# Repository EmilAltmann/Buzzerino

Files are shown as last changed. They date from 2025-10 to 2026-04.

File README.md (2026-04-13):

# Buzzerino

This is the repository of the soldering kit by the Digital Technology Group at the University of Kassel.



The contents of this document:
* [Soldering Instructions](#soldering-instructions)
* [Flashing](#flashing)
* [Example Programs](#example-programs)
* [How to Code / Work with AI](#how-to-code-and-work-with-ai)
* [Parts and Wiki](#parts-and-wiki)

## Soldering Instructions

We created a short video about the assembly process:

<a href="http://www.youtube.com/watch?feature=player_embedded&v=cFA2UIF0SY8?si=ucTLQL97WAnX6xTo
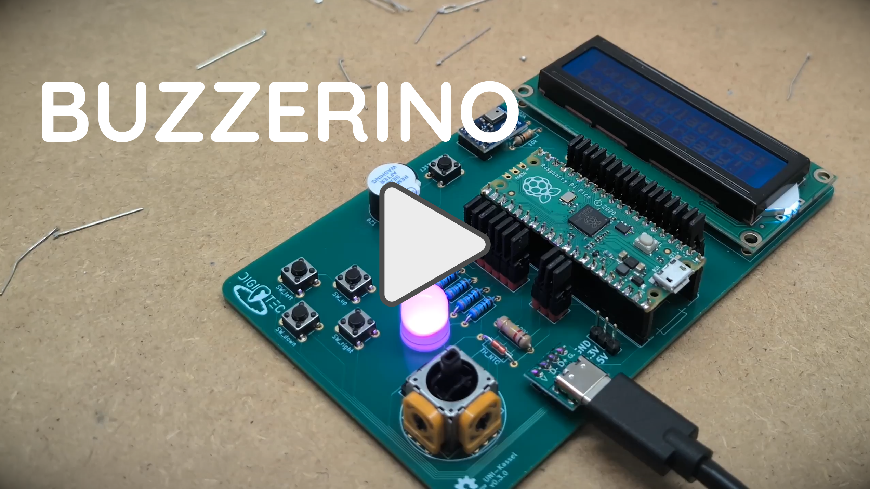
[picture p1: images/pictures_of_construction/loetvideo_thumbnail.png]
Assembly Video
" target="_blank"></a>

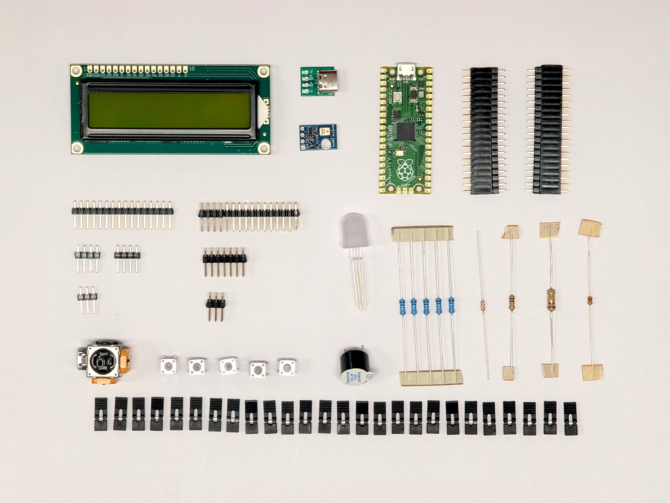
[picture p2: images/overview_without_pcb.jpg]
Parts of the Buzzerino.


### Bill of Materials
Please check if you have all the necessary components listed below:
* 1x Buzzerino circuit board (Buzzerino PCB)
* 1x Raspberry Pi Pico
* 1x 1602A LCD display
* 1x AHT10 digital temperature and humidity sensor
* 1x USB-C breakout board
* 1x 10 mm RGB LED
* 1x buzzer
* 1x analogue joystick
* 5x 6 mm push buttons
* 1x 100 kΩ NTC temperature-dependent resistor
* 5x 330 Ω resistors
* 1x 1 kΩ resistor
* 1x 10 kΩ resistor
* 1x 120 kΩ resistor
* 2x 1x20 pin headers and sockets (keep them plugged together)
* 1x 1x16 pin header
* 2x 1x4 pin headers
* 1x 1x3 pin header
* 1x 2x16 pin header
* 1x 2x7 pin header
* 1x 2x3 pin header
* 26x jumper

### Assembly of the Raspberry Pi Pico

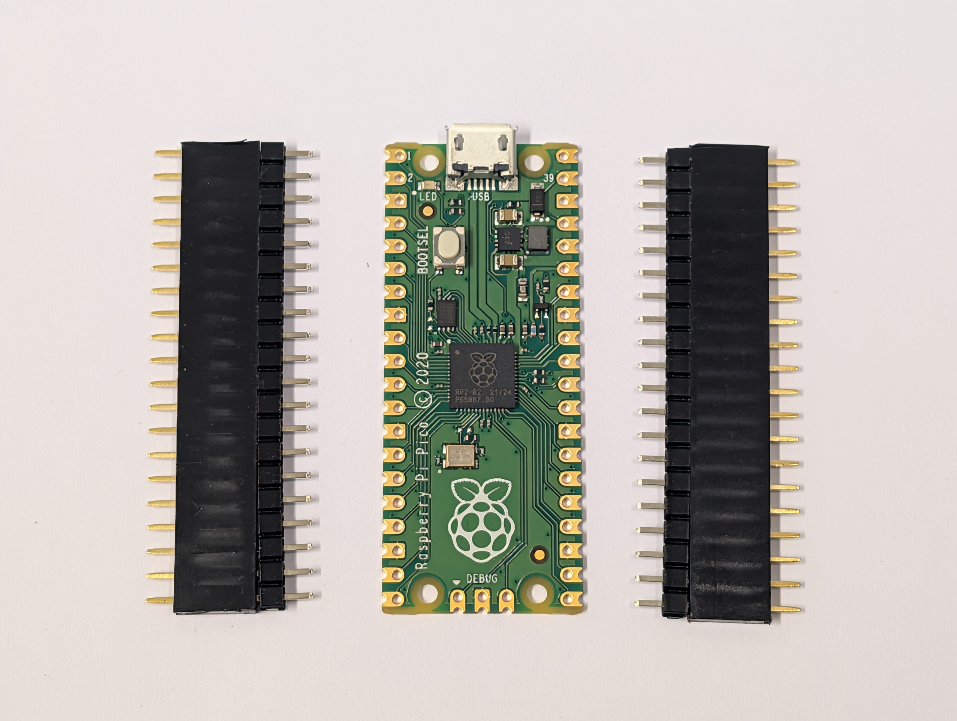
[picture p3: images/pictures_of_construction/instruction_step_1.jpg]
Raspberry Pi Pico and pin strips.


We will start by soldering the two 1x20 pin headers and sockets to the Raspberry Pi Pico board. The pin strips are each two parts plugged together; keep them together, as this will keep the contacts aligned! The side with the slimmer plastic piece will be soldered to the Raspberry Pi Pico (in the picture above, the inner one).

Start by putting the pin headers into the Raspberry Pi Pico and the Buzzerino PCB. The Raspberry Pi Pico should sit flat and parallel on both pin strips.

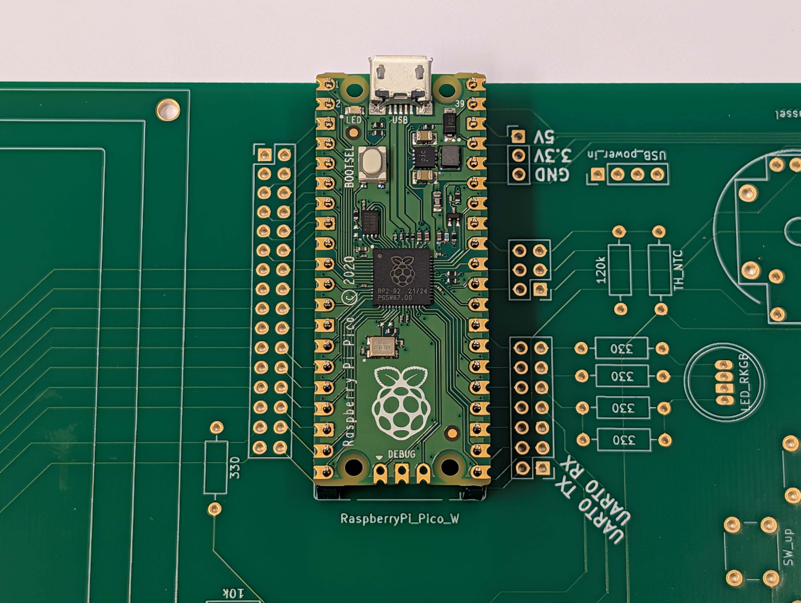
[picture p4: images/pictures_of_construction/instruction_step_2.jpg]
Raspberry Pi Pico sitting loosely on pin strips.


Now we can solder our first connections. Heat one of the corner pins with your soldering iron. Check with solder whether the joint is up to temperature by gently feeding it into the heated pin. If the solder melts, you can remove the soldering iron and let the connection cool down.

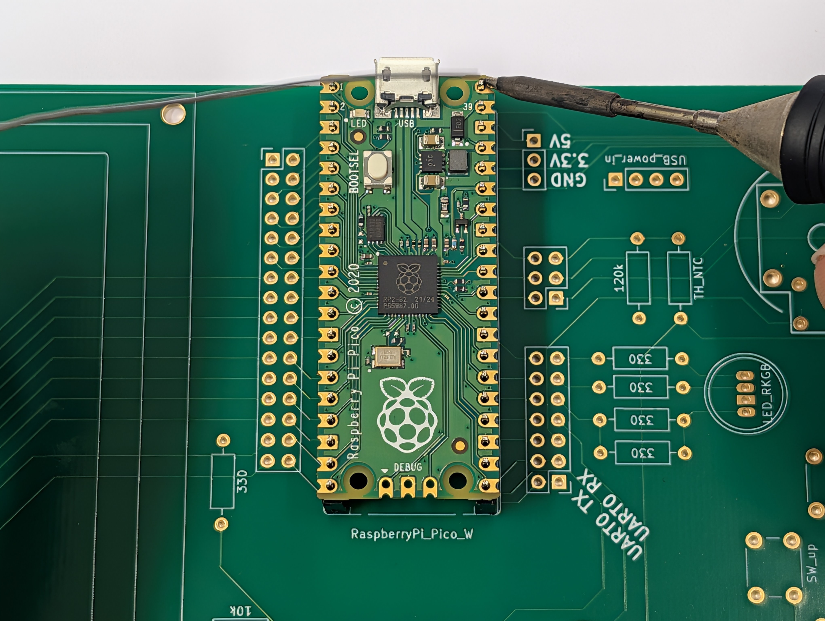
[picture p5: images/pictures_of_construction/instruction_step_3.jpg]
Example of soldering a pin from the Raspberry Pi Pico.


Continue by soldering the three other corners.

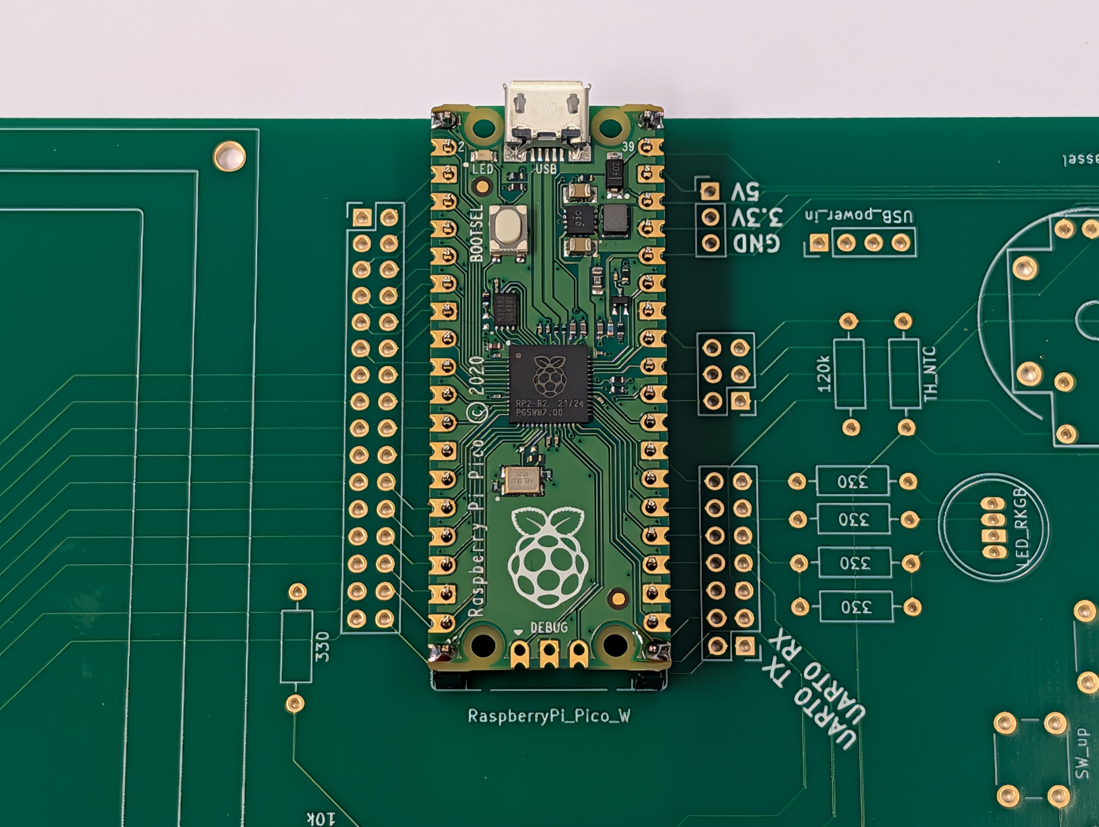
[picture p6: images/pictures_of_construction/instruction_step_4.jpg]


Now you can remove the Raspberry Pi Pico from the Buzzerino PCB (with the pin headers still together).

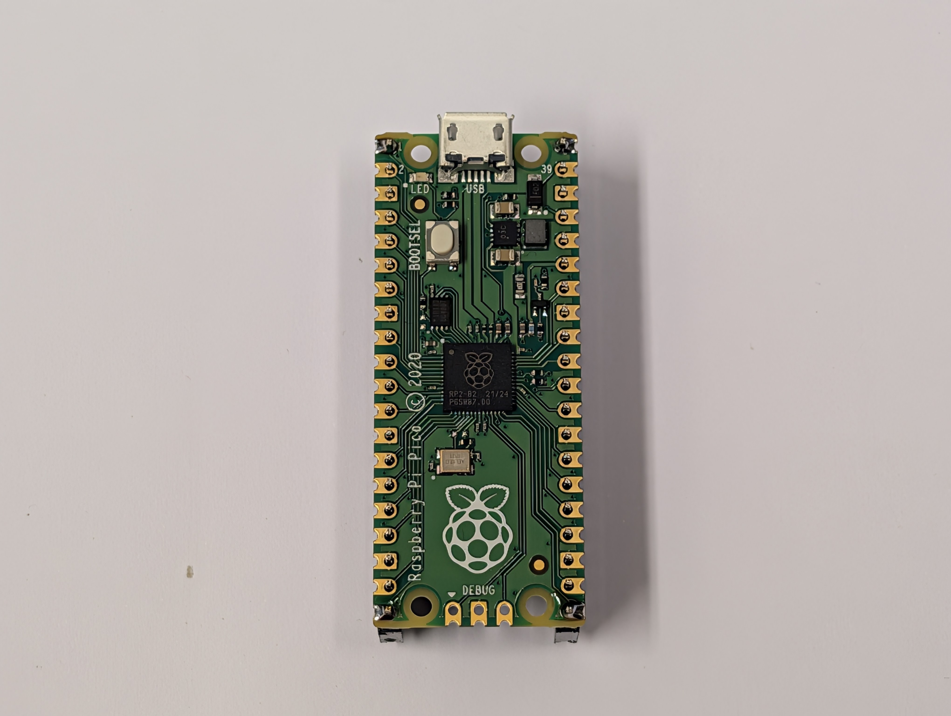
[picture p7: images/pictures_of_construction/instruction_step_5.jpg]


With the Raspberry Pi Pico now free, but the pin strips still attached to it, you can fully solder both sides.

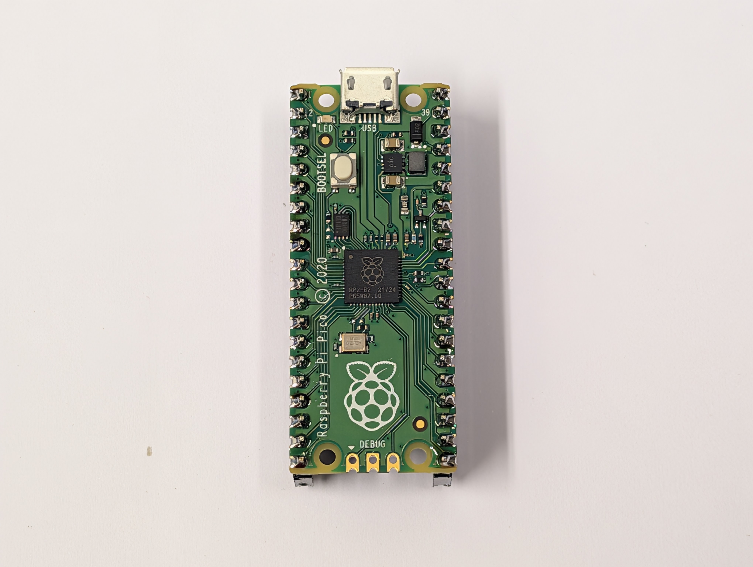
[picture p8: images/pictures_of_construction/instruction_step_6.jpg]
Fully soldered Raspberry Pi Pico.


### Assembly of the USB-C breakout board

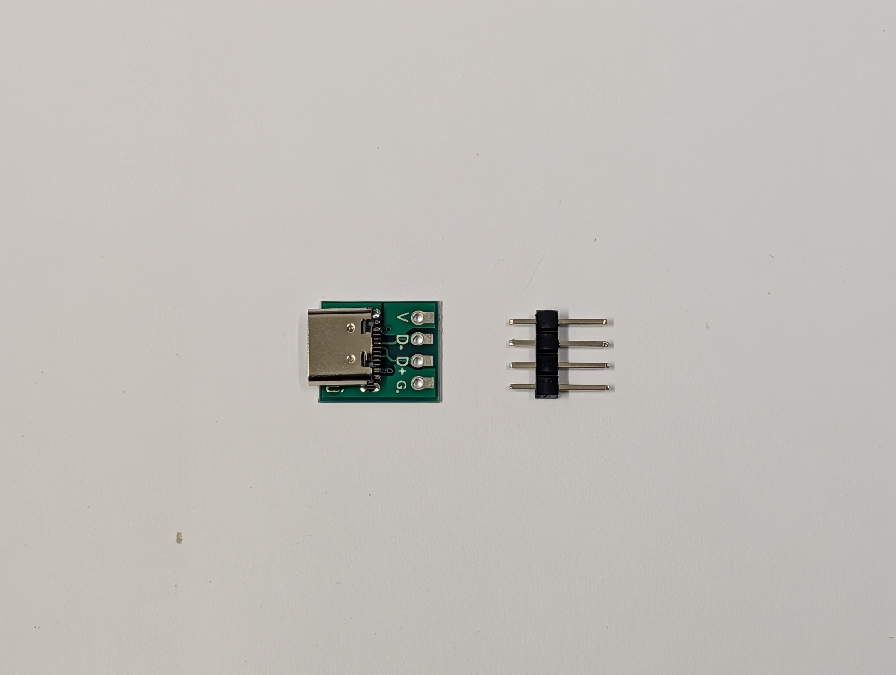
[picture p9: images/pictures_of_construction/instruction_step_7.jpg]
USB-C breakout board and 1x4 pin header.


Now we will solder the 1x4 pin header to the USB-C breakout board. Because both pieces are very small, it's a good tactic to plug them together and place them on your table.

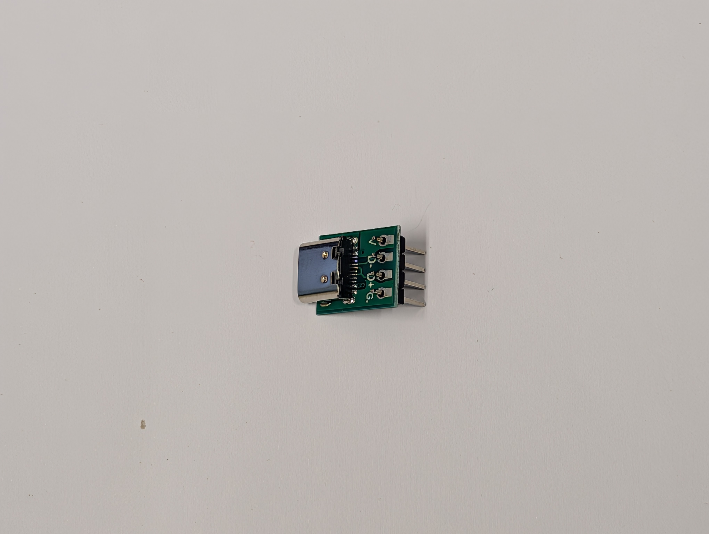
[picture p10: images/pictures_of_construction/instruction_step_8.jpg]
USB-C breakout board and 1x4 pin header loosely plugged together.


Start by soldering only one pin, as the angle between the board and the pin header will likely be slightly crooked.

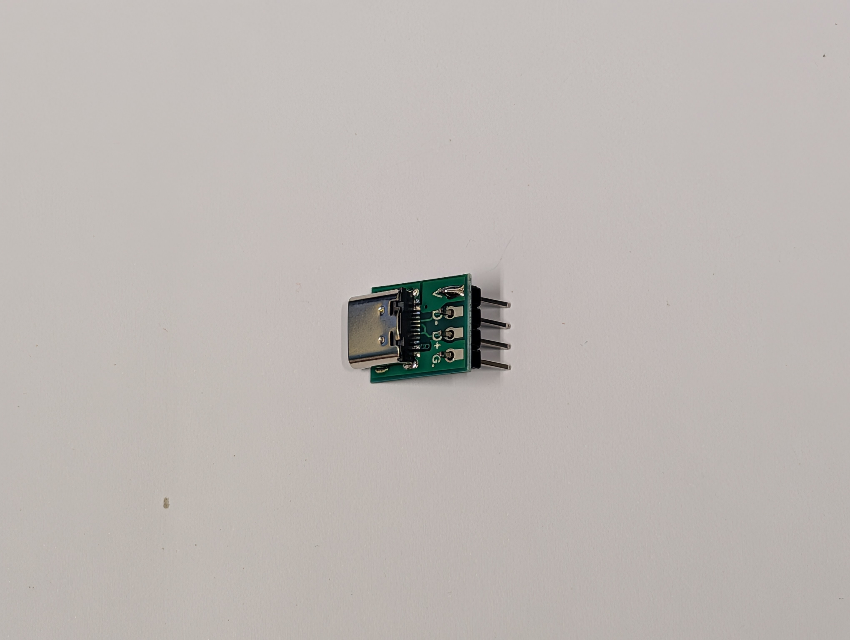
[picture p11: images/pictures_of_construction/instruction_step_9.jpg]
One pin of the USB-C breakout board soldered.


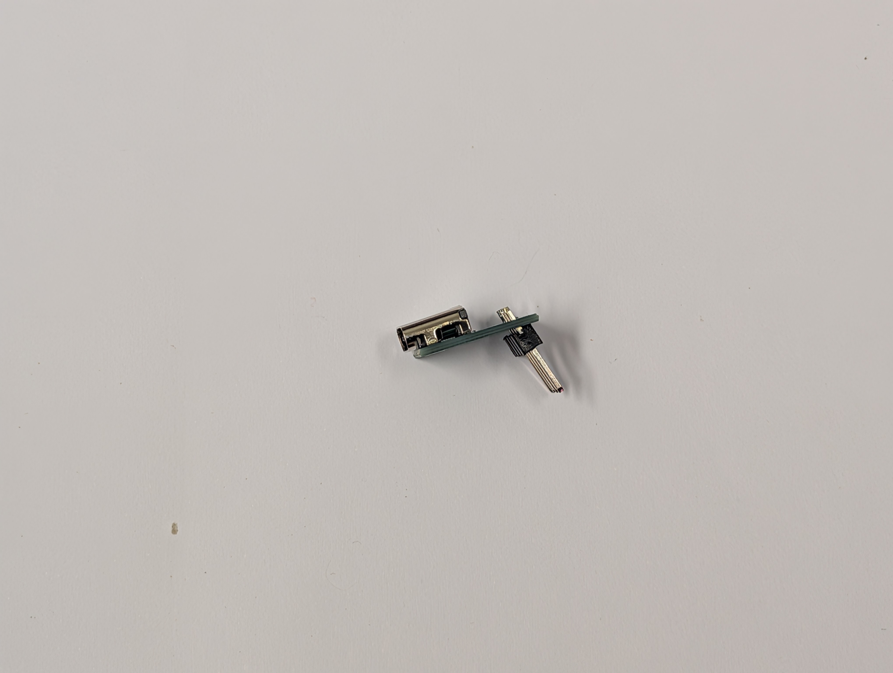
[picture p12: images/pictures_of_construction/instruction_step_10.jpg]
The pin header on the USB-C breakout board will be crooked.


To correct the angle of the pin header, hold both pieces together and carefully reheat the solder joint. Now you can correct any misalignment. Once the pins are perpendicular to the board, solder all four pins.

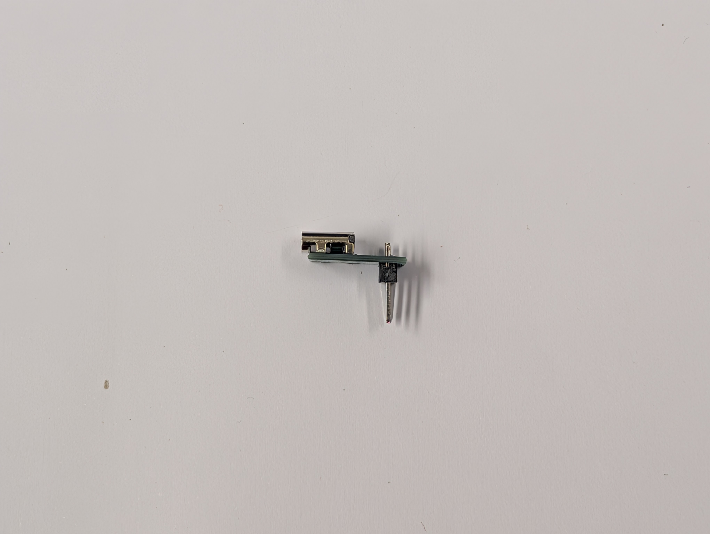
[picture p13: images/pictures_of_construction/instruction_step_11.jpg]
The pin header on the USB-C breakout board fully soldered.


### Assembly of the AHT10 digital temperature sensor

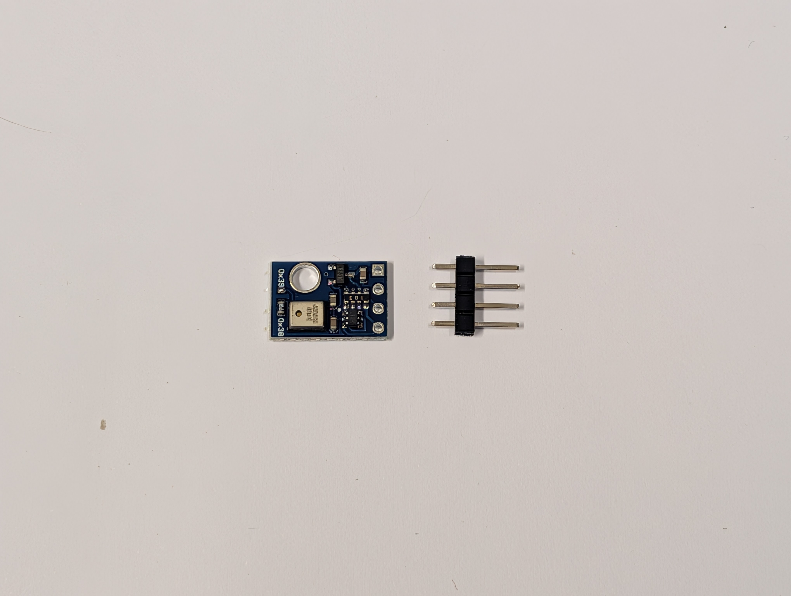
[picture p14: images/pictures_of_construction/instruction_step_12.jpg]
AHT10 and pin header side by side.


The assembly of the AHT10 digital temperature sensor is identical to that of the USB-C breakout board. Start by soldering only one pin and correct the alignment so it is nice and perpendicular.

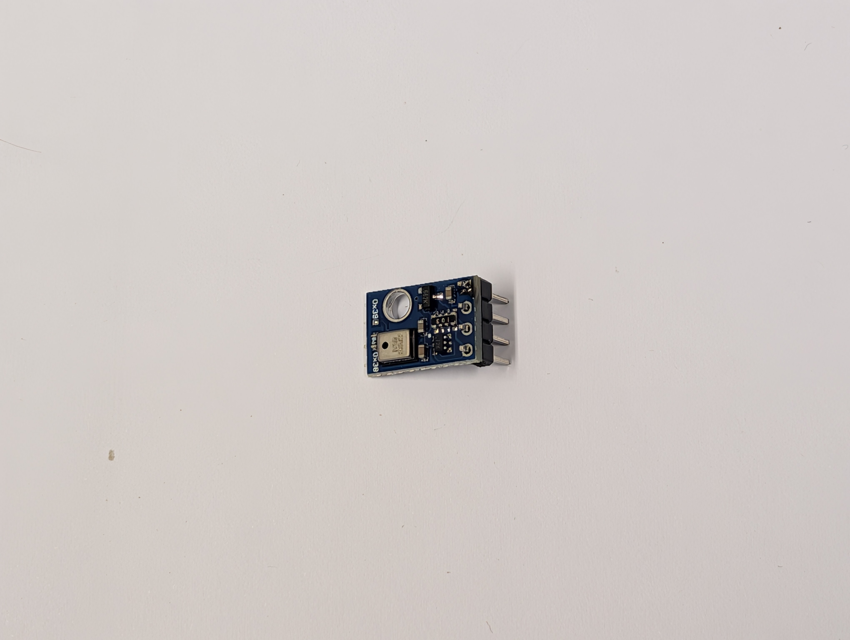
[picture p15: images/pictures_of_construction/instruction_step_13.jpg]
AHT10 fully soldered.


### Assembly of the 1602A LCD display

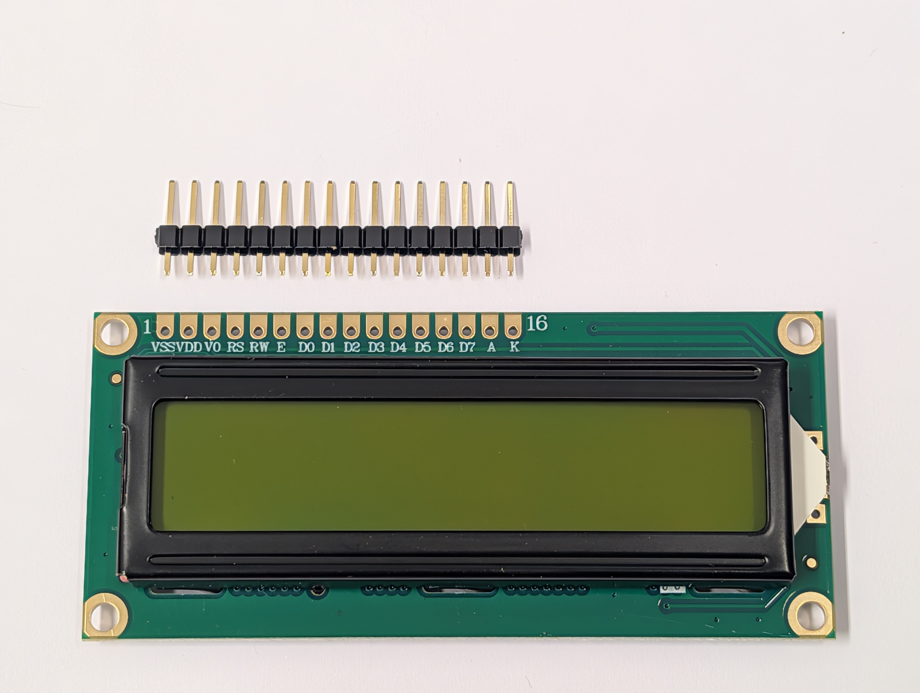
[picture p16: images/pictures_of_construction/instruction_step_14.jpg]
1602A LCD and pin header side by side.


The assembly of the 1602A LCD display is very similar to the previous two steps. First solder one pin, check for squareness and correct, then solder all pins.

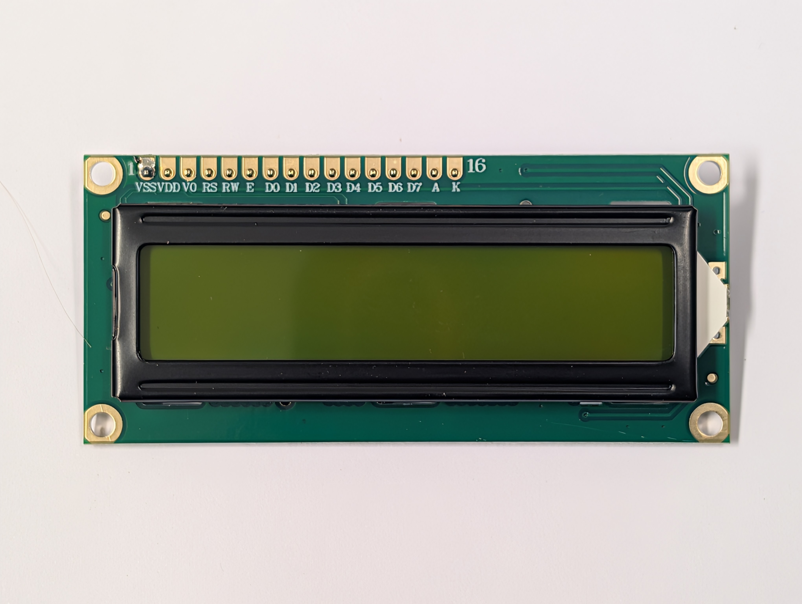
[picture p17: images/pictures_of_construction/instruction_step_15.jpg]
1602A LCD and pin header soldered by one pin.


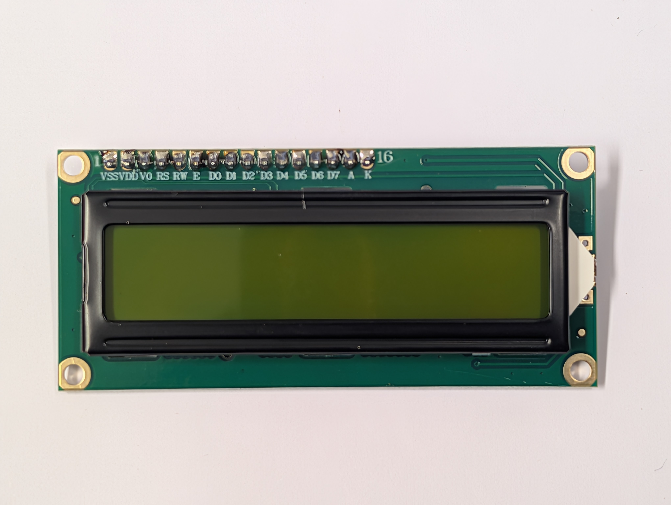
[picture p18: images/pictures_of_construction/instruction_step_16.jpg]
1602A LCD and pin header fully soldered.


### Installation of resistors
#### 100 kΩ NTC temperature-dependent resistor

The 100 kΩ NTC temperature-dependent resistor has a glass body with no markings.

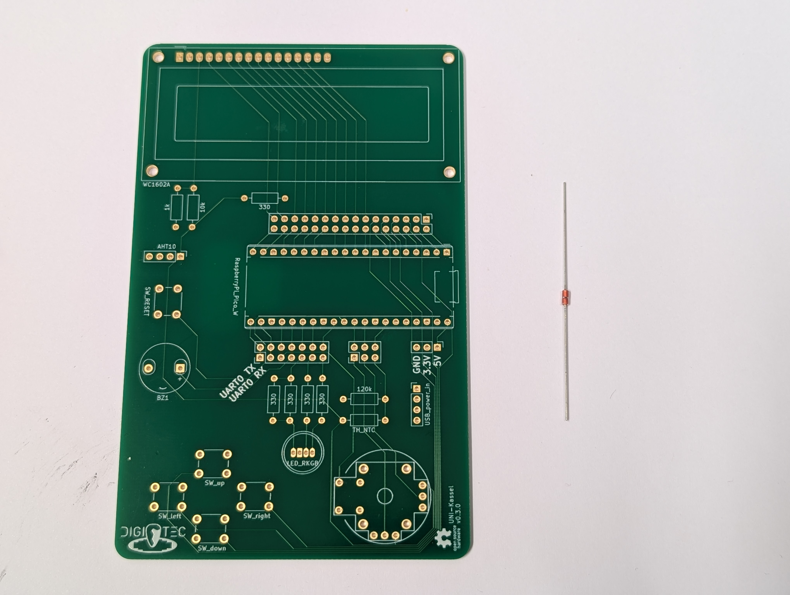
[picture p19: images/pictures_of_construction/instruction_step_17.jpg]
Buzzerino PCB and NTC Resistor side by side.


The resistors come with straight leads and need to be formed. For that purpose hold them with one hand between two fingers and pull them to a U-shape with your other hand as seen in the following pictures:

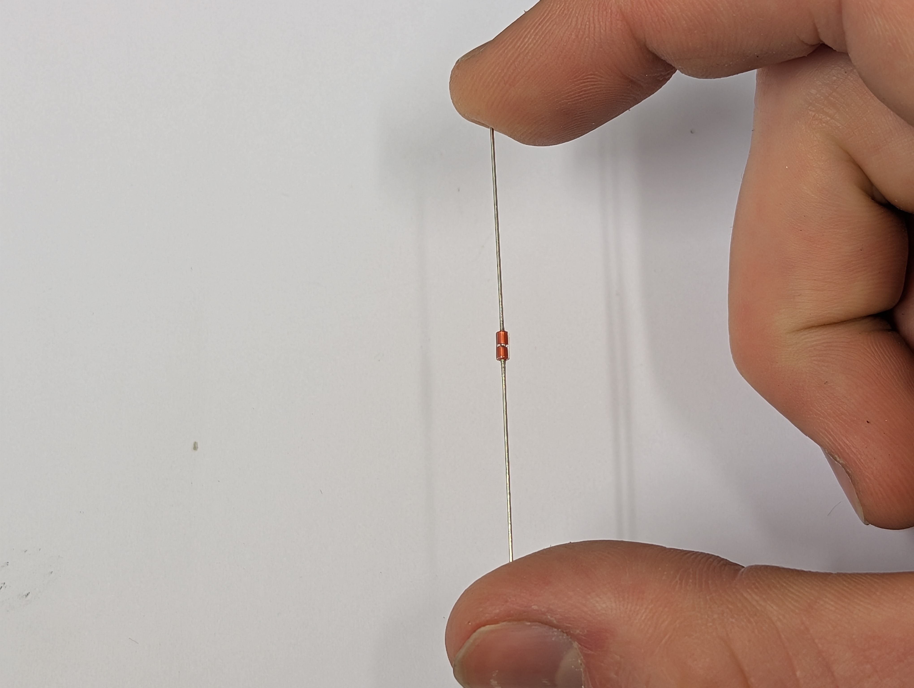
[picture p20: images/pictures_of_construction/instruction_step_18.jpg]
Forming of the resistor leads by hands 1.


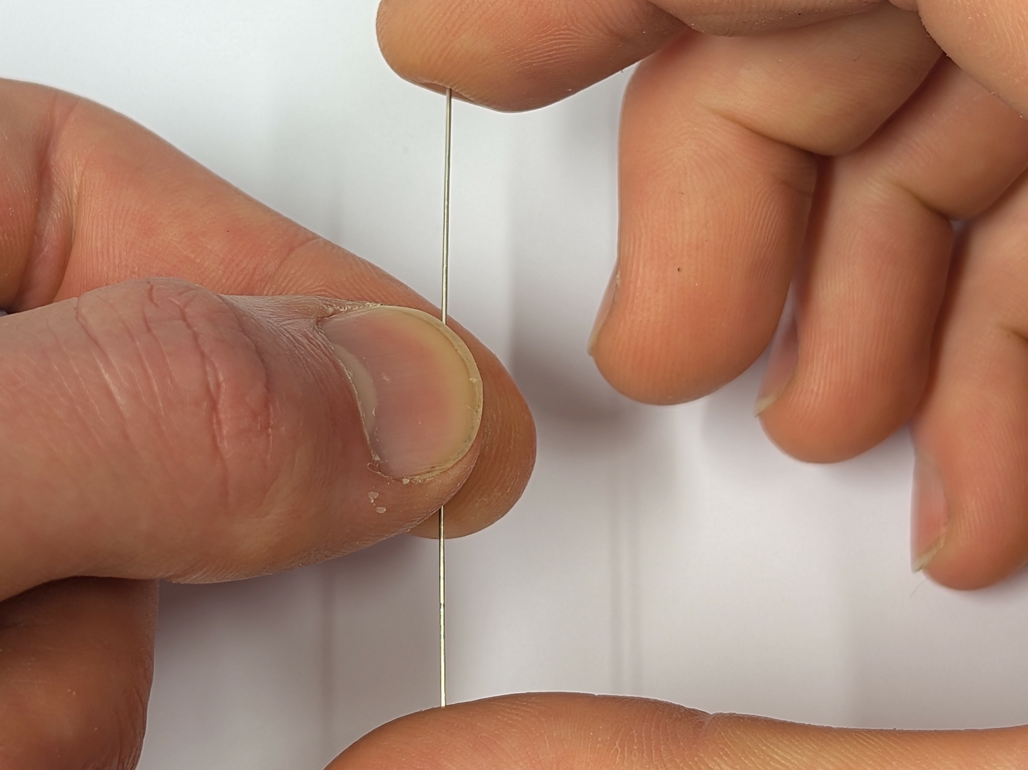
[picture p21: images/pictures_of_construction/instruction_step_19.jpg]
Forming of the resistor leads by hands 2.


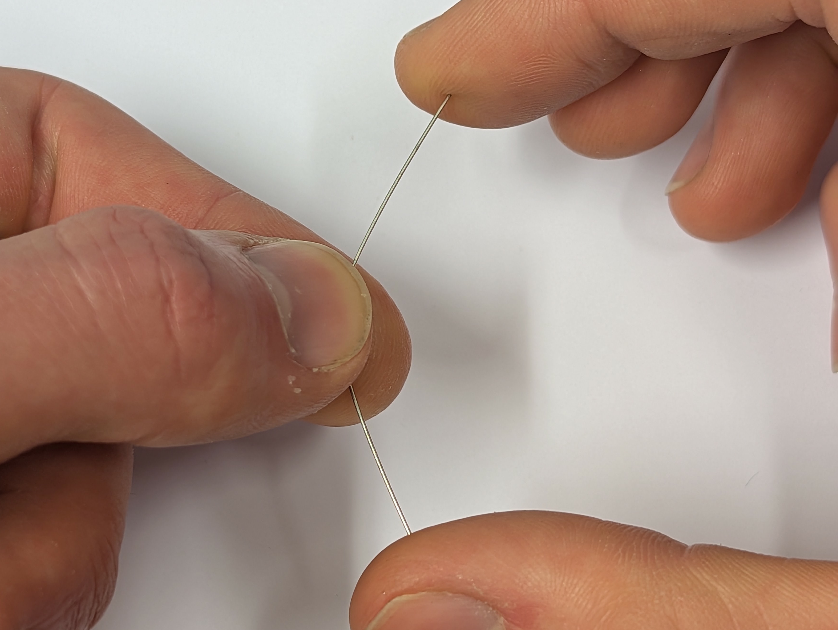
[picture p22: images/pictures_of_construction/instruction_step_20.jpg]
Forming of the resistor leads by hands 3.


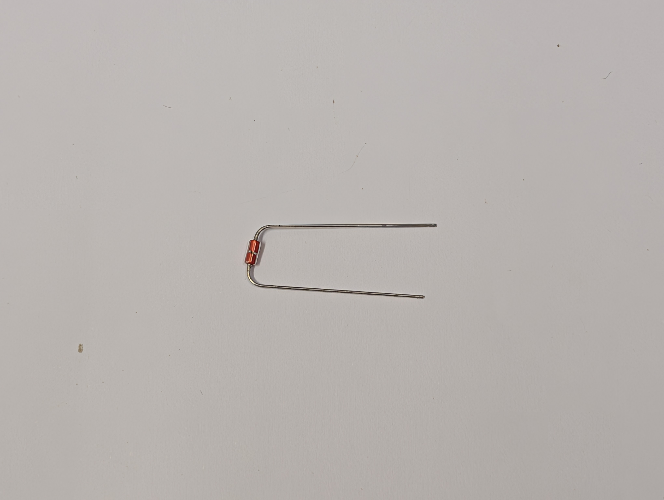
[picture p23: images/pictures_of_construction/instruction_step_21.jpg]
Fully formed resistor leads.


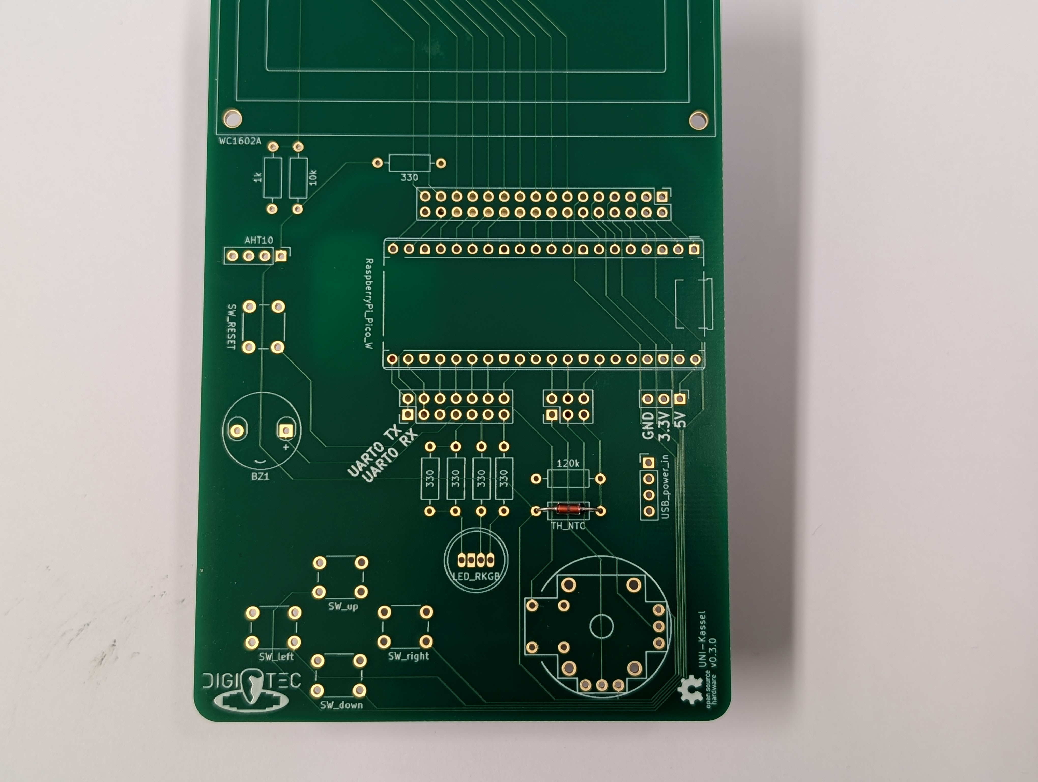
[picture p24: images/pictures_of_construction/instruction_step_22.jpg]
The NTC position on the PCB.


The newly formed resistor can now be inserted into the Buzzerino PCB at the position marked TH_NTC.
**Important:** The printed side of the Buzzerino PCB is the front of the PCB. The lower left corner should have our DIGETEC logo!

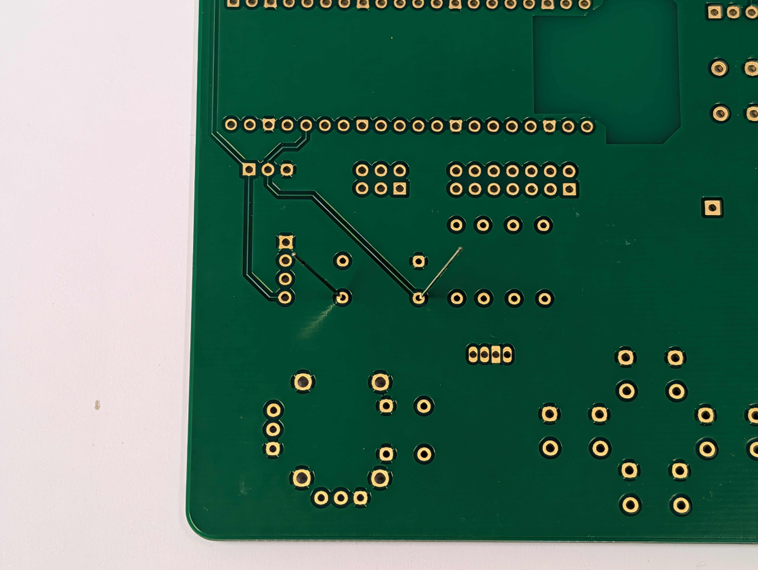
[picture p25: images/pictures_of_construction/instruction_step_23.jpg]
The NTC with slightly bent leads.


As a tip for soldering beginners, you can slightly bend the leads outwards after fully seating the resistor. This will help keep it in place.

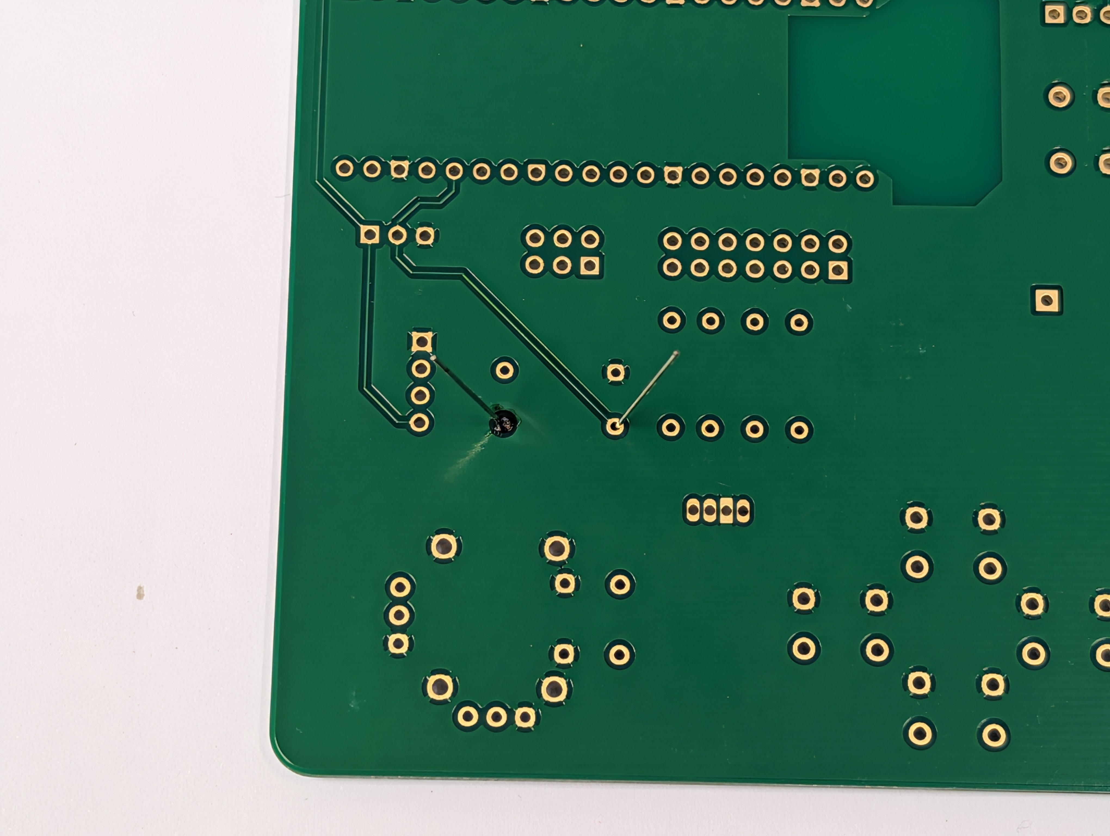
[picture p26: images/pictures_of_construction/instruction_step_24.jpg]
The NTC soldered by one leg.


Like the previous solder joints, it's good practice to start by soldering one lead first, then correct the positioning, and finally solder both.

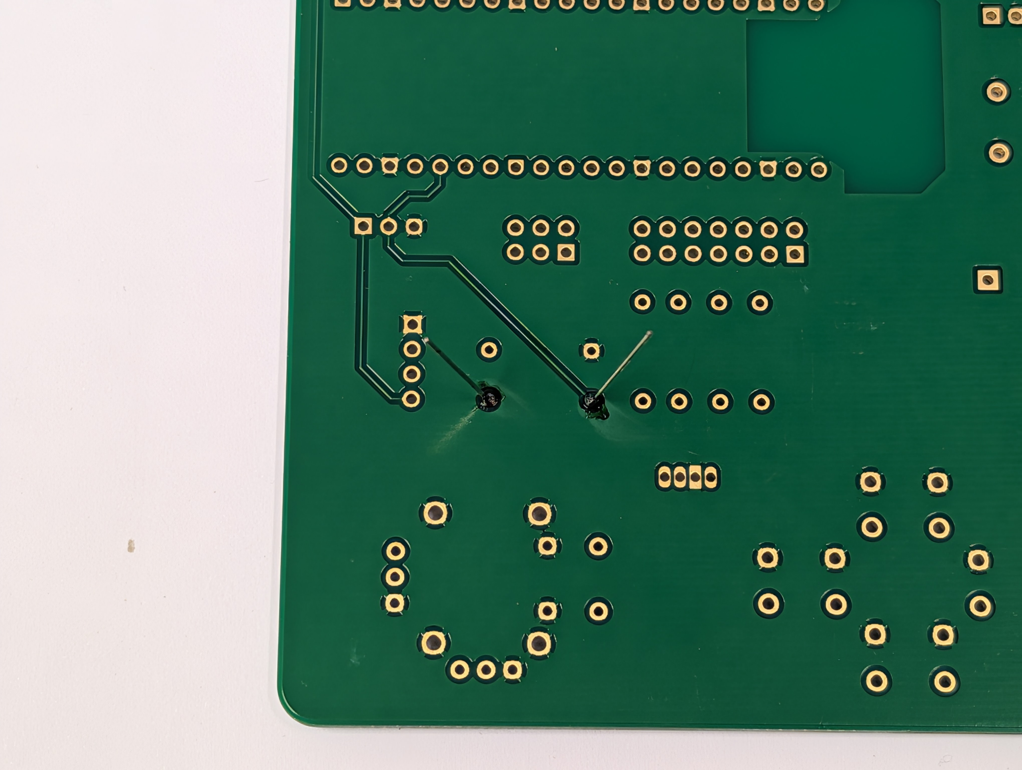
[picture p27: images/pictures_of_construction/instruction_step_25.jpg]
The fully soldered NTC.


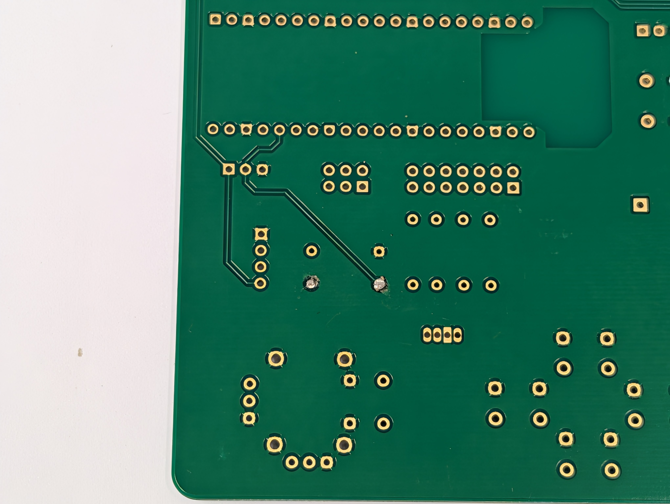
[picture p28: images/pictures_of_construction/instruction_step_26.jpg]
The NTC with clipped soldering joints.


After the resistor is fully seated, you can clip the leads flush with side cutters.

#### 1 kΩ resistor

The 1 kΩ resistor has stripes as markings (Brown | Black | Red | | Gold).

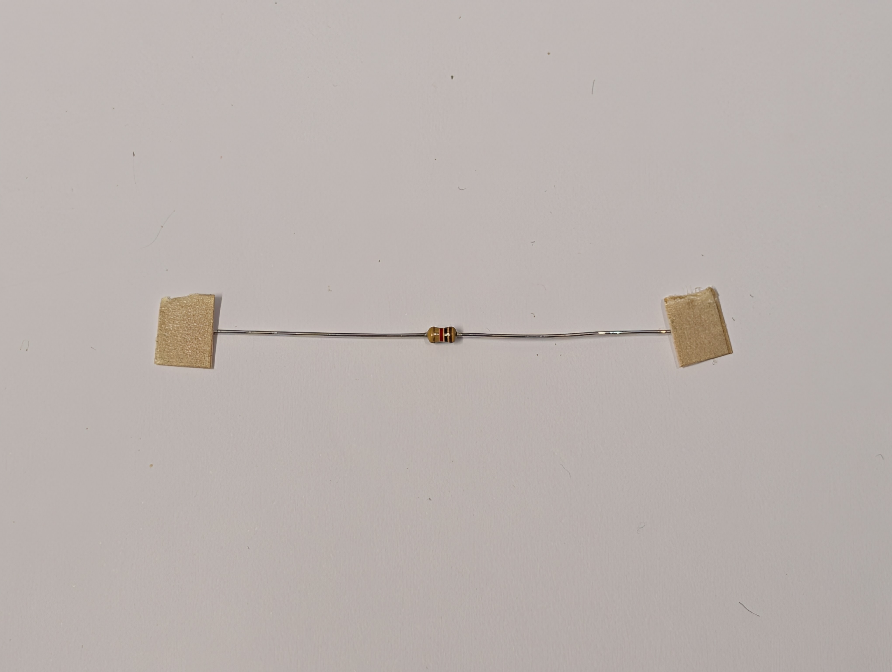
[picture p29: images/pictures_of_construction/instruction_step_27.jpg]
The 1 kΩ resistor.


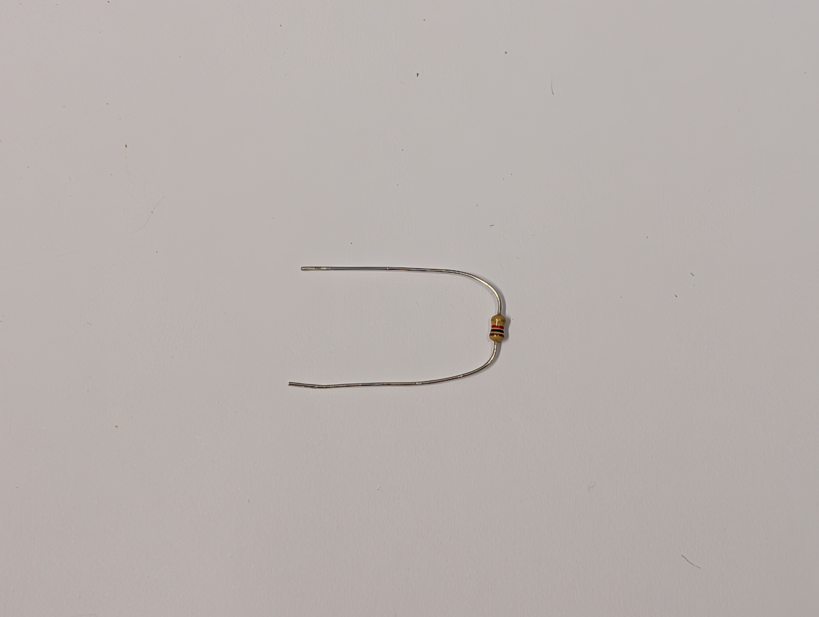
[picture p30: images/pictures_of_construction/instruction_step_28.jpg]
The 1 kΩ resistor formed.


The installation of the different resistors is essentially identical. For the 1 kΩ resistor, start by forming it roughly U-shaped.

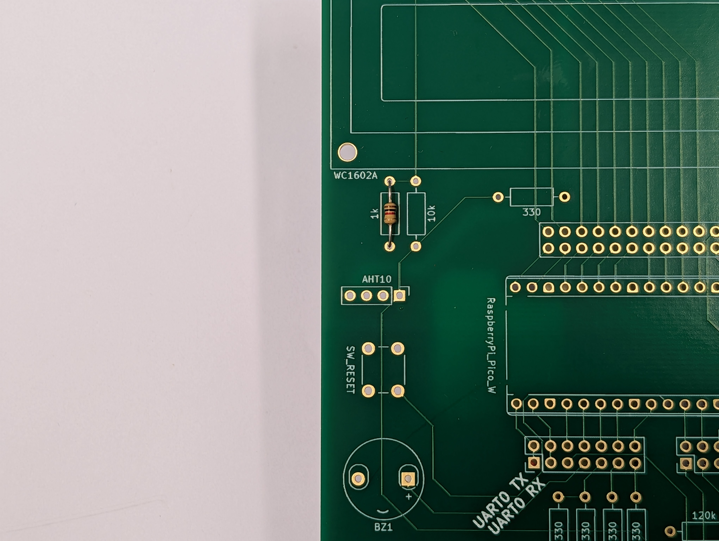
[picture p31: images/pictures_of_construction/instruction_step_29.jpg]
The 1 kΩ resistor position.


Then place it in its position, solder one leg, correct the placement, solder completely, and clip the leads flush.

#### 10 kΩ resistor

The 10 kΩ resistor has stripes as markings (Brown | Black | Orange | | Gold).

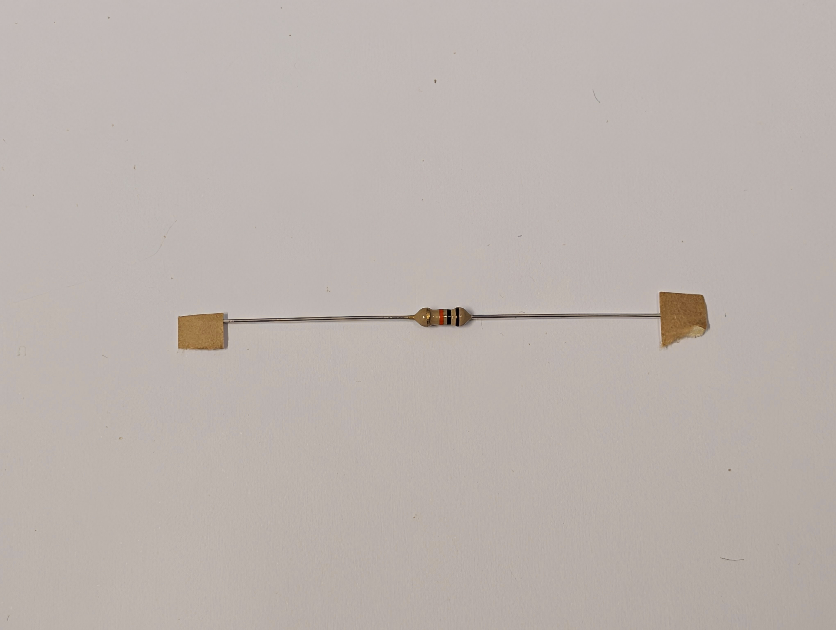
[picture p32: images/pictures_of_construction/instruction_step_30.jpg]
The 10 kΩ resistor.


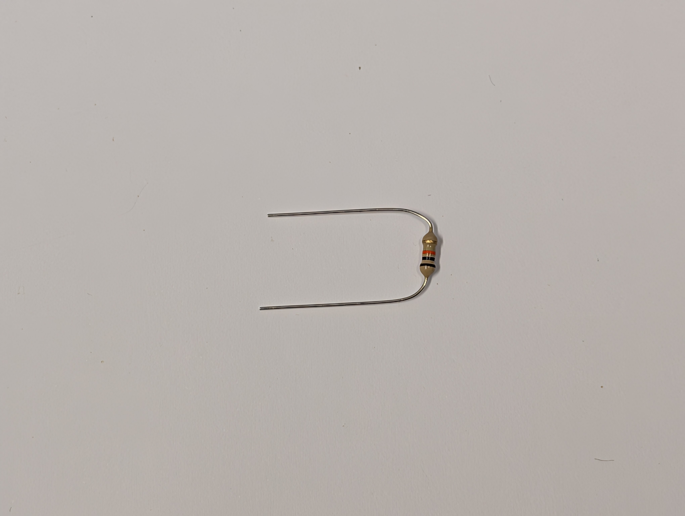
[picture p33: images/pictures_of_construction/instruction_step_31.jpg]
The 10 kΩ resistor formed.


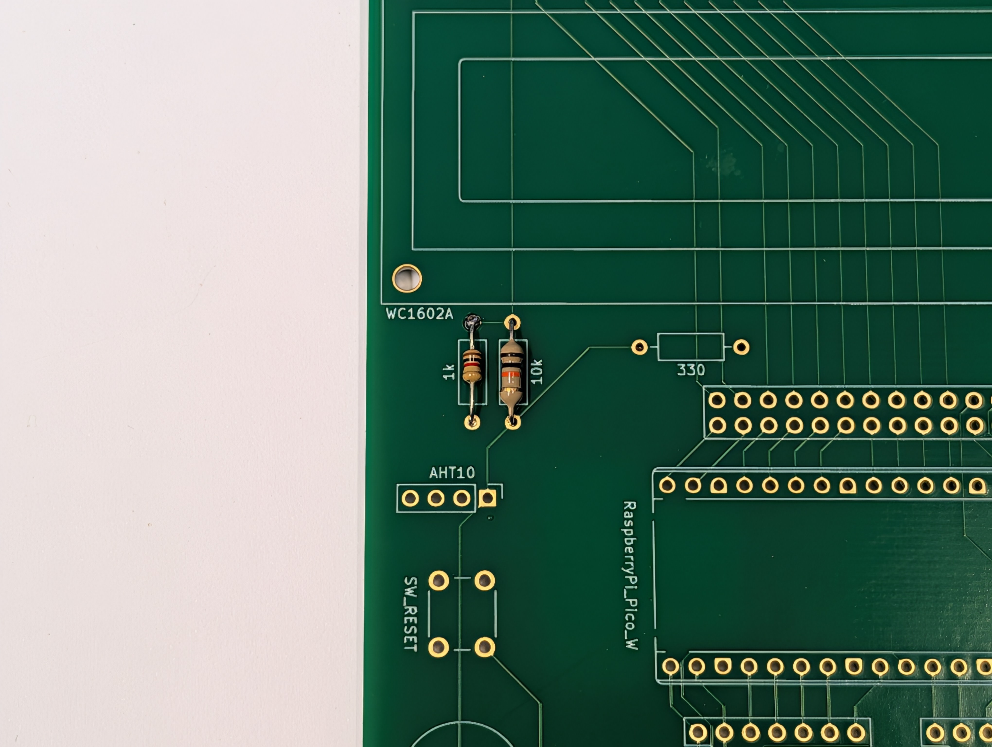
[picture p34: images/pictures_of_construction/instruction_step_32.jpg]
The 10 kΩ resistor position.


For the 10 kΩ resistor: form, place, solder one leg, correct, solder fully, and clip flush.

#### 330 Ω resistors

The 330 Ω resistors hve stripes as markings (Orange | Orange | Black | Black | Brown).

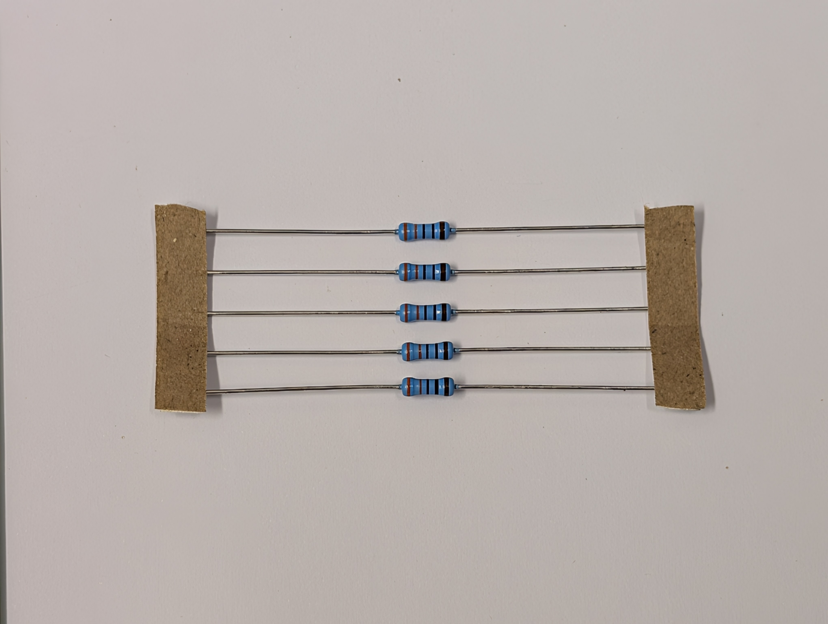
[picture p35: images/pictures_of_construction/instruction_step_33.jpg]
The 330 Ω resistors.


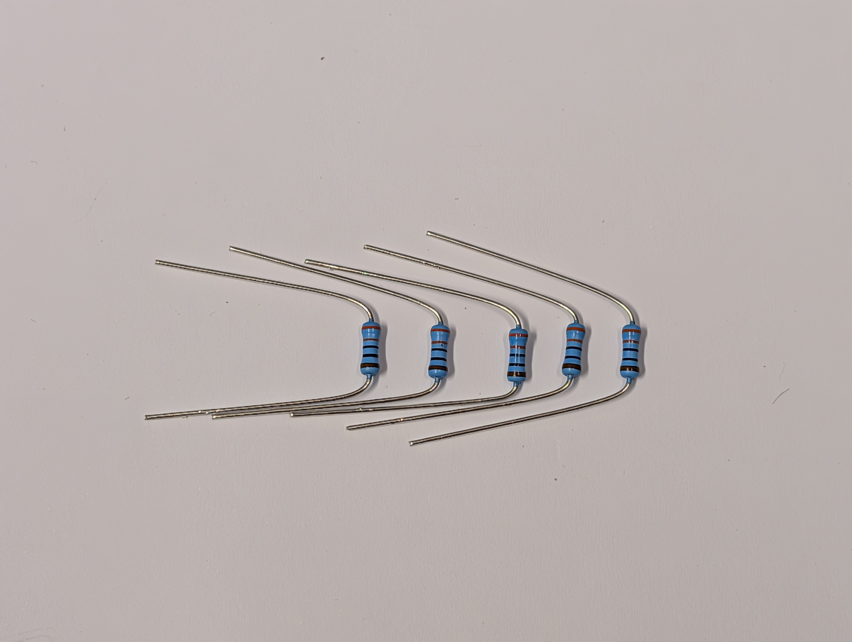
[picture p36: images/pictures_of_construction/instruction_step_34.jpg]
The 330 Ω resistors formed.


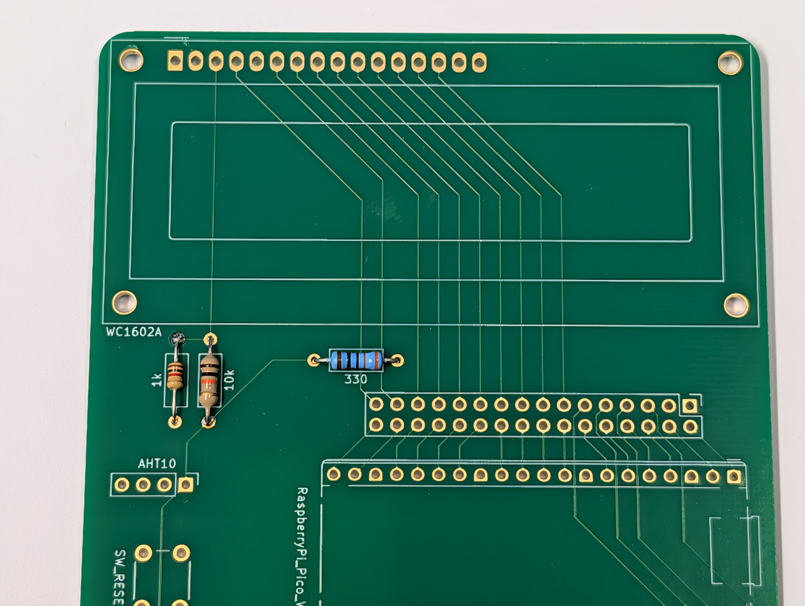
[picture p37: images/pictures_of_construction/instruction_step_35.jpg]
The first 330 Ω resistor position.


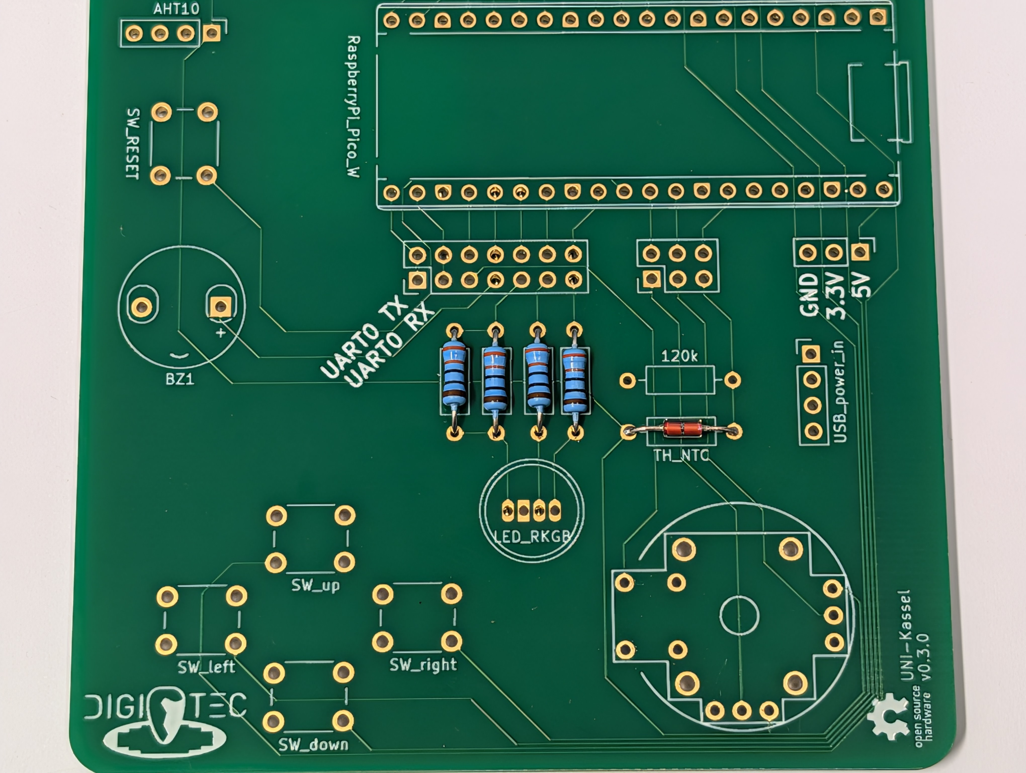
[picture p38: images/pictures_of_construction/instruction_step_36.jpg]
The further 330 Ω resistor positions.


For the 330 Ω resistors: form, place, solder one leg, correct, solder fully, and clip flush.

#### 120 kΩ resistor

The 120 kΩ resistor has stripes as markings (Brown | Red | Yellow | | Gold).

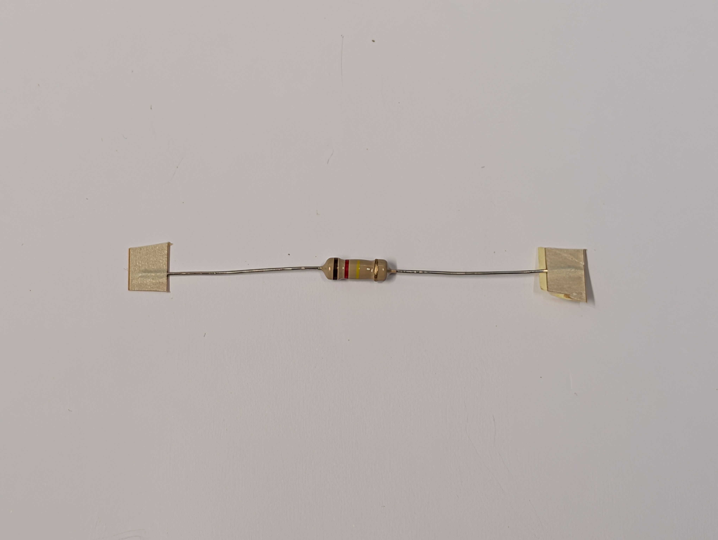
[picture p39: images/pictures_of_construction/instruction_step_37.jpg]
The 120 kΩ resistor.


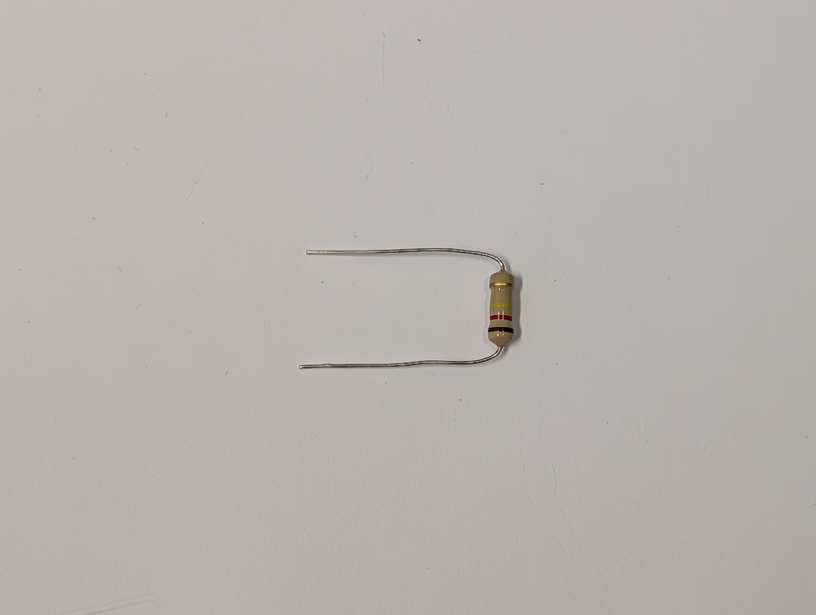
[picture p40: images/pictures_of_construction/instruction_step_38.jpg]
The 120 kΩ resistor formed.


The 120 kΩ resistor position.

For the 120 kΩ resistor: form, place, solder one leg, correct, solder fully, and clip flush.

### Installation of the buttons

The five push buttons.

For the assembly of the Buzzerino PCB, we will go from the shortest to the highest component. This helps you successfully solder your board.

The position of the reset button.

The fully seated reset button in side view.

The shape of the button legs is designed to snap into the Buzzerino PCB. After placing the buttons, check if they sit flush to the Buzzerino PCB. Then solder and clip the leads.

The position of the D-pad buttons.

With the D-pad buttons it's the same procedure as with the reset button.

### Soldering the pin header

**Repeated Error: The short side shall go through the board!**

The 2x7 pin header.

The 2x7 pin header position.

We start by soldering the 2x7 pin header to the Buzzerino PCB. **The short side shall go through the board.**

The 2x7 pin header soldered by one pin.

As with all the previous solder joints, it's best practice to first solder one pin and then check for alignment. The wider pin header will often move a bit out of the Buzzerino PCB and may need to be reseated. Only after the pin headers are placed completely in position should you solder the remaining pins.

The 2x3 pin header.

The 2x3 pin header position.

The 2x16 pin header.

The 2x16 pin header position.

Repeat the previous step for the 2x3 and 2x16 pin headers. Start by soldering one pin, then check and correct the seating, and then solder completely.

The 1x3 pin header.

The 1x3 pin header position.

The 1x3 pin header is one of the fiddliest to install. With all the previous practice, you will be able to solder it flush and perpendicular.

### Installation of the USB-C breakout board

The prepared USB-C breakout board.

The position of the USB-C breakout board.

The USB-C breakout board soldered by one pin.

Side view onto the USB-C breakout board.

Now we can solder the USB-C breakout board. After placing it into position (right side of the Buzzerino PCB, facing outwards, the usb port shuld be fully visible), solder one pin. Then check for alignment; it should be parallel to the Buzzerino PCB. Then solder it completely.

**WARNING:** The pins of the USB-C breakout board, the AHT10 temperature sensor, and the 1602A LCD display are too hard for electronics side cutters! Use larger wire cutters as provided.

### Installation of the AHT10 digital temperature sensor

The prepared AHT10 digital temperature sensor.

The position of the AHT10 digital temperature sensor.

The installation of the AHT10 digital temperature sensor is analogous to the USB-C breakout board (Position left side of the Buzzerino PCB, facing upwards, the components of the sub-PCB sould be visible). But remember: use the larger wire cutters for cutting the pins to length.

### Installation of the Buzzer

The buzzer.

The position of the buzzer.

Finally, we can install the namesake of the board. This is our first polarized component. The footprint on the Buzzerino PCB shows a small +. Furthermore, the sticker on the buzzer has a plus on its top. These should be aligned. (If you look from the front of the Buzzerino PCB, the plus will be facing inwards.) Moreover, if you are unsure, you can check the buzzer's leads: one of them is longer than the other. This is the positive lead and shall align with the plus symbol on the Buzzerino PCB.

### Installation of the 1602A LCD display

The prepared 1602A LCD display.

The position of the 1602A LCD display.

The 1602A LCD display soldered by one pin.

Side view onto the 1602A LCD display.

The installation of the 1602A LCD display is analogous to the USB-C breakout board. First place, then solder one pin, then check for alignment and then solder fully. But remember: use the larger wire cutters for cutting the pins to length.

### Installation of the RGB LED

The RGB LED.

Now we can install the RGB LED.

Position and rotation of the RGB LED.

Fully seated RGB LED.

The LED is, like the buzzer, polarized. But here the longest leg is the negative connection. The footprint on the Buzzerino PCB indicates the negative connection with a square pad. Place the LED into its position. The spacing of the pads is a bit wider than the lead spacing, so the leads will spread out automatically.

RGB LED leads cropped.

Reflow RGB LED solder joints.

Cleaned up RGB LED solder joints.

After soldering and cutting the RGB LED's leads flush, you will probably have a very ugly joint. Luckily, you can easily correct this by slowly running your soldering iron between two pins and letting them reflow. The surface tension of the solder should pull the joint nicely together, resulting in a clean joint. But check for any bridges after that! If there are any, clean your soldering tip and repeat the reflow.

### Installation of the Raspberry Pi Pico

The prepared Raspberry Pi Pico.

The position of the Raspberry Pi Pico.

The Raspberry Pi Pico tacked into place.

Now we can install the Raspberry Pi Pico. As with all previous complex connections, start by soldering only two opposite pins. Then check for alignment; after that, solder completely.

### Installation of the analogue joystick

The analogue joystick.

The analogue joystick position.

As the last component, we will install the analogue joystick.

Installation of the analogue joystick.

Side view of the fully seated analogue joystick.

The installation of the joystick can be harder than necessary because of the many different pins. Start by putting the push-button pins into the Buzzerino PCB and then wiggle each pin from left to right slowly into position. After the joystick is fully seated, you can solder it in place.

Everything soldered in place.

### Installation of the jumpers

Installed jumpers.

Before testing the board, we need to install all 26 jumpers as seen in the picture above.

**Congratulations, you have finished your soldering project.**

If you already flashed your Raspberry Pi Pico, it's time to power it up; if not, flash the self_test.uf2 onto the board.

## Flashing

If the board is not connected to a power source:
Press and hold the BOOTSEL button on the Raspberry Pi Pico and connect it via micro-USB to a PC. The Pico should mount as a mass-storage device called RPI-RP2. Now you can drag and drop a previously compiled or downloaded .uf2 file onto it. It will automatically unmount and reboot. Ignore the message from your PC that the device was disconnected without ejecting.
You don't need to unplug and replug the Raspberry Pi Pico every time you want to flash it. You can also, with an established connection to your PC, press and hold the BOOTSEL button on the Raspberry Pi Pico and then briefly press (while still holding the BOOTSEL button) the SW_RESET button on the Buzzerino PCB.

## Example Programs

The code of the example programs and their .uf2 files are available in the folder example_programs. Unless otherwise noted, all programs are designed and compiled for the Raspberry Pi Pico (neither the W version nor version 2) but can be recompiled for these targets. The preferred way to compile is VS Code with the Raspberry Pi Pico extension.

## How to Code and Work with AI

You can code the Raspberry Pi Pico using the Arduino IDE or Microsoft Visual Studio Code (VS Code) with the Raspberry Pi Pico extension. If you use the Arduino IDE, you need to install the necessary board support as described in the [blog post from Random Nerd Tutorials](https://randomnerdtutorials.com/programming-raspberry-pi-pico-w-arduino-ide/).
We provide a comprehensive AI guidance document for users who want to use AI tools for programming, installation, or debugging. You can include the [AI_GUIDELINES.md](https://github.com/EmilAltmann/Buzzerino/blob/main/AI_GUIDELINES.md) file in your conversation with a chat-based AI assistant and ask it to follow the instructions closely.

If possible, we recommend attaching the document directly to the conversation rather than pasting only parts of it. This helps ensure that the AI still has access to the full context and instructions, even in longer conversations.

## Parts and Wiki

### Raspberry Pi Pico
The core of the whole board is a [Raspberry Pi Pico microcontroller](https://www.raspberrypi.com/products/raspberry-pi-pico/). It can be programmed as described in the [How to Code](#how-to-code) section. The SW_RESET button to the left of the microcontroller can be used to reset the microcontroller.

### 1602A LCD display
The display is a 16-character by 2-row LCD. It is connected via a parallel bus to the Raspberry Pi Pico. The [datasheet](https://www.openhacks.com/uploadsproductos/eone-1602a1.pdf) explains its function as it is implemented in the example program. Because the display works on 5 V and the Raspberry Pi Pico on 3.3 V, you can only write to the display and the read/write pin is always set to write (tied low).
The pinout is as follows:
| GPIO | LCD |
|---|-----|
| 6 | D7  |
| 7 | D6  |
| 8 | D5  |
| 9 | D4  |
| 10 | D3  |
| 11 | D2  |
| 12 | D1  |
| 13 | D0  |
| 14 | E |
| 15 | RS  |

### AHT10 temperature and humidity sensor
The AHT10 digital temperature and humidity sensor is connected via I2C to the Raspberry Pi Pico. It has the address 0x38 and can be accessed as described in the [datasheet](https://server4.eca.ir/eshop/AHT10/Aosong_AHT10_en_draft_0c.pdf). It is connected to the I2C0 interface on the Raspberry Pi Pico.
The pinout is as follows:
| GPIO | AHT10 |
|---|---|
| 0 | SDA |
| 1 | SCL |

### Buzzer
The buzzer is an active 4.5 kHz buzzer. It is connected to GPIO pin 19 on the Raspberry Pi Pico. Active means it contains a driver and will produce this tone when powered. You can chop the sound using PWM to reproduce different sound effects.

### D-pad buttons
The D-pad buttons can be used as a generic input. They are connected directly to a digital pin of the Raspberry Pi Pico without any filter or pull-up or pull-down resistors. So the internal pull-up resistors need to be activated and debounce logic needs to be implemented in software.
The pinout is as follows:
| GPIO | Button |
|---|---|
| 2 | up |
| 3 | down |
| 4 | left |
| 5 | right  |

### Analogue joystick
The analogue joystick can be used as a fine-grained input. It is connected to the 12-bit analogue-to-digital converter (ADC) of the Raspberry Pi Pico. It has two axes and a push-button. The X-axis measures the up/down angle between 0 (fully down) and 4095 (fully up), the Y-axis measures correspondingly the left/right angle between 0 (fully left) and 4095 (fully right). Due to manufacturing tolerances, the exact midpoint and extrema should be determined experimentally. The push-button is, like the D-pad buttons, directly connected to a digital pin of the Raspberry Pi Pico.
The pinout is as follows:
| GPIO | Joystick |
|---|---|
| 18 | button |
| 31 (ADC0) | X-axis |
| 32 (ADC1) | Y-axis |

### RGB LED
The RGB LED is connected to three pins of the Raspberry Pi Pico. It can be dimmed via the PWM function as seen in the example program.
The pinout is as follows:
| GPIO | LED |
|---|-----|
| 20 | R |
| 21 | G |
| 22 | B |

### 100 kΩ NTC analogue temperature sensor
The 100 kΩ NTC analogue temperature sensor is a second way to measure the temperature of the surroundings. It is connected to the 12-bit analogue-to-digital converter (ADC) of the Raspberry Pi Pico like the potentiometers of the joystick. It is configured in a voltage divider with a 120 kΩ pull-down resistor and a 3.3 V positive connection. The midpoint is connected to pin 28 (ADC2) on the Raspberry Pi Pico. Its B-value is 3950 K and its resistance is 100 kΩ at 25 °C.

### USB-C power connector
The USB-C power connector can be used as an alternative way to power the board. For example, it's necessary if you want to use the Raspberry Pi Pico as a USB host for a keyboard.
**KNOWN ISSUES:** The USB-C connector doesn't completely comply with the standard, so some smart USB chargers don't recognize the board as a valid device. Just use a cable without data connections or try another charger.

### Breakout / Jumper pins
The board has three blocks of jumper pins. They connect the GPIO pins from the Raspberry Pi Pico to the peripherals. The inner row represents the GPIO, the outer the periphery. If you want to disable or reconfigure functions of the board, you can do this by means of jumper cables. Moreover, the board has a 3-pin connector which can be used as a ground and power connection to the 5 V and 3.3 V rails.

### UART Interface
If you want to communicate via a serial interface with the board, you can use UART. There are two options available. The first one is the micro-USB port on the Raspberry Pi Pico, the second is the two pins marked as UART0 TX and UART0 RX. These are connected to the GPIO pins and can be connected to other UART devices or via a USB–serial converter.

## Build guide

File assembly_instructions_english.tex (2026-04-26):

\documentclass[a4paper,11pt]{article}

\usepackage[utf8]{inputenc}
\usepackage[T1]{fontenc}
\usepackage[english]{babel}
\usepackage[a4paper,margin=2.5cm]{geometry}
\usepackage{graphicx}
\usepackage{float}
\usepackage{hyperref}
\usepackage{enumitem}
\usepackage{parskip}
\usepackage{xcolor}

\hypersetup{
    colorlinks=true,
    linkcolor=blue,
    urlcolor=blue
}

\title{Buzzerino}
\author{}
\date{}

\begin{document}

\maketitle

\section*{Contents}
\begin{itemize}
    \item Soldering Instructions
    \item Flashing
    \item Example Programs
    \item How to Code / Work with AI
\end{itemize}

\section*{Soldering Instructions}

\begin{figure}[H]
    \centering
    
\end{figure}

\subsection*{Bill of Materials}

Please check if you have all the necessary components listed below:

\begin{itemize}
    \item 1x Buzzerino circuit board (Buzzerino PCB)
    \item 1x Raspberry Pi Pico
    \item 1x 1602A LCD display
    \item 1x AHT10 digital temperature and humidity sensor
    \item 1x USB-C breakout board
    \item 1x 10 mm RGB LED
    \item 1x buzzer
    \item 1x analogue joystick
    \item 5x 6 mm push buttons
    \item 1x 100 k$\Omega$ NTC temperature-dependent resistor
    \item 5x 330 $\Omega$ resistors
    \item 1x 1 k$\Omega$ resistor
    \item 1x 10 k$\Omega$ resistor
    \item 1x 120 k$\Omega$ resistor
    \item 2x 1x20 pin headers and sockets (keep them plugged together)
    \item 1x 1x16 pin header
    \item 2x 1x4 pin headers
    \item 1x 1x3 pin header
    \item 1x 2x16 pin header
    \item 1x 2x7 pin header
    \item 1x 2x3 pin header
    \item 26x jumper
\end{itemize}

\subsection*{Assembly of the Raspberry Pi Pico}

\begin{figure}[H]
    \centering
    
\end{figure}

We will start by soldering the two 1x20 pin headers and sockets to the Raspberry Pi Pico board. The pin strips are each two parts plugged together; keep them together, as this will keep the contacts aligned. The side with the slimmer plastic piece will be soldered to the Raspberry Pi Pico (in the picture above, the inner one).

Start by putting the pin headers into the Raspberry Pi Pico and the Buzzerino PCB. The Raspberry Pi Pico should sit flat and parallel on both pin strips.

\begin{figure}[H]
    \centering
    
\end{figure}

Now we can solder our first connections. Heat one of the corner pins with your soldering iron. Check with solder whether the joint is up to temperature by gently feeding it into the heated pin. If the solder melts, you can remove the soldering iron and let the connection cool down.

\begin{figure}[H]
    \centering
    
\end{figure}

Continue by soldering the three other corners.

\begin{figure}[H]
    \centering
    
\end{figure}

Now you can remove the Raspberry Pi Pico from the Buzzerino PCB (with the pin headers still together).

\begin{figure}[H]
    \centering
    
\end{figure}

With the Raspberry Pi Pico now free, but the pin strips still attached to it, you can fully solder both sides.

\begin{figure}[H]
    \centering
    
\end{figure}

\subsection*{Assembly of the USB-C breakout board}

\begin{figure}[H]
    \centering
    
\end{figure}

Now we will solder the 1x4 pin header to the USB-C breakout board. Because both pieces are very small, it is a good tactic to plug them together and place them on your table.

\begin{figure}[H]
    \centering
    
\end{figure}

Start by soldering only one pin, as the angle between the board and the pin header will likely be slightly crooked.

\begin{figure}[H]
    \centering
    
\end{figure}

\begin{figure}[H]
    \centering
    
\end{figure}

To correct the angle of the pin header, hold both pieces together and carefully reheat the solder joint. Now you can correct any misalignment. Once the pins are perpendicular to the board, solder all four pins.

\begin{figure}[H]
    \centering
    
\end{figure}

\subsection*{Assembly of the AHT10 digital temperature sensor}

\begin{figure}[H]
    \centering
    
\end{figure}

The assembly of the AHT10 digital temperature sensor is identical to that of the USB-C breakout board. Start by soldering only one pin and correct the alignment so it is nice and perpendicular.

\begin{figure}[H]
    \centering
    
\end{figure}

\subsection*{Assembly of the 1602A LCD display}

\begin{figure}[H]
    \centering
    
\end{figure}

The assembly of the 1602A LCD display is very similar to the previous two steps. First solder one pin, check for squareness and correct, then solder all pins.

\begin{figure}[H]
    \centering
    
\end{figure}

\begin{figure}[H]
    \centering
    
\end{figure}

\subsection*{Installation of resistors}

\subsubsection*{100 k$\Omega$ NTC temperature-dependent resistor}

The 100 k$\Omega$ NTC temperature-dependent resistor has a glass body with no markings.

\begin{figure}[H]
    \centering
    
\end{figure}

The resistors come with straight leads and need to be formed. For that purpose hold them with one hand between two fingers and pull them to a U-shape with your other hand as seen in the following pictures:

\begin{figure}[H]
    \centering
    
\end{figure}

\begin{figure}[H]
    \centering
    
\end{figure}

\begin{figure}[H]
    \centering
    
\end{figure}

\begin{figure}[H]
    \centering
    
\end{figure}

\begin{figure}[H]
    \centering
    
\end{figure}

The newly formed resistor can now be inserted into the Buzzerino PCB at the position marked \texttt{TH\_NTC}.\\
\textbf{Important:} The printed side of the Buzzerino PCB is the front of the PCB. The lower left corner should have our DIGETEC logo.

\begin{figure}[H]
    \centering
    
\end{figure}

As a tip for soldering beginners, you can slightly bend the leads outwards after fully seating the resistor. This will help keep it in place.

\begin{figure}[H]
    \centering
    
\end{figure}

Like the previous solder joints, it is good practice to start by soldering one lead first, then correct the positioning, and finally solder both.

\begin{figure}[H]
    \centering
    
\end{figure}

\begin{figure}[H]
    \centering
    
\end{figure}

After the resistor is fully seated, you can clip the leads flush with side cutters.

\subsubsection*{1 k$\Omega$ resistor}

The 1 k$\Omega$ resistor has stripes as markings (Brown | Black | Red | Gold).

\begin{figure}[H]
    \centering
    
\end{figure}

\begin{figure}[H]
    \centering
    
\end{figure}

The installation of the different resistors is essentially identical. For the 1 k$\Omega$ resistor, start by forming it roughly U-shaped.

\begin{figure}[H]
    \centering
    
\end{figure}

Then place it in its position, solder one leg, correct the placement, solder completely, and clip the leads flush.

\subsubsection*{10 k$\Omega$ resistor}

The 10 k$\Omega$ resistor has stripes as markings (Brown | Black | Orange | Gold).

\begin{figure}[H]
    \centering
    
\end{figure}

\begin{figure}[H]
    \centering
    
\end{figure}

\begin{figure}[H]
    \centering
    
\end{figure}

For the 10 k$\Omega$ resistor: form, place, solder one leg, correct, solder fully, and clip flush.

\subsubsection*{330 $\Omega$ resistors}

The 330 $\Omega$ resistors have stripes as markings (Orange | Orange | Black | Black | Brown).

\begin{figure}[H]
    \centering
    
\end{figure}

\begin{figure}[H]
    \centering
    
\end{figure}

\begin{figure}[H]
    \centering
    
\end{figure}

\begin{figure}[H]
    \centering
    
\end{figure}

For the 330 $\Omega$ resistors: form, place, solder one leg, correct, solder fully, and clip flush.

\subsubsection*{120 k$\Omega$ resistor}

The 120 k$\Omega$ resistor has stripes as markings (Brown | Red | Yellow | Gold).

\begin{figure}[H]
    \centering
    
\end{figure}

\begin{figure}[H]
    \centering
    
\end{figure}

\begin{figure}[H]
    \centering
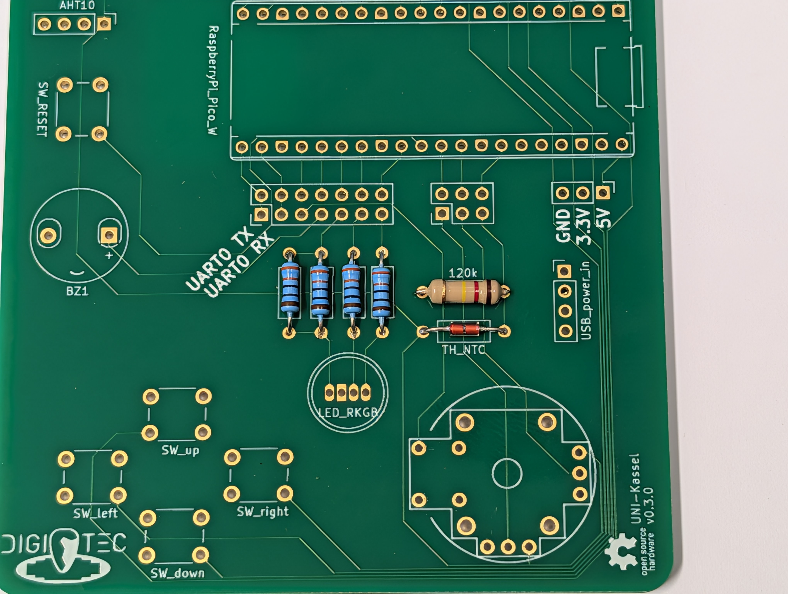
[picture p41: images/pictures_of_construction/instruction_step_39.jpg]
    
\end{figure}

For the 120 k$\Omega$ resistor: form, place, solder one leg, correct, solder fully, and clip flush.

\subsection*{Installation of the buttons}

\begin{figure}[H]
    \centering
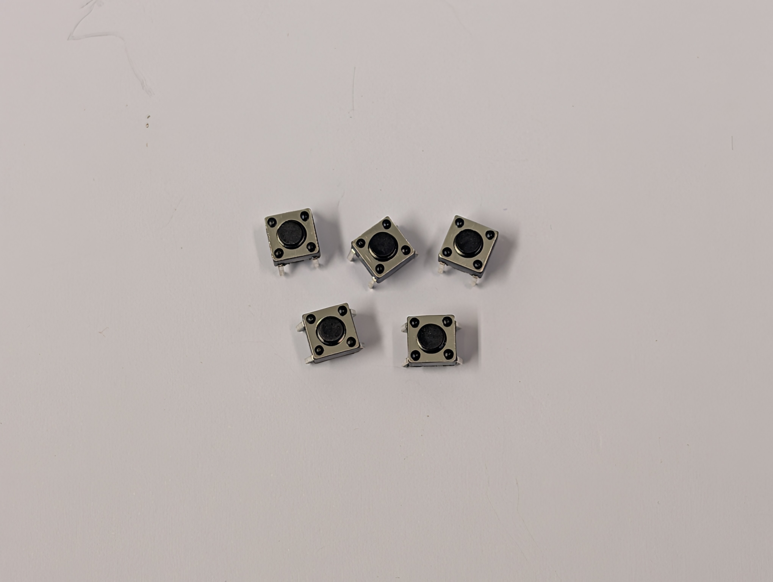
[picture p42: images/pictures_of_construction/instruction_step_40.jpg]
    
\end{figure}

For the assembly of the Buzzerino PCB, we will go from the shortest to the highest component. This helps you successfully solder your board.

\begin{figure}[H]
    \centering
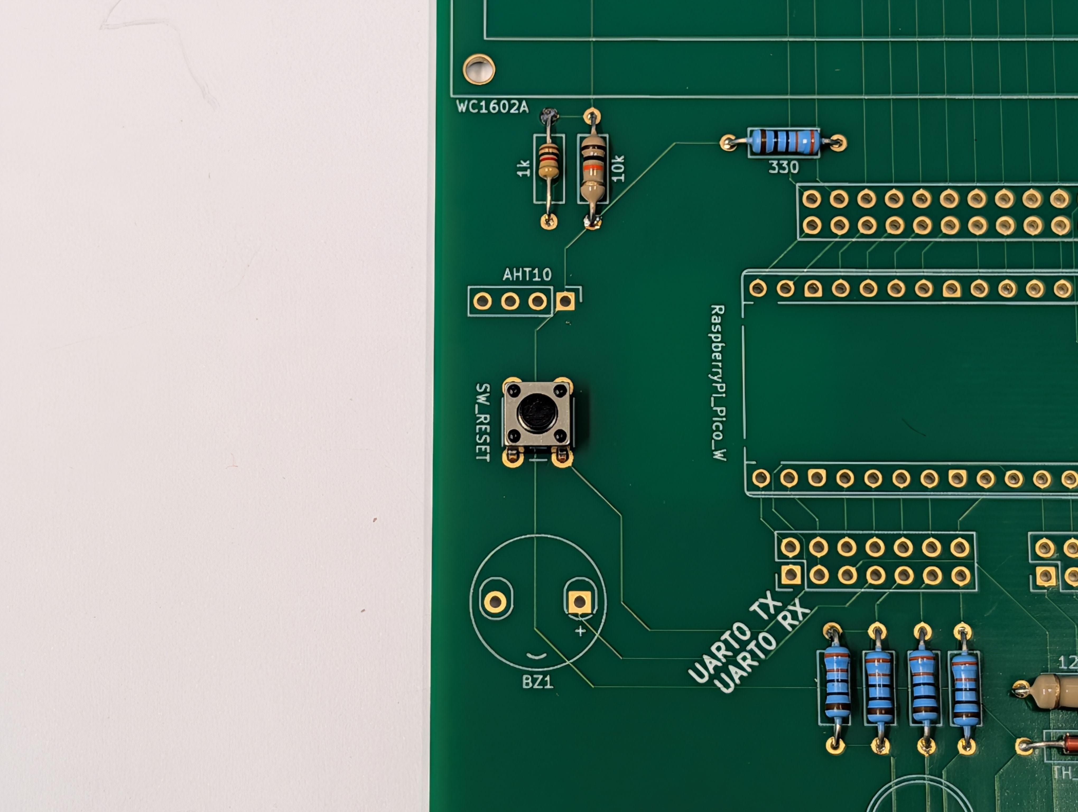
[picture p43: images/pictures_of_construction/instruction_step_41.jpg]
    
\end{figure}

\begin{figure}[H]
    \centering
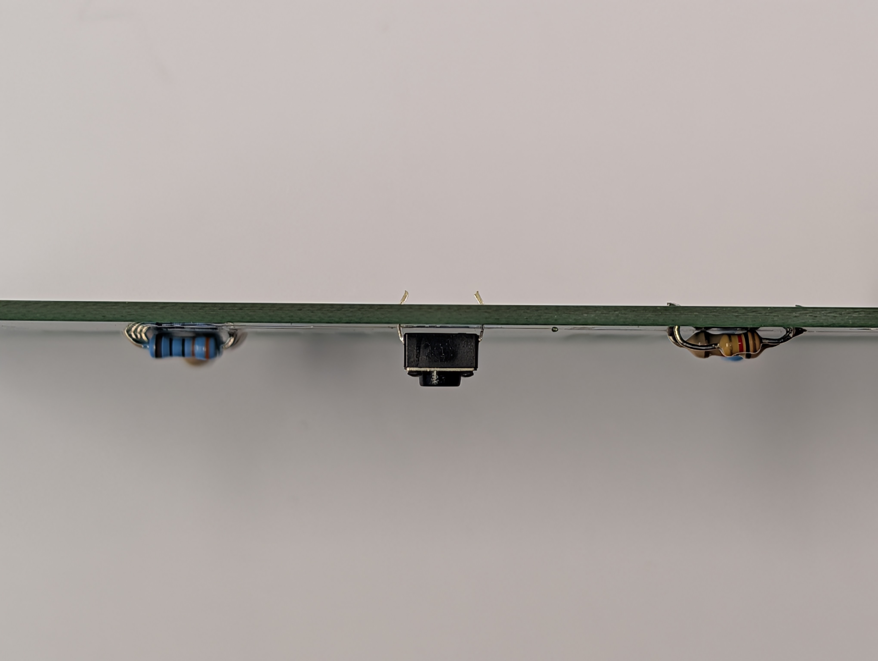
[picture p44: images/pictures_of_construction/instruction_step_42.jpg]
    
\end{figure}

The shape of the button legs is designed to snap into the Buzzerino PCB. After placing the buttons, check if they sit flush to the Buzzerino PCB. Then solder and clip the leads.

\begin{figure}[H]
    \centering
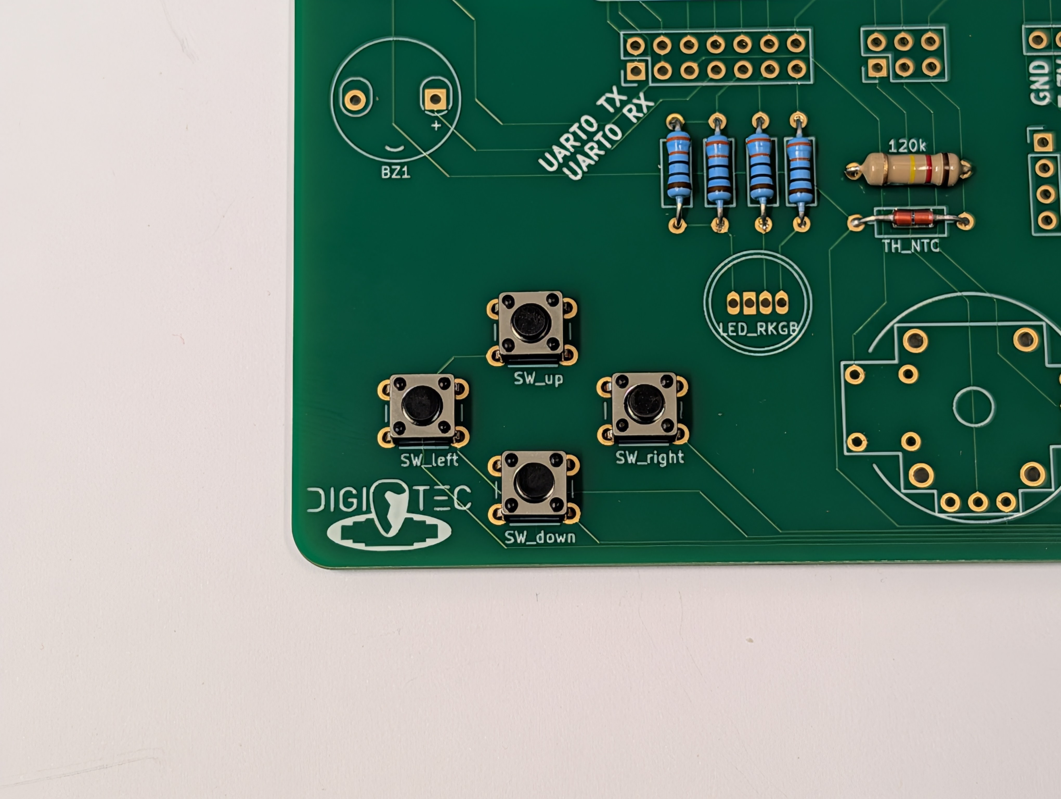
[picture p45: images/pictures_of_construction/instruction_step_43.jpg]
    
\end{figure}

With the D-pad buttons it is the same procedure as with the reset button.

\subsection*{Soldering the pin header}

\textbf{Repeated Error: The short side shall go through the board!}

\begin{figure}[H]
    \centering
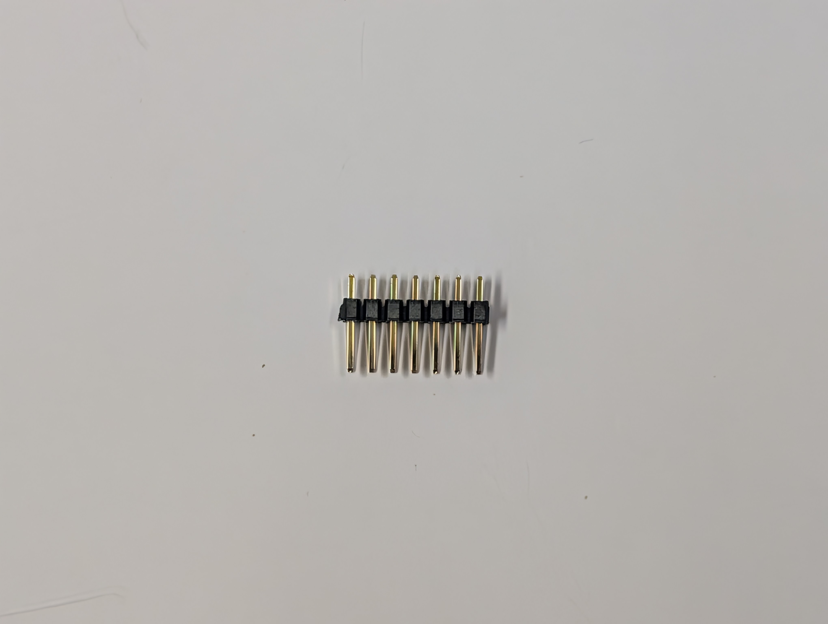
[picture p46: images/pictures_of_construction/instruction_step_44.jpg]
    
\end{figure}

\begin{figure}[H]
    \centering
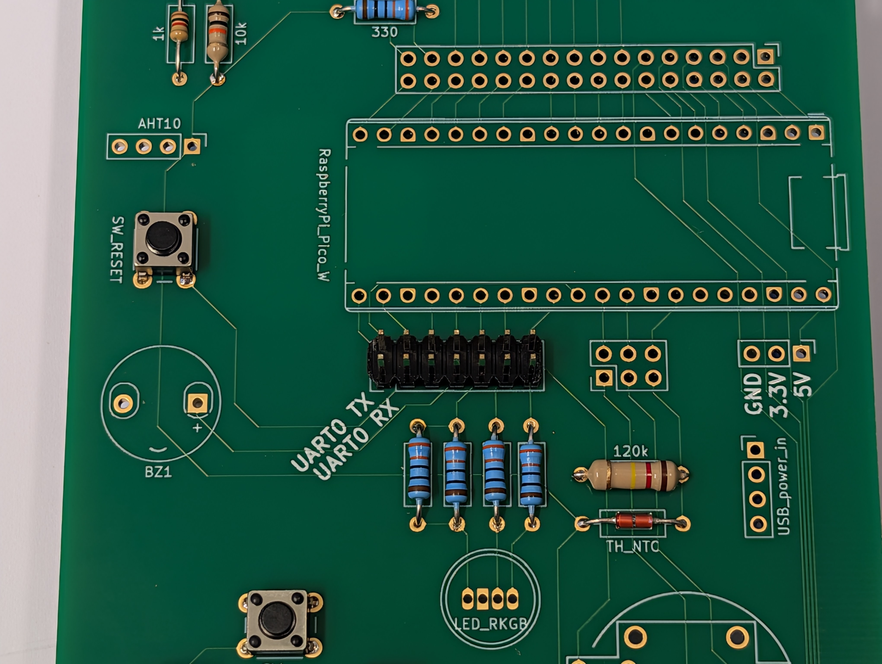
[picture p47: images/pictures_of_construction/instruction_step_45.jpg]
    
\end{figure}

We start by soldering the 2x7 pin header to the Buzzerino PCB. \textbf{The short side shall go through the board.}

\begin{figure}[H]
    \centering
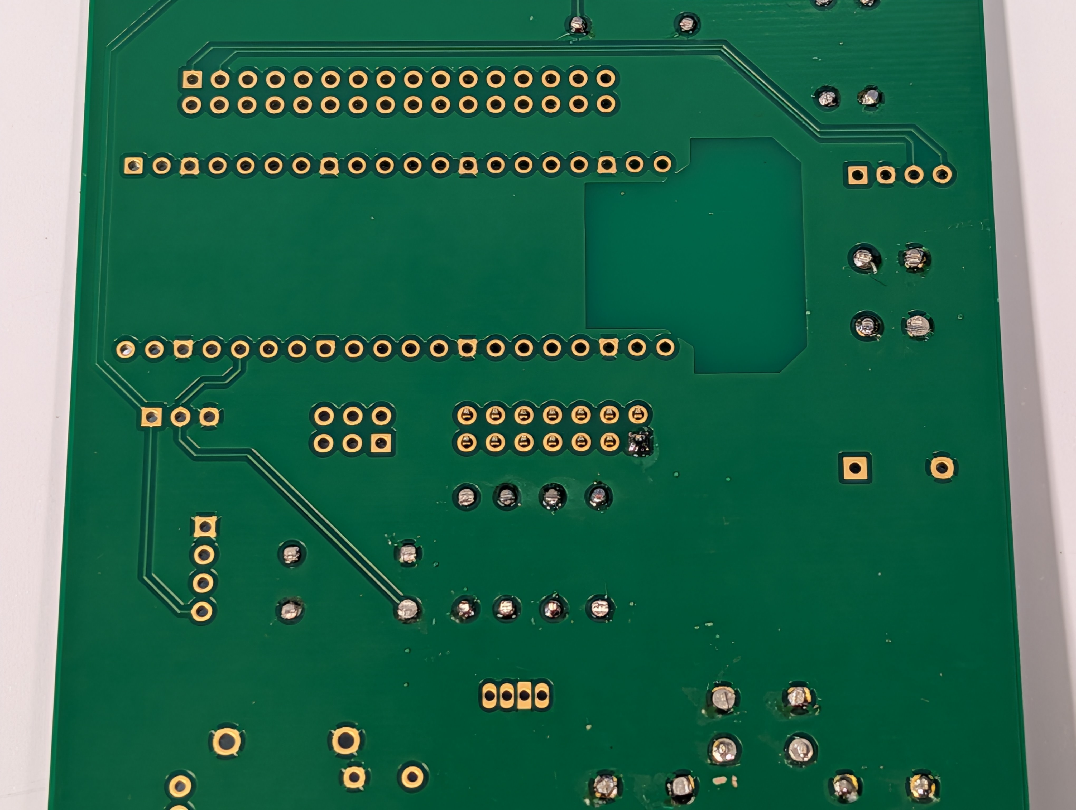
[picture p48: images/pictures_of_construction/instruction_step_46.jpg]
    
\end{figure}

As with all the previous solder joints, it is best practice to first solder one pin and then check for alignment. The wider pin header will often move a bit out of the Buzzerino PCB and may need to be reseated. Only after the pin headers are placed completely in position should you solder the remaining pins.

\begin{figure}[H]
    \centering
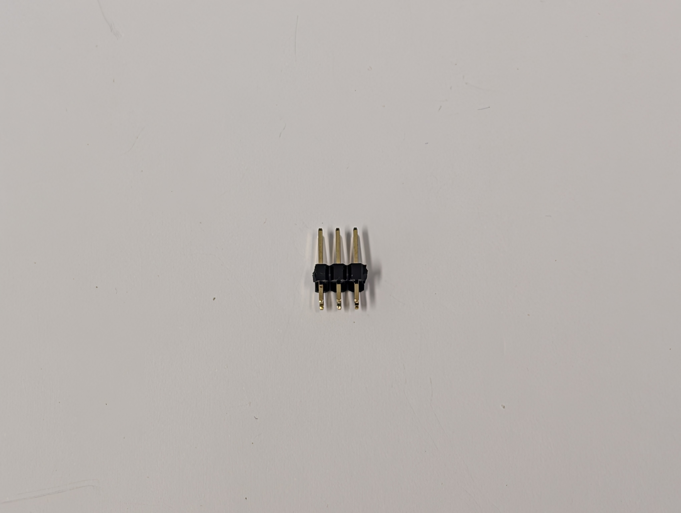
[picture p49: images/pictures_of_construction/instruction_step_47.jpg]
    
\end{figure}

\begin{figure}[H]
    \centering
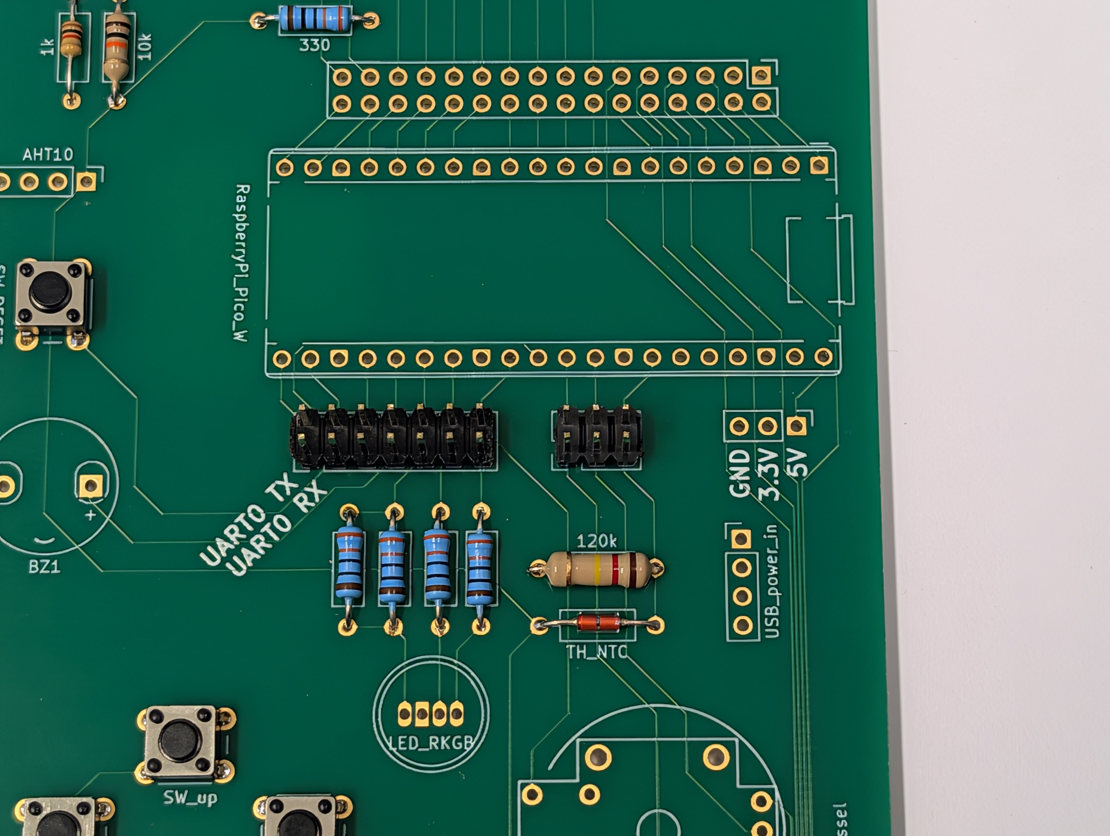
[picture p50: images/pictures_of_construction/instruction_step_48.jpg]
    
\end{figure}

\begin{figure}[H]
    \centering
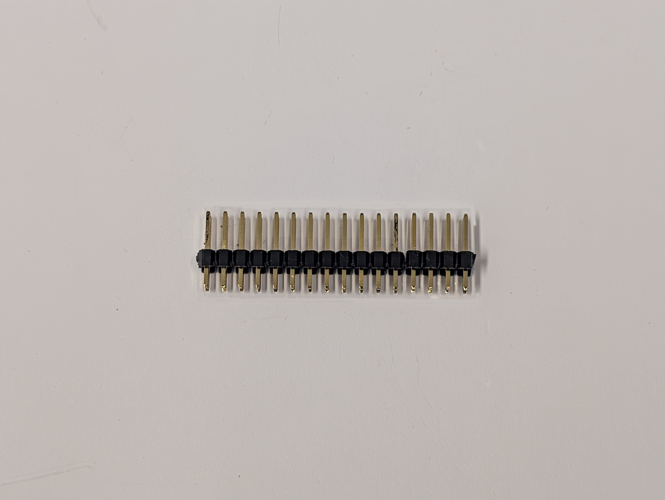
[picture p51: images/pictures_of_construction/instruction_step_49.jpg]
    
\end{figure}

\begin{figure}[H]
    \centering
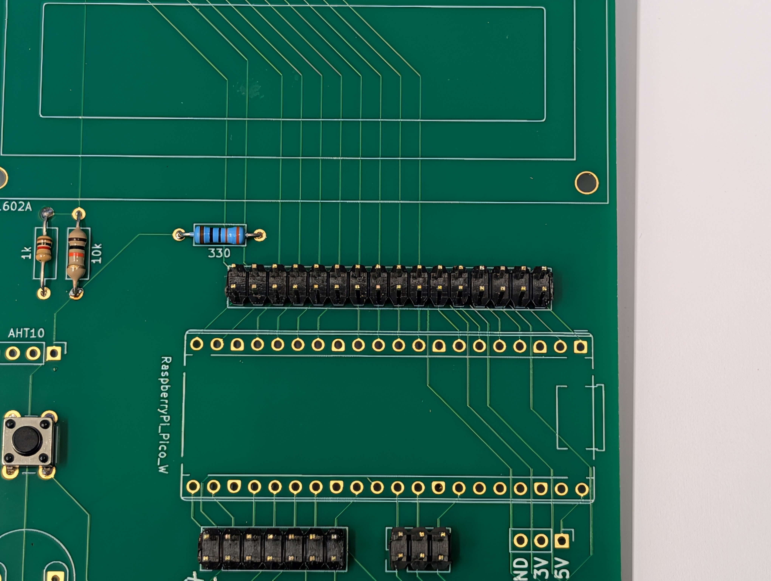
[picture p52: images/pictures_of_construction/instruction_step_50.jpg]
    
\end{figure}

Repeat the previous step for the 2x3 and 2x16 pin headers. Start by soldering one pin, then check and correct the seating, and then solder completely.

\begin{figure}[H]
    \centering
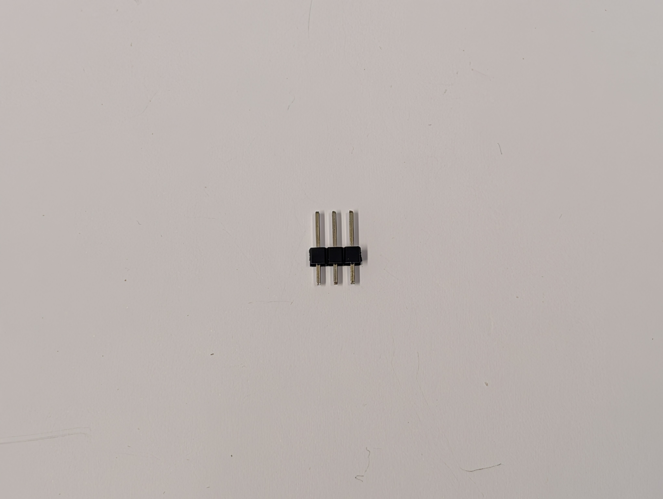
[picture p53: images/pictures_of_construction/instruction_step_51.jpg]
    
\end{figure}

\begin{figure}[H]
    \centering
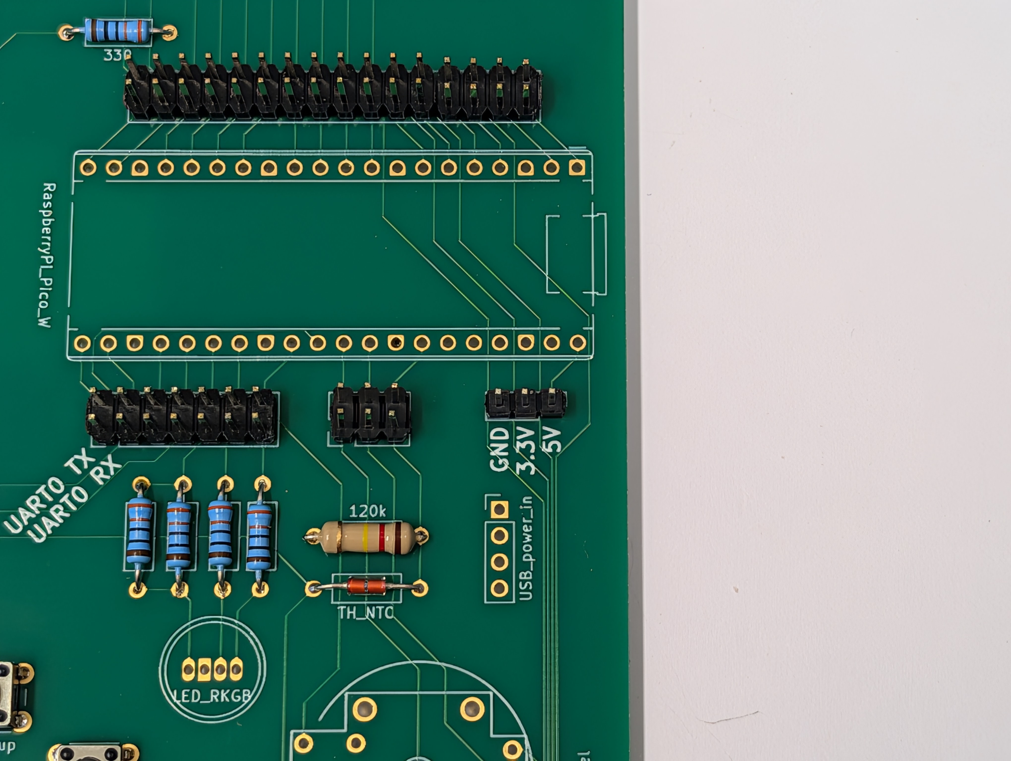
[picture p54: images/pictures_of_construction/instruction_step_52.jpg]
    
\end{figure}

The 1x3 pin header is one of the fiddliest to install. With all the previous practice, you will be able to solder it flush and perpendicular.

\subsection*{Installation of the USB-C breakout board}

\begin{figure}[H]
    \centering
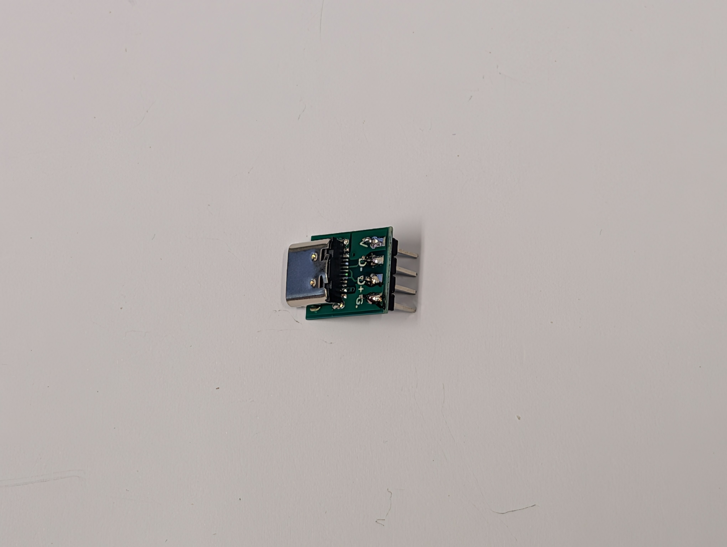
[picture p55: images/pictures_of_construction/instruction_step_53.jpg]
    
\end{figure}

\begin{figure}[H]
    \centering
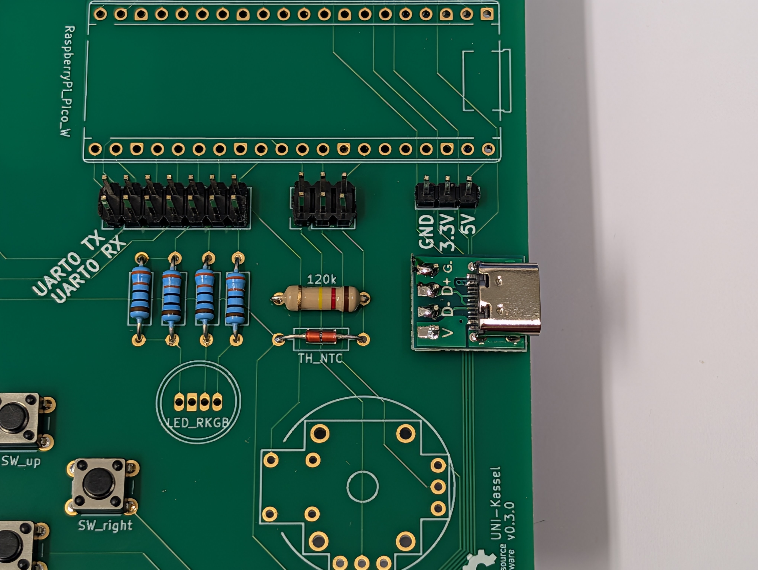
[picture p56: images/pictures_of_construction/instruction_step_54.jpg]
    
\end{figure}

\begin{figure}[H]
    \centering
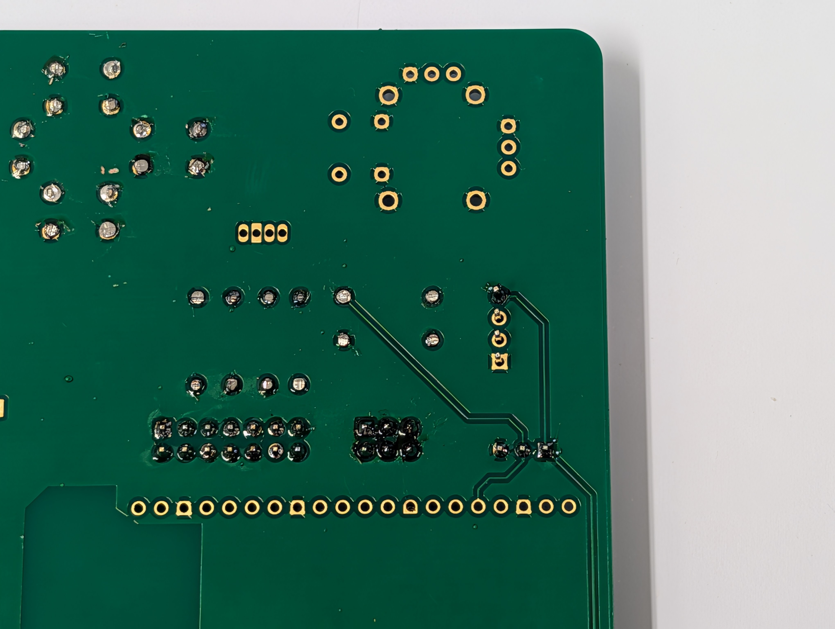
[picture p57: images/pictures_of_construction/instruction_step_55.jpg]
    
\end{figure}

\begin{figure}[H]
    \centering
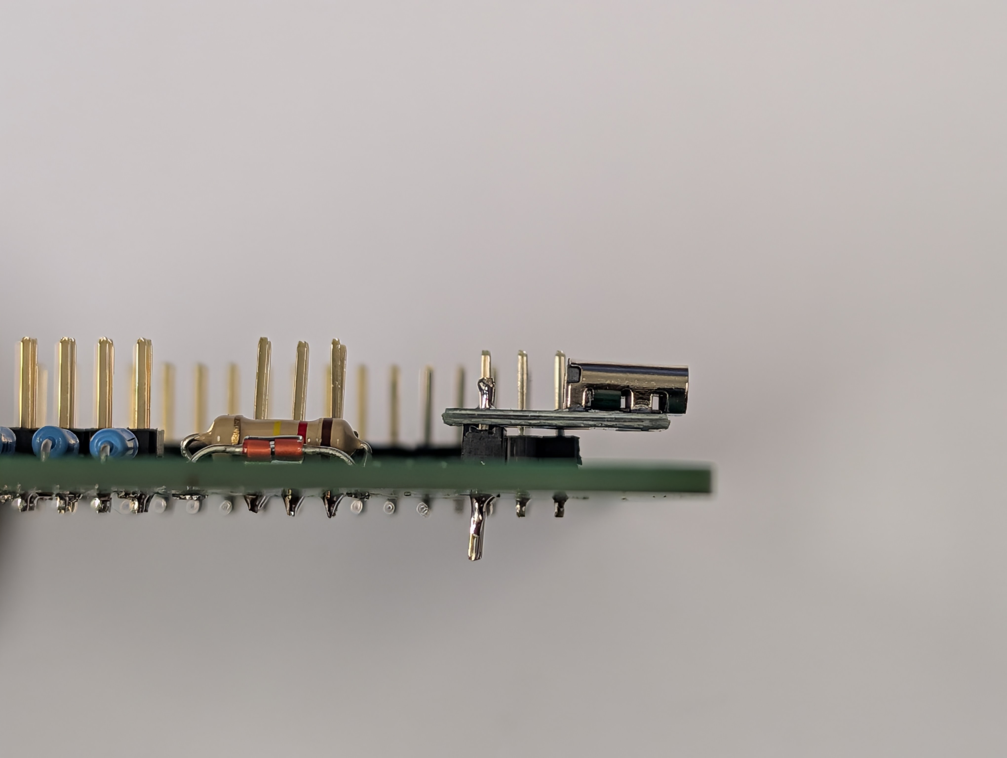
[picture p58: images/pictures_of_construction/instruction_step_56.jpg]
    
\end{figure}

Now we can solder the USB-C breakout board. After placing it into position (right side of the Buzzerino PCB, facing outwards, the USB port should be fully visible), solder one pin. Then check for alignment; it should be parallel to the Buzzerino PCB. Then solder it completely.

\textbf{WARNING:} The pins of the USB-C breakout board, the AHT10 temperature sensor, and the 1602A LCD display are too hard for electronics side cutters. Use larger wire cutters as provided.

\subsection*{Installation of the AHT10 digital temperature sensor}

\begin{figure}[H]
    \centering
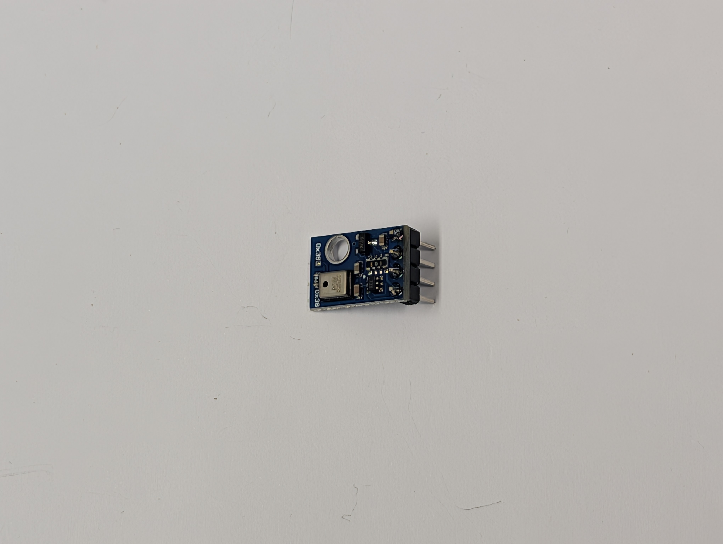
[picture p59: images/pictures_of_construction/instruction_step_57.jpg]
    
\end{figure}

\begin{figure}[H]
    \centering
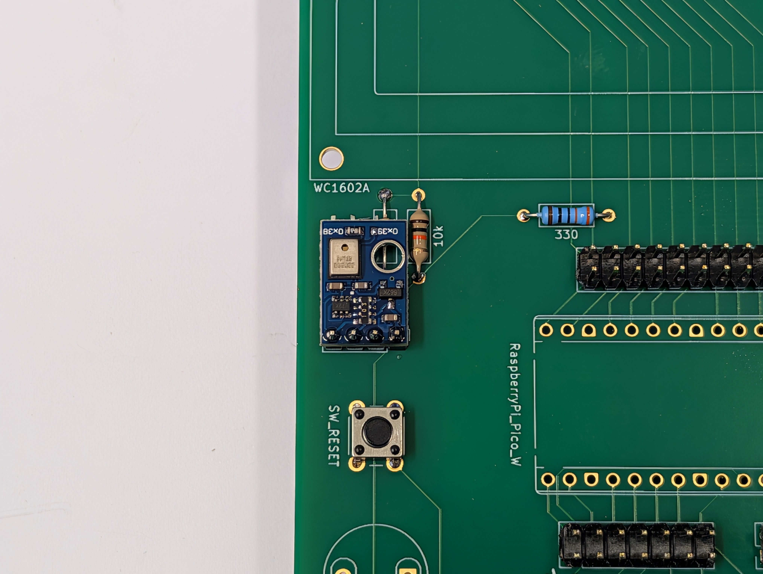
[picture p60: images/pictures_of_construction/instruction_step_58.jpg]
    
\end{figure}

The installation of the AHT10 digital temperature sensor is analogous to the USB-C breakout board (position left side of the Buzzerino PCB, facing upwards, the components of the sub-PCB should be visible). But remember: use the larger wire cutters for cutting the pins to length.

\subsection*{Installation of the Buzzer}

\begin{figure}[H]
    \centering
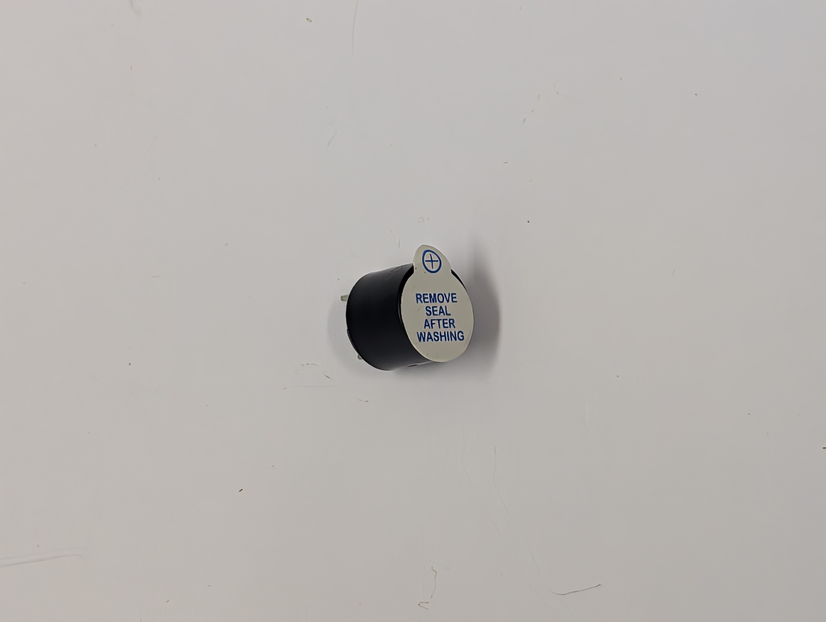
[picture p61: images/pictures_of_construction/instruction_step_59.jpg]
    
\end{figure}

\begin{figure}[H]
    \centering
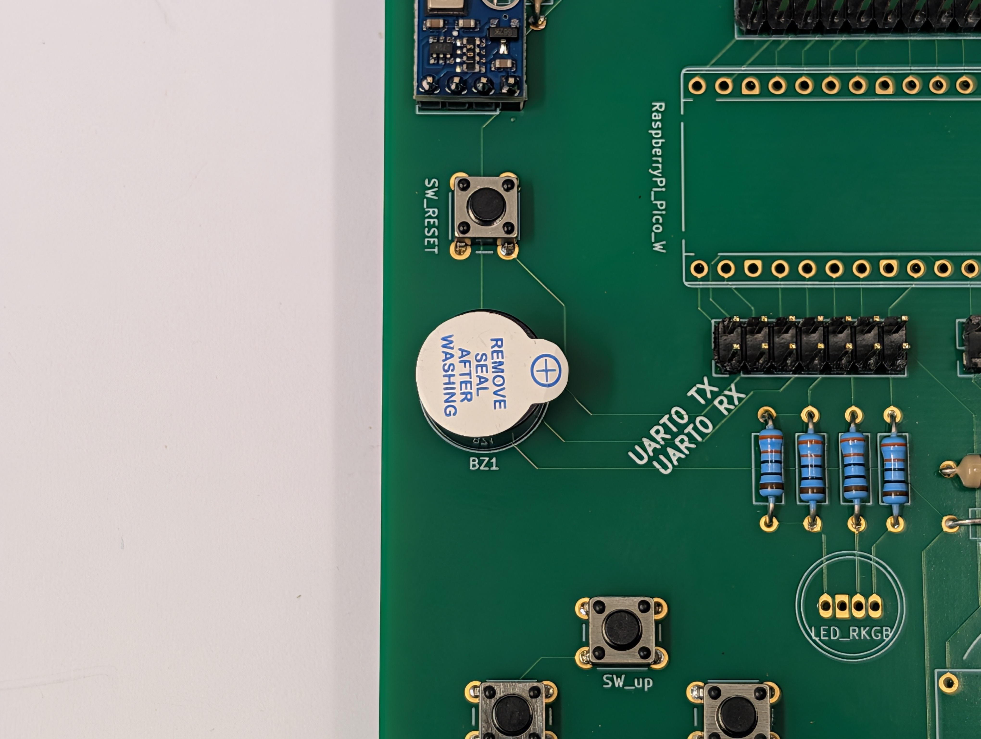
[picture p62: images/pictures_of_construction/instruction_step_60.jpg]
    
\end{figure}

Finally, we can install the namesake of the board. This is our first polarized component. The footprint on the Buzzerino PCB shows a small \texttt{+}. Furthermore, the sticker on the buzzer has a plus on its top. These should be aligned. (If you look from the front of the Buzzerino PCB, the plus will be facing inwards.) Moreover, if you are unsure, you can check the buzzer's leads: one of them is longer than the other. This is the positive lead and shall align with the plus symbol on the Buzzerino PCB.

\subsection*{Installation of the 1602A LCD display}

\begin{figure}[H]
    \centering
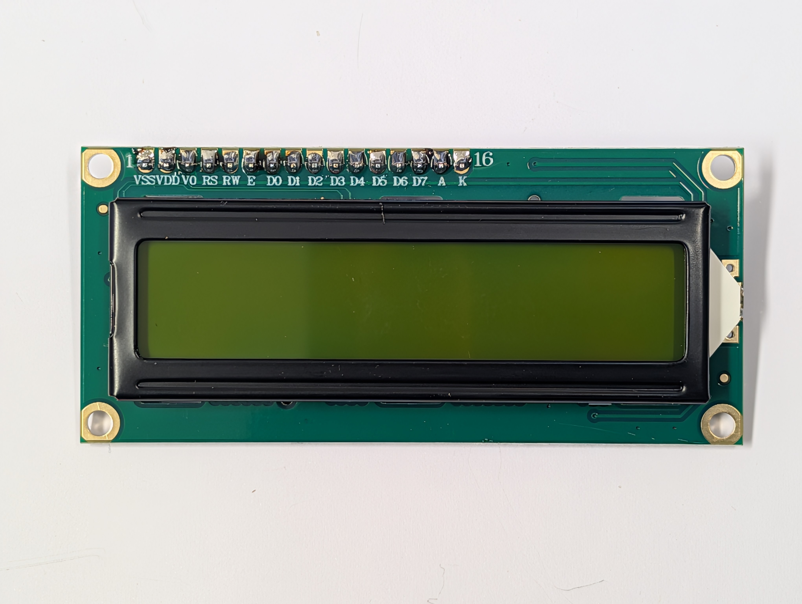
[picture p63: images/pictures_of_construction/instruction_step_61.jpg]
    
\end{figure}

\begin{figure}[H]
    \centering
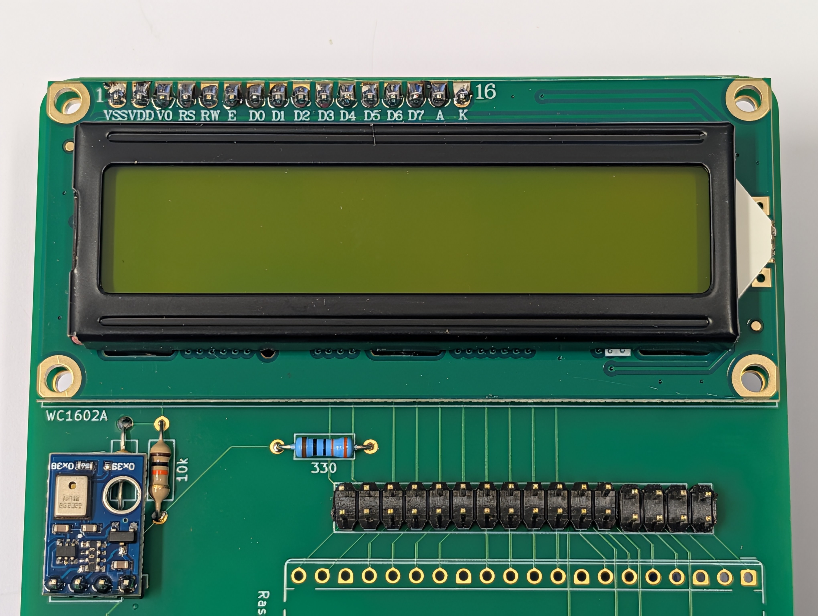
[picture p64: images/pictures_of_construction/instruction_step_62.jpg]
    
\end{figure}

\begin{figure}[H]
    \centering
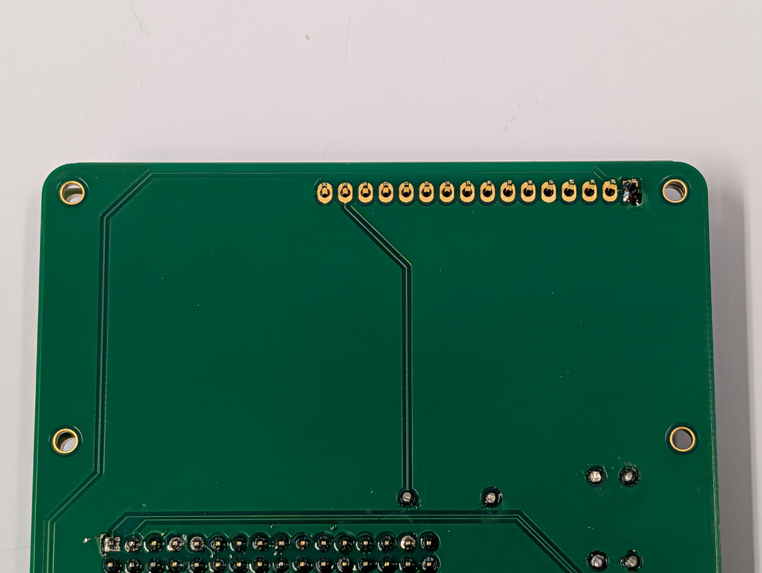
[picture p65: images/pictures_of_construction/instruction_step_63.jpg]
    
\end{figure}

\begin{figure}[H]
    \centering
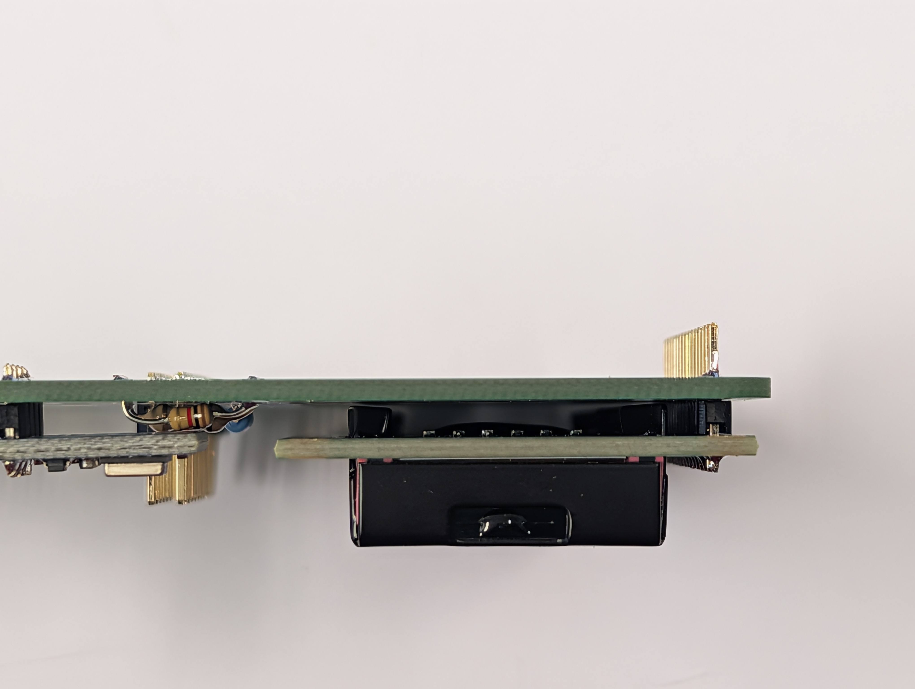
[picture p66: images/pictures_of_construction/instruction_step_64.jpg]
    
\end{figure}

The installation of the 1602A LCD display is analogous to the USB-C breakout board. First place, then solder one pin, then check for alignment and then solder fully. But remember: use the larger wire cutters for cutting the pins to length.

\subsection*{Installation of the RGB LED}

\begin{figure}[H]
    \centering
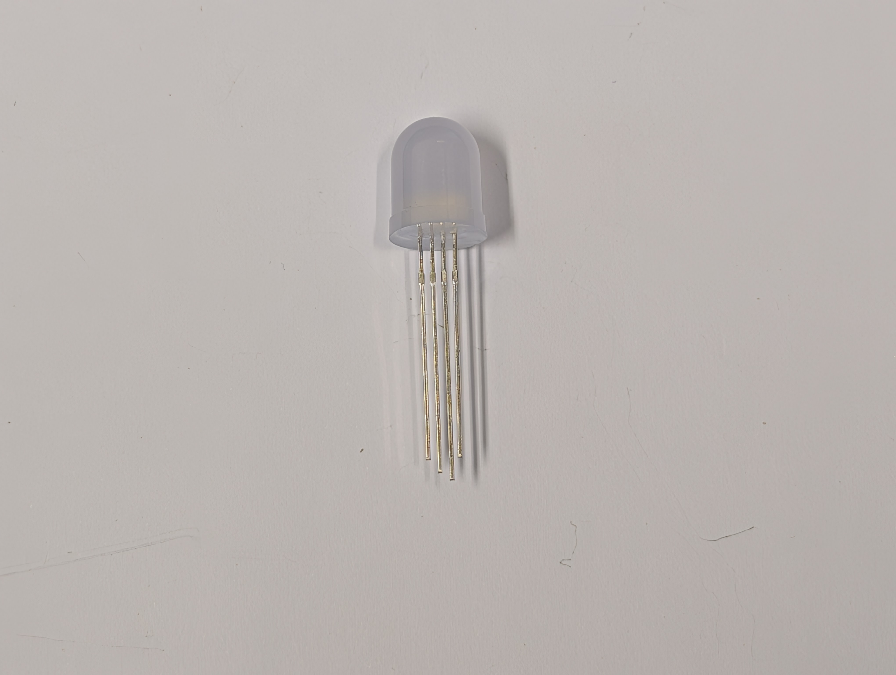
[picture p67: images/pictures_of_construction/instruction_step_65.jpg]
    
\end{figure}

Now we can install the RGB LED.

\begin{figure}[H]
    \centering
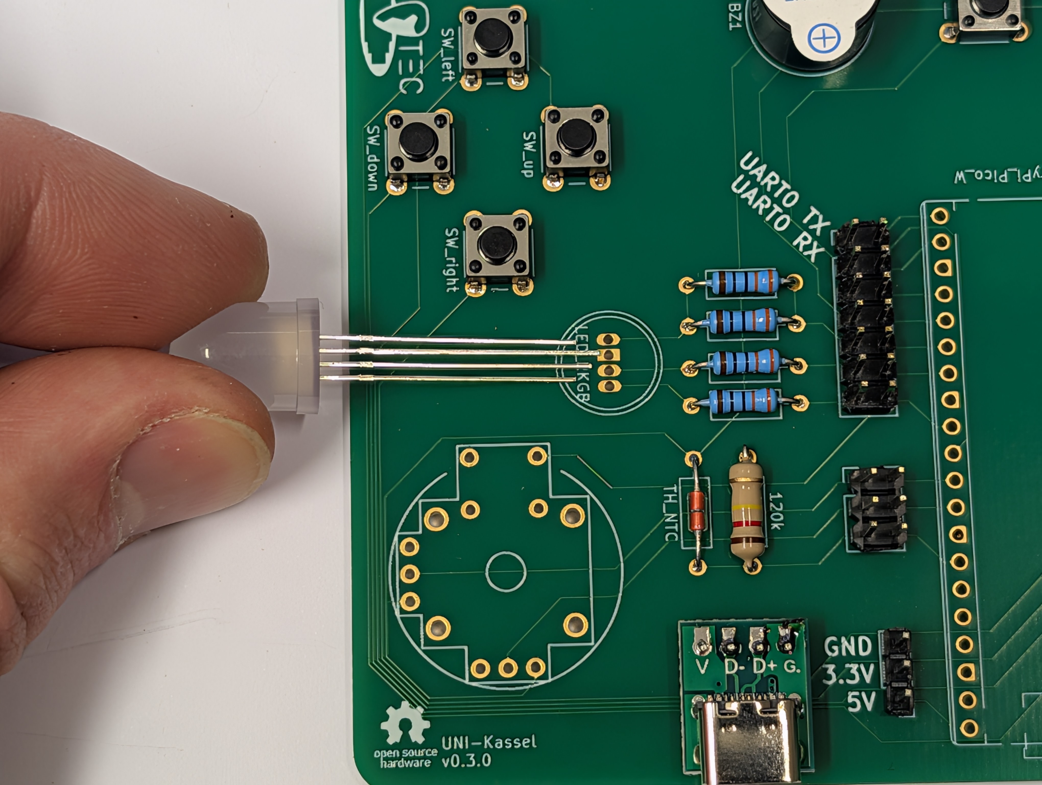
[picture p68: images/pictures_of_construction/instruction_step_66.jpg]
    
\end{figure}

\begin{figure}[H]
    \centering
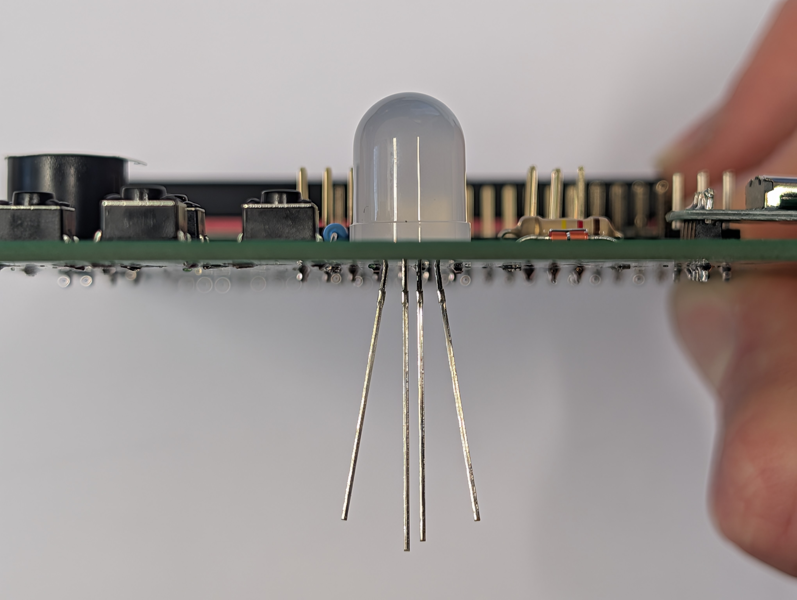
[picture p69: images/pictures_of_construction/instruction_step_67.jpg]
    
\end{figure}

The LED is, like the buzzer, polarized. But here the longest leg is the negative connection. The footprint on the Buzzerino PCB indicates the negative connection with a square pad. Place the LED into its position. The spacing of the pads is a bit wider than the lead spacing, so the leads will spread out automatically.

\begin{figure}[H]
    \centering
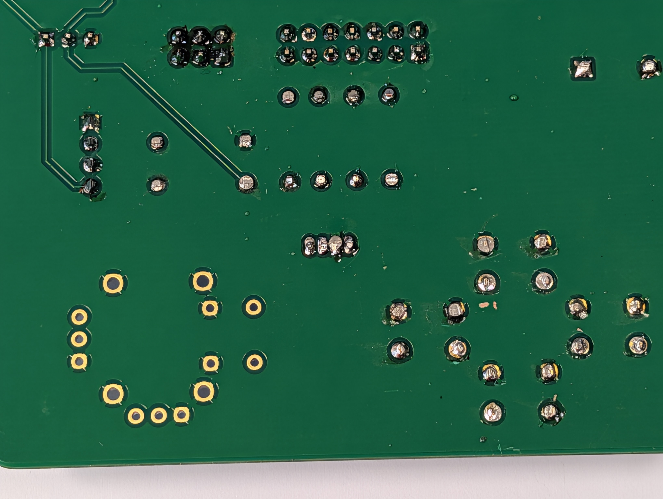
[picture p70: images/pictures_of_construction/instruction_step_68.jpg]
    
\end{figure}

\begin{figure}[H]
    \centering
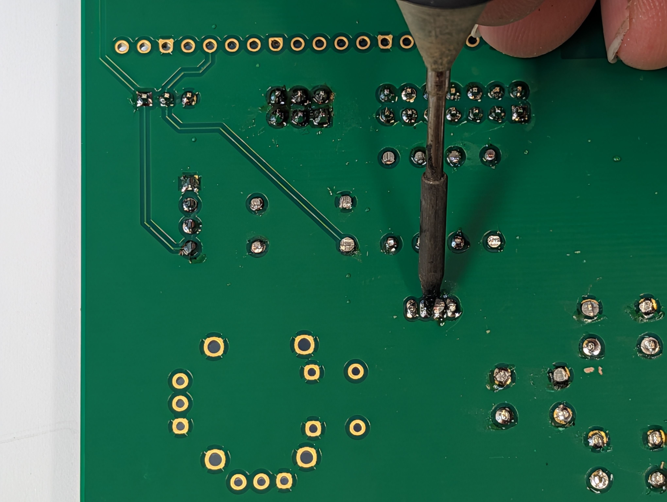
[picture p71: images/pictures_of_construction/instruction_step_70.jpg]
    
\end{figure}

\begin{figure}[H]
    \centering
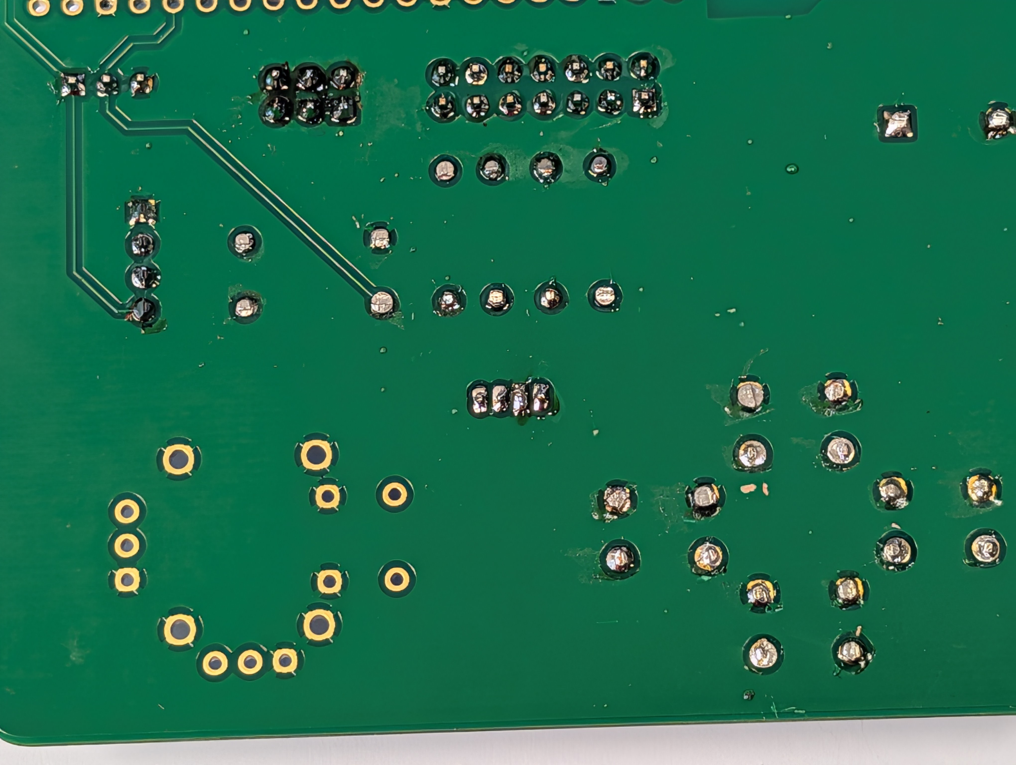
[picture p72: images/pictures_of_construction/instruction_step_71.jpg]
    
\end{figure}

After soldering and cutting the RGB LED's leads flush, you will probably have a very ugly joint. Luckily, you can easily correct this by slowly running your soldering iron between two pins and letting them reflow. The surface tension of the solder should pull the joint nicely together, resulting in a clean joint. But check for any bridges after that. If there are any, clean your soldering tip and repeat the reflow.

\subsection*{Installation of the Raspberry Pi Pico}

\begin{figure}[H]
    \centering
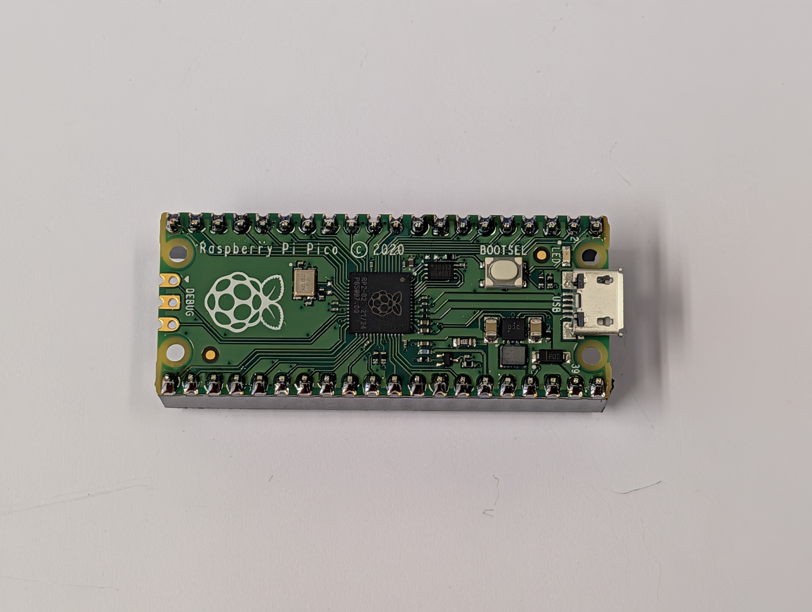
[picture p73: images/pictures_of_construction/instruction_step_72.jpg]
    
\end{figure}

\begin{figure}[H]
    \centering
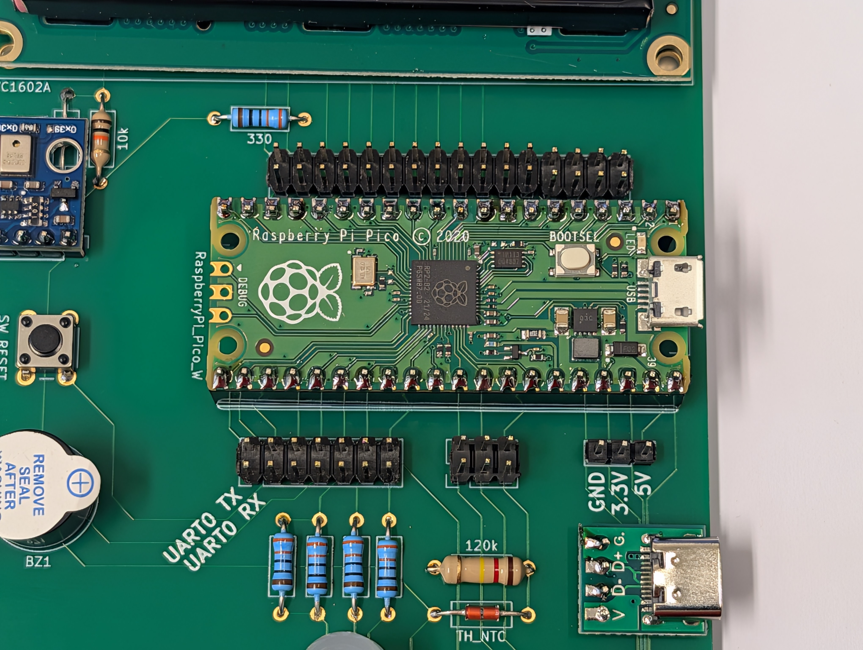
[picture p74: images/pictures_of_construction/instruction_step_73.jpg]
    
\end{figure}

\begin{figure}[H]
    \centering
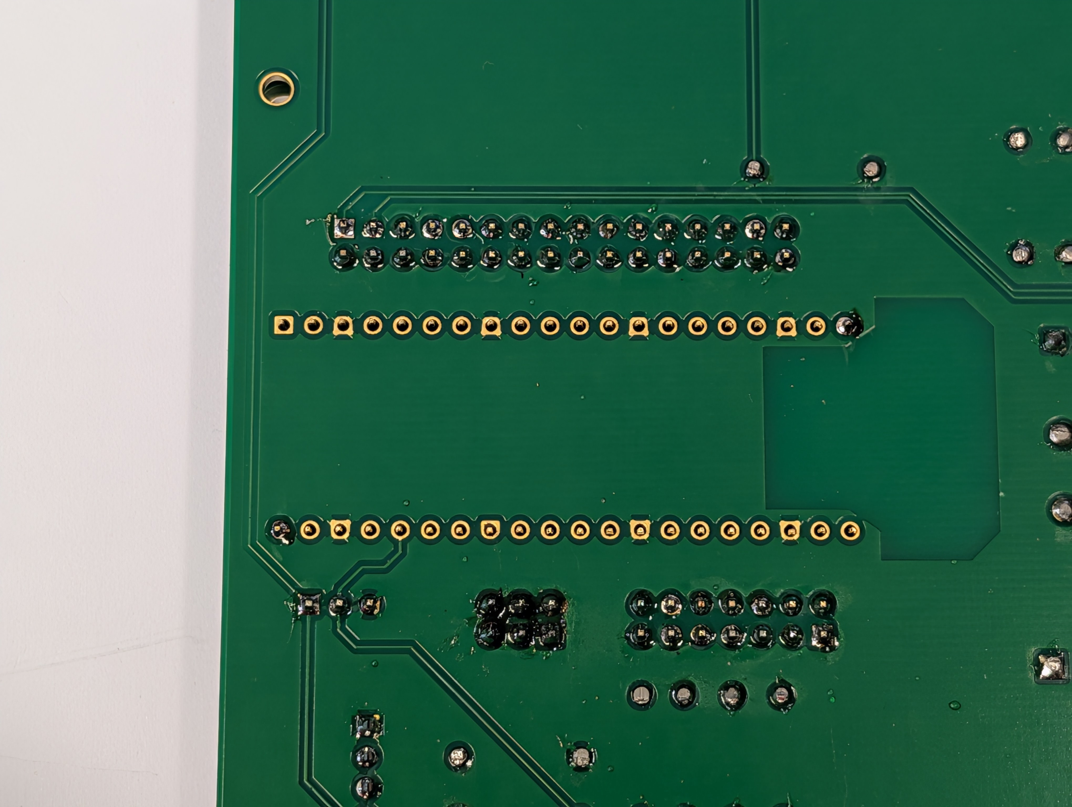
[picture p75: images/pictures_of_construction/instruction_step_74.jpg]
    
\end{figure}

Now we can install the Raspberry Pi Pico. As with all previous complex connections, start by soldering only two opposite pins. Then check for alignment; after that, solder completely.

\subsection*{Installation of the analogue joystick}

\begin{figure}[H]
    \centering
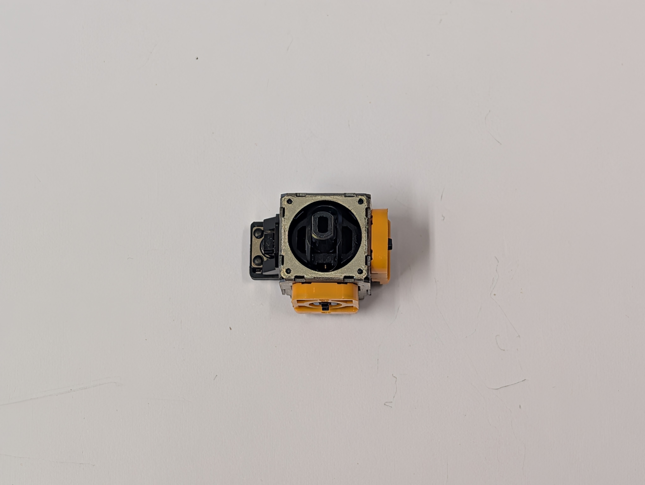
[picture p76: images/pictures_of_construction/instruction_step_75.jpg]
    
\end{figure}

\begin{figure}[H]
    \centering
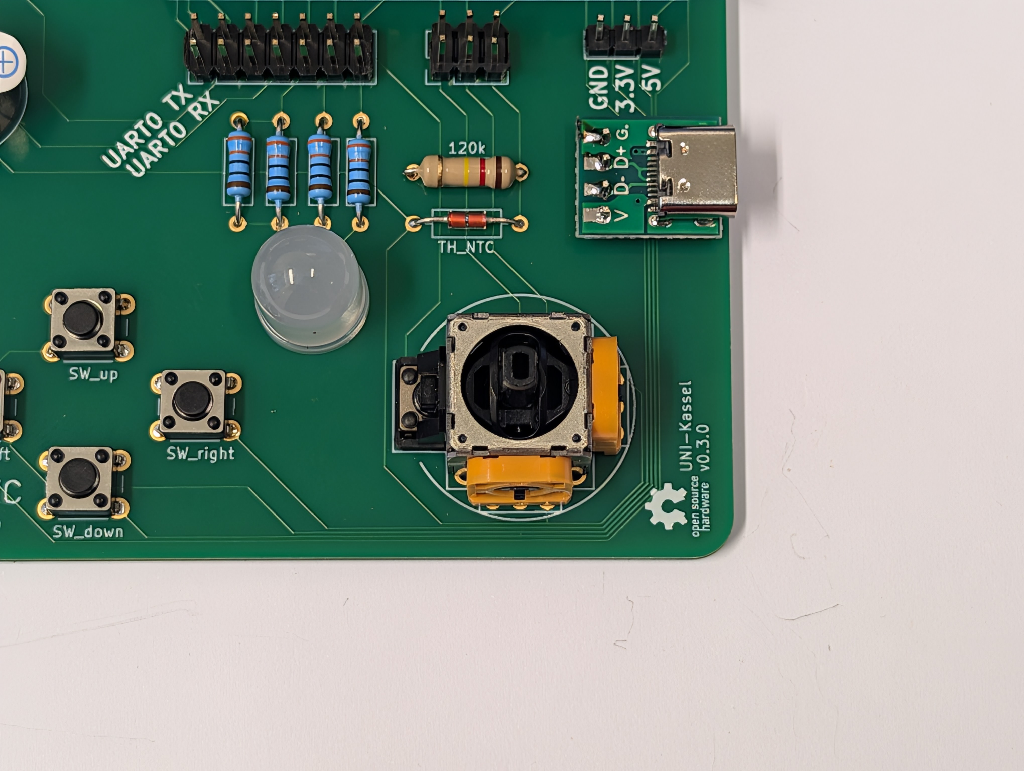
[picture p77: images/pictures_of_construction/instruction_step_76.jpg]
    
\end{figure}

As the last component, we will install the analogue joystick.

\begin{figure}[H]
    \centering
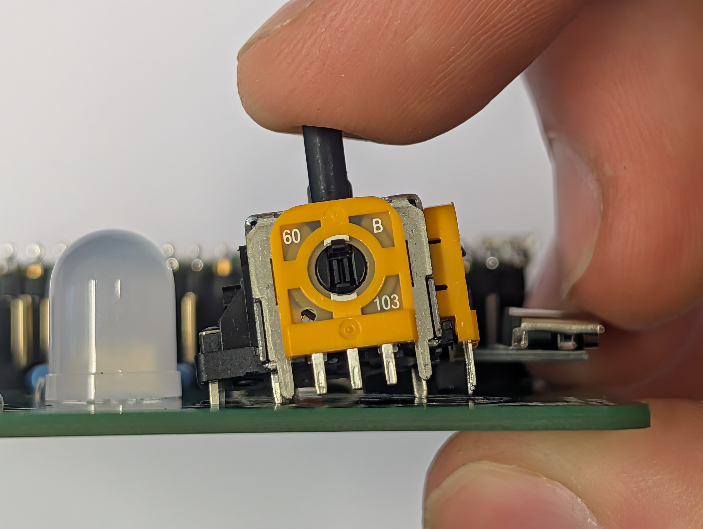
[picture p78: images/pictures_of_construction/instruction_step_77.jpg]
    
\end{figure}

\begin{figure}[H]
    \centering
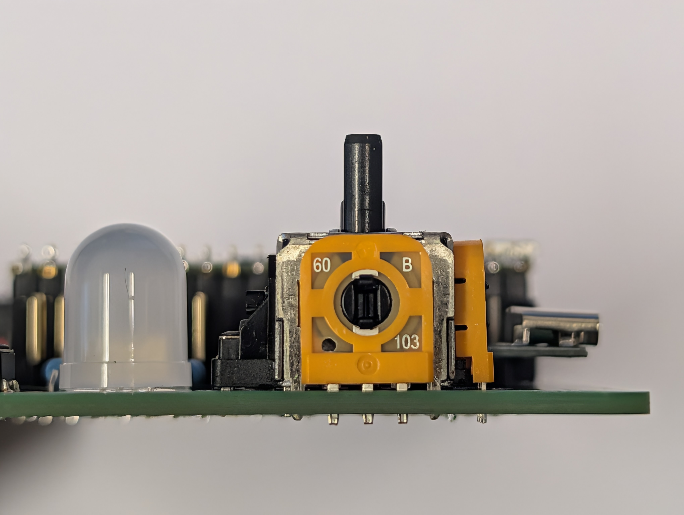
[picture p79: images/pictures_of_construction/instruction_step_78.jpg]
    
\end{figure}

The installation of the joystick can be harder than necessary because of the many different pins. Start by putting the push-button pins into the Buzzerino PCB and then wiggle each pin from left to right slowly into position. After the joystick is fully seated, you can solder it in place.

\begin{figure}[H]
    \centering
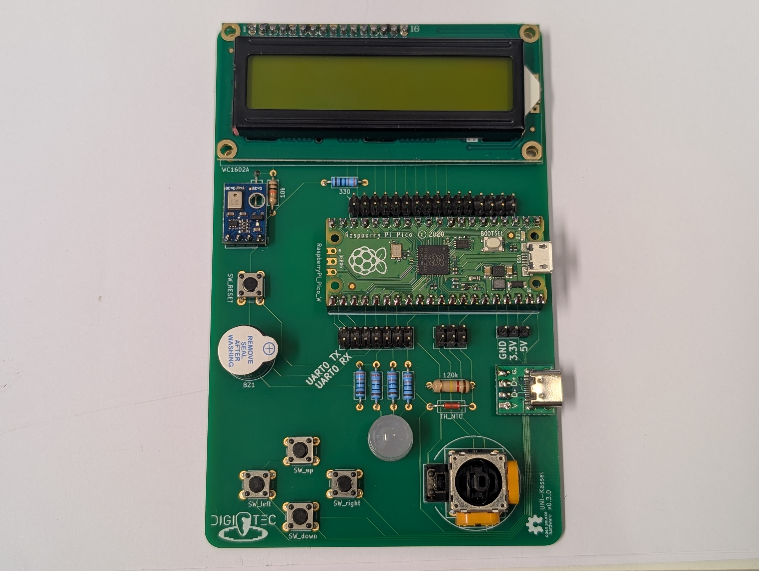
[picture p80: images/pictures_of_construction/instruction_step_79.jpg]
    
\end{figure}

\subsection*{Installation of the jumpers}

\begin{figure}[H]
    \centering
    
\end{figure}

Before testing the board, we need to install all 26 jumpers as seen in the picture above.

\textbf{Congratulations, you have finished your soldering project.}

If you already flashed your Raspberry Pi Pico, it is time to power it up; if not, flash the \texttt{self\_test.uf2} onto the board.

\section*{Flashing}

If the board is not connected to a power source: press and hold the \textbf{BOOTSEL} button on the Raspberry Pi Pico and connect it via micro-USB to a PC. The Pico should mount as a mass-storage device called \textbf{RPI-RP2}. Now you can drag and drop a previously compiled or downloaded \texttt{.uf2} file onto it. It will automatically unmount and reboot. Ignore the message from your PC that the device was disconnected without ejecting.

You do not need to unplug and replug the Raspberry Pi Pico every time you want to flash it. You can also, with an established connection to your PC, press and hold the \textbf{BOOTSEL} button on the Raspberry Pi Pico and then briefly press (while still holding the \textbf{BOOTSEL} button) the \textbf{SW\_RESET} button on the Buzzerino PCB.

\section*{Example Programs}

The code of the example programs and their \texttt{.uf2} files are available in the folder \texttt{example\_programs}. Unless otherwise noted, all programs are designed and compiled for the Raspberry Pi Pico (neither the W version nor version 2) but can be recompiled for these targets. The preferred way to compile is VS Code with the Raspberry Pi Pico extension.

\end{document}

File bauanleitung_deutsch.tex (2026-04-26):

\documentclass[a4paper,11pt]{article}

\usepackage[utf8]{inputenc}
\usepackage[T1]{fontenc}
\usepackage[ngerman]{babel}
\usepackage[a4paper,margin=2.5cm]{geometry}
\usepackage{graphicx}
\usepackage{float}
\usepackage{hyperref}
\usepackage{enumitem}
\usepackage{parskip}
\usepackage{xcolor}

\hypersetup{
    colorlinks=true,
    linkcolor=blue,
    urlcolor=blue
}

\title{Buzzerino -- Aufbauanleitung}
\author{}
\date{}

\begin{document}

\maketitle

Diese Anleitung beschreibt den Aufbau des \textbf{Buzzerino}-Bausatzes Schritt für Schritt. Sie richtet sich an Studierende ohne oder mit nur wenig Löterfahrung. Ziel ist ein sauber aufgebautes und funktionsfähiges System.

\section*{Vorbereitung}

Bevor du beginnst, solltest du deinen Arbeitsplatz sinnvoll vorbereiten. Lege alle Bauteile übersichtlich bereit und prüfe, ob das notwendige Werkzeug vorhanden ist.

Benötigt werden:
\begin{itemize}
    \item Lötkolben
    \item Lötzinn
    \item Seitenschneider
    \item ggf. kleine Flachzange
    \item alle Bauteile des Bausatzes
\end{itemize}

\textbf{Hinweise zum Arbeiten:}
\begin{itemize}
    \item Arbeite konzentriert und ohne Zeitdruck.
    \item Der Lötkolben wird sehr heiß. Vermeide jeden Kontakt mit Spitze und frisch gelöteten Stellen.
    \item Löte möglichst sauber und mit wenig, aber ausreichend Lötzinn.
    \item Bei Bauteilen mit vielen Pins empfiehlt es sich fast immer, zunächst nur einen oder zwei Pins zu löten, die Ausrichtung zu prüfen und erst danach vollständig zu verlöten.
\end{itemize}

\section*{Stückliste}

\begin{figure}[H]
    \centering
    
\end{figure}

Vor dem Aufbau sollte kontrolliert werden, ob alle Komponenten vorhanden sind:

\begin{itemize}
    \item 1x Buzzerino-Platine
    \item 1x Raspberry Pi Pico
    \item 1x 1602A-LCD-Display
    \item 1x AHT10 Temperatur- und Luftfeuchtigkeitssensor
    \item 1x USB-C-Breakout-Board
    \item 1x 10\,mm RGB-LED
    \item 1x Buzzer
    \item 1x analoger Joystick
    \item 5x Taster
    \item 1x 100-k$\Omega$-NTC
    \item 5x 330-$\Omega$-Widerstände
    \item 1x 1-k$\Omega$-Widerstand
    \item 1x 10-k$\Omega$-Widerstand
    \item 1x 120-k$\Omega$-Widerstand
    \item 2x 1x20 Stift-/Buchsenleisten
    \item 1x 1x16 Stiftleiste
    \item 2x 1x4 Stiftleisten
    \item 1x 1x3 Stiftleiste
    \item 1x 2x16 Stiftleiste
    \item 1x 2x7 Stiftleiste
    \item 1x 2x3 Stiftleiste
    \item 26 Jumper
\end{itemize}

\section*{Grundprinzip beim Löten}

Für viele Schritte gilt dieselbe Vorgehensweise:
\begin{enumerate}
    \item Bauteil einsetzen
    \item zunächst nur einen Pin bzw. zwei gegenüberliegende Pins löten
    \item Ausrichtung kontrollieren
    \item gegebenenfalls korrigieren
    \item anschließend vollständig verlöten
\end{enumerate}

Dieses Vorgehen reduziert Fehler deutlich und erleichtert die Montage vor allem bei Steckleisten, Modulen und Bauteilen mit vielen Anschlüssen.

\section*{1. Raspberry Pi Pico vorbereiten}

Zunächst werden die beiden langen Stift-/Buchsenleisten mit dem Raspberry Pi Pico verlötet.

Wichtig ist dabei:
\begin{itemize}
    \item Die Leisten bestehen jeweils aus zwei zusammengesteckten Teilen.
    \item Diese sollten während des Lötens zusammengesteckt bleiben, damit die Pins sauber ausgerichtet sind.
    \item Die Seite mit dem schmaleren Kunststoffteil wird an den Raspberry Pi Pico gelötet.
\end{itemize}

\begin{figure}[H]
    \centering
    
\end{figure}

Vorgehen:
\begin{enumerate}
    \item Stiftleisten in Raspberry Pi Pico und Buzzerino-Platine einsetzen.
    \item Darauf achten, dass der Pico plan und parallel sitzt.
    \item Zunächst die vier Eckpins löten.
    \item Sitz und Ausrichtung kontrollieren.
    \item Den Pico wieder aus der Buzzerino-Platine entnehmen.
    \item Anschließend alle verbleibenden Pins vollständig verlöten.
\end{enumerate}

\begin{figure}[H]
    \centering
    
\end{figure}

\begin{figure}[H]
    \centering
    
\end{figure}

\begin{figure}[H]
    \centering
    
\end{figure}

\begin{figure}[H]
    \centering
    
\end{figure}

\begin{figure}[H]
    \centering
    
\end{figure}

\section*{2. USB-C-Breakout-Board vorbereiten}

Als Nächstes wird die 1x4-Stiftleiste an das USB-C-Breakout-Board gelötet.

\begin{figure}[H]
    \centering
    
\end{figure}

Vorgehen:
\begin{enumerate}
    \item Stiftleiste in das Breakout-Board einsetzen.
    \item Zunächst nur einen Pin löten.
    \item Ausrichtung prüfen; die Leiste sollte senkrecht zur Platine stehen.
    \item Falls nötig die erste Lötstelle erneut erwärmen und die Position korrigieren.
    \item Danach alle Pins vollständig löten.
\end{enumerate}

\begin{figure}[H]
    \centering
    
\end{figure}

\begin{figure}[H]
    \centering
    
\end{figure}

\begin{figure}[H]
    \centering
    
\end{figure}

\begin{figure}[H]
    \centering
    
\end{figure}

\section*{3. AHT10-Sensor vorbereiten}

Der AHT10-Sensor wird analog zum USB-C-Breakout-Board vorbereitet.

\begin{figure}[H]
    \centering
    
\end{figure}

Vorgehen:
\begin{enumerate}
    \item Stiftleiste einsetzen
    \item einen Pin löten
    \item Ausrichtung prüfen
    \item alle übrigen Pins löten
\end{enumerate}

\begin{figure}[H]
    \centering
    
\end{figure}

\section*{4. LCD-Display vorbereiten}

Das LCD-Display wird in derselben Weise vorbereitet.

\begin{figure}[H]
    \centering
    
\end{figure}

Vorgehen:
\begin{enumerate}
    \item Stiftleiste einsetzen
    \item einen Pin anlöten
    \item Ausrichtung kontrollieren
    \item anschließend vollständig verlöten
\end{enumerate}

\begin{figure}[H]
    \centering
    
\end{figure}

\begin{figure}[H]
    \centering
    
\end{figure}

\section*{5. Widerstände einbauen}

Die Widerstände werden direkt auf der Buzzerino-Platine montiert. Vor dem Einsetzen müssen die Anschlussdrähte passend gebogen werden.

Allgemeines Vorgehen:
\begin{enumerate}
    \item Anschlussdrähte U-förmig biegen
    \item Bauteil einsetzen
    \item Drähte auf der Rückseite leicht spreizen, damit das Bauteil nicht herausfällt
    \item zunächst einen Anschluss löten
    \item Sitz kontrollieren
    \item zweiten Anschluss löten
    \item Drahtenden bündig kürzen
\end{enumerate}

\subsection*{5.1 NTC-Widerstand}

Der 100-k$\Omega$-NTC ist an seinem kleinen Glasgehäuse ohne Farbringe zu erkennen. Er wird an der Position \textbf{TH\_NTC} eingesetzt.

Wichtig:
\begin{itemize}
    \item Die bedruckte Seite der Platine ist die Vorderseite.
    \item In der linken unteren Ecke sollte das DIGITEC-Logo sichtbar sein.
\end{itemize}

\begin{figure}[H]
    \centering
    
\end{figure}

\begin{figure}[H]
    \centering
    
\end{figure}

\begin{figure}[H]
    \centering
    
\end{figure}

\begin{figure}[H]
    \centering
    
\end{figure}

\begin{figure}[H]
    \centering
    
\end{figure}

\begin{figure}[H]
    \centering
    
\end{figure}

\begin{figure}[H]
    \centering
    
\end{figure}

\begin{figure}[H]
    \centering
    
\end{figure}

\begin{figure}[H]
    \centering
    
\end{figure}

\begin{figure}[H]
    \centering
    
\end{figure}

\subsection*{5.2 1-k$\Omega$-Widerstand}

Farbcodierung:
\begin{itemize}
    \item Braun
    \item Schwarz
    \item Rot
    \item Gold
\end{itemize}

\begin{figure}[H]
    \centering
    
\end{figure}

\begin{figure}[H]
    \centering
    
\end{figure}

\begin{figure}[H]
    \centering
    
\end{figure}

\subsection*{5.3 10-k$\Omega$-Widerstand}

Farbcodierung:
\begin{itemize}
    \item Braun
    \item Schwarz
    \item Orange
    \item Gold
\end{itemize}

\begin{figure}[H]
    \centering
    
\end{figure}

\begin{figure}[H]
    \centering
    
\end{figure}

\begin{figure}[H]
    \centering
    
\end{figure}

\subsection*{5.4 330-$\Omega$-Widerstände}

Farbcodierung:
\begin{itemize}
    \item Orange
    \item Orange
    \item Schwarz
    \item Schwarz
    \item Braun
\end{itemize}

Von diesen Widerständen werden fünf Stück eingebaut.

\begin{figure}[H]
    \centering
    
\end{figure}

\begin{figure}[H]
    \centering
    
\end{figure}

\begin{figure}[H]
    \centering
    
\end{figure}

\begin{figure}[H]
    \centering
    
\end{figure}

\subsection*{5.5 120-k$\Omega$-Widerstand}

Farbcodierung:
\begin{itemize}
    \item Braun
    \item Rot
    \item Gelb
    \item Gold
\end{itemize}

\begin{figure}[H]
    \centering
    
\end{figure}

\begin{figure}[H]
    \centering
    
\end{figure}

\begin{figure}[H]
    \centering
    
\end{figure}

\section*{6. Taster einbauen}

Als Nächstes werden die fünf Taster montiert.

\begin{itemize}
    \item ein Reset-Taster
    \item vier Taster für das D-Pad
\end{itemize}

Wichtig ist, dass die Taster vollständig eingesetzt sind und plan auf der Platine aufliegen, bevor sie verlötet werden.

\begin{figure}[H]
    \centering
    
\end{figure}

\begin{figure}[H]
    \centering
    
\end{figure}

\begin{figure}[H]
    \centering
    
\end{figure}

\begin{figure}[H]
    \centering
    
\end{figure}

\section*{7. Stiftleisten auf die Hauptplatine löten}

Nun werden mehrere Stiftleisten direkt auf die Buzzerino-Platine gelötet.

\textbf{Wichtiger Hinweis:}  
Die \textbf{kurze Seite} der Pins muss durch die Platine gesteckt werden. Das ist eine häufige Fehlerquelle.

Einzubauen sind:
\begin{itemize}
    \item 2x7-Stiftleiste
    \item 2x3-Stiftleiste
    \item 2x16-Stiftleiste
    \item 1x3-Stiftleiste
\end{itemize}

Empfohlenes Vorgehen:
\begin{enumerate}
    \item Leiste einsetzen
    \item zunächst einen Pin löten
    \item Sitz und Rechtwinkligkeit kontrollieren
    \item gegebenenfalls korrigieren
    \item restliche Pins verlöten
\end{enumerate}

\begin{figure}[H]
    \centering
    
\end{figure}

\begin{figure}[H]
    \centering
    
\end{figure}

\begin{figure}[H]
    \centering
    
\end{figure}

\begin{figure}[H]
    \centering
    
\end{figure}

\begin{figure}[H]
    \centering
    
\end{figure}

\begin{figure}[H]
    \centering
    
\end{figure}

\begin{figure}[H]
    \centering
    
\end{figure}

\begin{figure}[H]
    \centering
    
\end{figure}

\begin{figure}[H]
    \centering
    
\end{figure}

\section*{8. USB-C-Breakout-Board einbauen}

Das vorbereitete USB-C-Breakout-Board wird an der rechten Seite der Hauptplatine montiert. Der USB-Anschluss muss nach außen zeigen und vollständig sichtbar sein.

Vorgehen:
\begin{enumerate}
    \item Modul einsetzen
    \item einen Pin löten
    \item Ausrichtung kontrollieren; das Modul sollte parallel zur Hauptplatine stehen
    \item anschließend vollständig verlöten
\end{enumerate}

\textbf{Hinweis:} Die Pins dieses Moduls sind relativ hart. Zum Kürzen sollte ein größerer Drahtschneider verwendet werden.

\begin{figure}[H]
    \centering
    
\end{figure}

\begin{figure}[H]
    \centering
    
\end{figure}

\begin{figure}[H]
    \centering
    
\end{figure}

\begin{figure}[H]
    \centering
    
\end{figure}

\section*{9. AHT10-Sensor einbauen}

Der AHT10-Sensor wird auf der linken Seite der Hauptplatine montiert. Die Bauteile auf dem Sensormodul sollten sichtbar nach außen zeigen.

Vorgehen:
\begin{enumerate}
    \item Sensor einsetzen
    \item einen Pin löten
    \item Ausrichtung kontrollieren
    \item vollständig verlöten
\end{enumerate}

Auch hier gilt: zum Kürzen der Pins besser einen größeren Drahtschneider verwenden.

\begin{figure}[H]
    \centering
    
\end{figure}

\begin{figure}[H]
    \centering
    
\end{figure}

\section*{10. Buzzer einbauen}

Der Buzzer ist ein \textbf{polarisiertes} Bauteil und muss korrekt ausgerichtet werden.

Beachte:
\begin{itemize}
    \item Auf der Platine ist die positive Seite mit \textbf{+} markiert.
    \item Auf dem Buzzer ist die positive Seite ebenfalls markiert.
    \item Der längere Anschlussdraht ist der Pluspol.
\end{itemize}

Beim Einsetzen müssen diese Merkmale übereinstimmen.

\begin{figure}[H]
    \centering
    
\end{figure}

\begin{figure}[H]
    \centering
    
\end{figure}

\section*{11. LCD-Display einbauen}

Das vorbereitete LCD-Display wird analog zu den anderen Modulen montiert.

Vorgehen:
\begin{enumerate}
    \item Display einsetzen
    \item einen Pin löten
    \item Sitz und Ausrichtung kontrollieren
    \item vollständig verlöten
\end{enumerate}

Zum Kürzen der Pins sollte ebenfalls ein größerer Drahtschneider verwendet werden.

\begin{figure}[H]
    \centering
    
\end{figure}

\begin{figure}[H]
    \centering
    
\end{figure}

\begin{figure}[H]
    \centering
    
\end{figure}

\begin{figure}[H]
    \centering
    
\end{figure}

\section*{12. RGB-LED einbauen}

Auch die RGB-LED ist polarisiert und muss korrekt eingesetzt werden.

Wichtig:
\begin{itemize}
    \item Das längste Bein ist hier der Minuspol.
    \item Auf der Platine ist der Minuspol durch ein quadratisches Pad gekennzeichnet.
\end{itemize}

Nach dem Löten und Kürzen der Anschlüsse kann die Lötstelle optisch unregelmäßig aussehen. In diesem Fall kann sie vorsichtig nacherwärmt werden. Dabei ist unbedingt darauf zu achten, dass keine Lötbrücken zwischen benachbarten Pins entstehen.

\begin{figure}[H]
    \centering
    
\end{figure}

\begin{figure}[H]
    \centering
    
\end{figure}

\begin{figure}[H]
    \centering
    
\end{figure}

\begin{figure}[H]
    \centering
    
\end{figure}

\begin{figure}[H]
    \centering
    
\end{figure}

\begin{figure}[H]
    \centering
    
\end{figure}

\section*{13. Raspberry Pi Pico einbauen}

Jetzt wird der vorbereitete Raspberry Pi Pico auf die Hauptplatine gesetzt.

Empfohlenes Vorgehen:
\begin{enumerate}
    \item Pico einsetzen
    \item zunächst zwei gegenüberliegende Pins löten
    \item Ausrichtung kontrollieren
    \item danach alle übrigen Pins löten
\end{enumerate}

\begin{figure}[H]
    \centering
    
\end{figure}

\begin{figure}[H]
    \centering
    
\end{figure}

\begin{figure}[H]
    \centering
    
\end{figure}

\section*{14. Joystick einbauen}

Der Joystick ist das letzte Bauteil und wegen seiner vielen Anschlüsse mechanisch etwas anspruchsvoller.

Vorgehen:
\begin{enumerate}
    \item Bauteil vorsichtig ansetzen
    \item zunächst die Tasterpins und danach die übrigen Pins in Position bringen
    \item das Bauteil vollständig einsetzen
    \item anschließend alle Pins verlöten
\end{enumerate}

Hier ist etwas Geduld hilfreich. Nicht mit Gewalt arbeiten; stattdessen das Bauteil langsam ausrichten.

\begin{figure}[H]
    \centering
    
\end{figure}

\begin{figure}[H]
    \centering
    
\end{figure}

\begin{figure}[H]
    \centering
    
\end{figure}

\begin{figure}[H]
    \centering
    
\end{figure}

\begin{figure}[H]
    \centering
    
\end{figure}

\section*{15. Jumper einsetzen}

Vor dem Testen der Platine müssen alle \textbf{26 Jumper} eingesetzt werden.

\begin{figure}[H]
    \centering
    
\end{figure}

Erst danach ist das System vollständig aufgebaut.

\section*{Abschluss}

Wenn alle Bauteile korrekt montiert und alle Jumper gesetzt sind, ist der Hardware-Aufbau abgeschlossen.

\textbf{Empfehlung vor dem ersten Einschalten:}
\begin{itemize}
    \item Sichtprüfung aller Lötstellen
    \item Kontrolle auf vergessene oder vertauschte Bauteile
    \item Kontrolle auf Lötbrücken, insbesondere bei eng beieinanderliegenden Pins
    \item Kontrolle der Polung bei Buzzer und RGB-LED
\end{itemize}

\section*{Programm aufspielen}

Falls auf dem Raspberry Pi Pico noch keine passende Firmware vorhanden ist, kann z.\,B. die Datei \texttt{self\_test.uf2} aufgespielt werden.

Vorgehen:
\begin{enumerate}
    \item BOOTSEL-Taste auf dem Raspberry Pi Pico gedrückt halten
    \item Pico per USB mit dem Rechner verbinden
    \item warten, bis das Laufwerk \textbf{RPI-RP2} erscheint
    \item \texttt{.uf2}-Datei auf dieses Laufwerk kopieren
    \item der Pico startet danach automatisch neu
\end{enumerate}

\section*{Praktische Hinweise}

\begin{itemize}
    \item Kurze, saubere Lötzeiten sind besser als langes Erhitzen.
    \item Bei Unsicherheit zunächst nur einen Pin löten und die Lage prüfen.
    \item Drahtenden immer erst nach erfolgreicher Positionierung kürzen.
    \item Wenn etwas nicht passt, nicht mit Kraft arbeiten, sondern die Ausrichtung erneut prüfen.
\end{itemize}

\end{document}

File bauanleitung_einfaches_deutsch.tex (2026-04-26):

\documentclass[a4paper,11pt]{article}

\usepackage[utf8]{inputenc}
\usepackage[T1]{fontenc}
\usepackage[ngerman]{babel}
\usepackage[a4paper,margin=2.5cm]{geometry}
\usepackage{graphicx}
\usepackage{float}
\usepackage{hyperref}
\usepackage{enumitem}
\usepackage{longtable}
\usepackage{array}
\usepackage{xcolor}
\usepackage{parskip}

\hypersetup{
    colorlinks=true,
    linkcolor=blue,
    urlcolor=blue
}

\title{Buzzerino -- einfache Bauanleitung}
\author{}
\date{}

\begin{document}

\maketitle

Hier lernst du Schritt für Schritt, wie du den \textbf{Buzzerino} zusammenbaust.

\section*{Bevor du anfängst}

Lege dir alles ordentlich auf den Tisch.\\
Du brauchst:

\begin{itemize}
    \item einen Lötkolben
    \item Lötzinn
    \item einen Seitenschneider
    \item am besten eine kleine Zange
    \item alle Teile aus dem Bausatz
\end{itemize}

\textbf{Wichtig:}
\begin{itemize}
    \item Arbeite langsam und in Ruhe.
    \item Der Lötkolben ist \textbf{sehr heiß}. Pass gut auf deine Finger auf.
    \item Frage eine Lehrkraft oder eine erwachsene Person, wenn du unsicher bist.
\end{itemize}

\section*{Das ist im Bausatz drin}

\begin{figure}[H]
    \centering
    
\end{figure}

Prüfe zuerst, ob alle Teile da sind:

\begin{itemize}
    \item 1x Buzzerino-Platine
    \item 1x Raspberry Pi Pico
    \item 1x 1602A-LCD-Display
    \item 1x AHT10 Temperatur- und Luftfeuchtigkeitssensor
    \item 1x USB-C-Breakout-Board
    \item 1x 10 mm RGB-LED
    \item 1x Buzzer
    \item 1x analoger Joystick
    \item 5x Taster
    \item 1x 100-k$\Omega$-NTC
    \item 5x 330-$\Omega$-Widerstände
    \item 1x 1-k$\Omega$-Widerstand
    \item 1x 10-k$\Omega$-Widerstand
    \item 1x 120-k$\Omega$-Widerstand
    \item verschiedene Stiftleisten
    \item 26 Jumper
\end{itemize}

\section*{So lötest du richtig}

Wenn du zwei Teile verlöten willst:

\begin{enumerate}
    \item Stecke das Teil in die richtige Position.
    \item Drehe die Platine vorsichtig um.
    \item Halte den Lötkolben an den Pin und an die Lötstelle.
    \item Gib dann ein wenig Lötzinn dazu.
    \item Nimm zuerst das Lötzinn weg, dann den Lötkolben.
    \item Lass alles kurz abkühlen.
\end{enumerate}

\textbf{Tipp:}
\begin{itemize}
    \item Erst \textbf{einen Pin} löten.
    \item Dann schauen, ob das Teil gerade sitzt.
    \item Danach die restlichen Pins löten.
\end{itemize}

\section*{Schritt-für-Schritt-Aufbau}

\subsection*{1. Raspberry Pi Pico vorbereiten}

Zuerst werden die beiden langen Stiftleisten an den Raspberry Pi Pico gelötet.

\textbf{Wichtig:}
\begin{itemize}
    \item Die Stiftleisten bestehen aus zwei zusammengesteckten Teilen.
    \item \textbf{Lass sie zusammengesteckt.}
    \item So bleiben die Pins gerade.
\end{itemize}

\begin{figure}[H]
    \centering
    
\end{figure}

So geht’s:
\begin{enumerate}
    \item Stecke die beiden Stiftleisten in den Raspberry Pi Pico.
    \item Stecke das Ganze zusätzlich in die Buzzerino-Platine, damit alles gerade ausgerichtet ist.
    \item Löte zuerst die \textbf{vier Eckpins}.
    \item Prüfe, ob alles gerade sitzt.
    \item Ziehe den Raspberry Pi Pico wieder heraus.
    \item Löte jetzt alle übrigen Pins fest.
\end{enumerate}

\begin{figure}[H]
    \centering
    
\end{figure}

\begin{figure}[H]
    \centering
    
\end{figure}

\begin{figure}[H]
    \centering
    
\end{figure}

\begin{figure}[H]
    \centering
    
\end{figure}

\begin{figure}[H]
    \centering
    
\end{figure}

\subsection*{2. USB-C-Breakout-Board vorbereiten}

Jetzt bekommt das USB-C-Breakout-Board eine kleine Stiftleiste.

\begin{figure}[H]
    \centering
    
\end{figure}

So geht’s:
\begin{enumerate}
    \item Stecke die 1x4-Stiftleiste in das Board.
    \item Löte zuerst nur \textbf{einen Pin}.
    \item Prüfe, ob die Stiftleiste gerade steht.
    \item Falls sie schief ist: Lötstelle nochmal kurz erhitzen und gerade richten.
    \item Löte dann alle Pins fest.
\end{enumerate}

\begin{figure}[H]
    \centering
    
\end{figure}

\begin{figure}[H]
    \centering
    
\end{figure}

\begin{figure}[H]
    \centering
    
\end{figure}

\begin{figure}[H]
    \centering
    
\end{figure}

\subsection*{3. AHT10-Sensor vorbereiten}

Der AHT10-Sensor wird fast genauso vorbereitet wie das USB-C-Breakout-Board.

\begin{figure}[H]
    \centering
    
\end{figure}

So geht’s:
\begin{enumerate}
    \item Stiftleiste einstecken.
    \item Einen Pin löten.
    \item Gerade ausrichten.
    \item Alle Pins fertig löten.
\end{enumerate}

\begin{figure}[H]
    \centering
    
\end{figure}

\subsection*{4. LCD-Display vorbereiten}

Auch das Display bekommt zuerst seine Stiftleiste.

\begin{figure}[H]
    \centering
    
\end{figure}

So geht’s:
\begin{enumerate}
    \item Stiftleiste einstecken.
    \item Einen Pin löten.
    \item Prüfen, ob alles gerade ist.
    \item Alle Pins festlöten.
\end{enumerate}

\begin{figure}[H]
    \centering
    
\end{figure}

\begin{figure}[H]
    \centering
    
\end{figure}

\subsection*{5. Widerstände einbauen}

Jetzt kommen die kleinen Widerstände auf die Platine.

\subsubsection*{Wichtig}
Die Drähte der Widerstände müssen vorher gebogen werden.

So geht’s:
\begin{enumerate}
    \item Biege die beiden Drahtenden vorsichtig nach unten, sodass eine U-Form entsteht.
    \item Stecke den Widerstand an die passende Stelle auf der Platine.
    \item Biege die Drähte auf der Rückseite leicht auseinander, damit er nicht herausfällt.
    \item Löte erst ein Bein fest.
    \item Prüfe, ob der Widerstand schön anliegt.
    \item Löte das zweite Bein.
    \item Schneide die überstehenden Drähte ab.
\end{enumerate}

\subsubsection*{5a. NTC-Widerstand einbauen}

Der NTC ist ein besonderer Temperaturwiderstand.

Merkmal:
\begin{itemize}
    \item Er hat ein \textbf{Glasgehäuse}
    \item Er hat \textbf{keine Farbringe}
\end{itemize}

Stecke ihn an die Stelle \textbf{TH\_NTC}.

\textbf{Wichtig:}
\begin{itemize}
    \item Die \textbf{bedruckte Seite} der Platine ist die Vorderseite.
    \item Unten links sollte das \textbf{DIGITEC-Logo} zu sehen sein.
\end{itemize}

\begin{figure}[H]
    \centering
    
\end{figure}

\begin{figure}[H]
    \centering
    
\end{figure}

\begin{figure}[H]
    \centering
    
\end{figure}

\begin{figure}[H]
    \centering
    
\end{figure}

\begin{figure}[H]
    \centering
    
\end{figure}

\begin{figure}[H]
    \centering
    
\end{figure}

\begin{figure}[H]
    \centering
    
\end{figure}

\begin{figure}[H]
    \centering
    
\end{figure}

\begin{figure}[H]
    \centering
    
\end{figure}

\begin{figure}[H]
    \centering
    
\end{figure}

\subsubsection*{5b. 1-k$\Omega$-Widerstand einbauen}

Farbringe:
\begin{itemize}
    \item Braun
    \item Schwarz
    \item Rot
    \item Gold
\end{itemize}

Diesen Widerstand an die passende markierte Stelle setzen und einlöten.

\begin{figure}[H]
    \centering
    
\end{figure}

\begin{figure}[H]
    \centering
    
\end{figure}

\begin{figure}[H]
    \centering
    
\end{figure}

\subsubsection*{5c. 10-k$\Omega$-Widerstand einbauen}

Farbringe:
\begin{itemize}
    \item Braun
    \item Schwarz
    \item Orange
    \item Gold
\end{itemize}

Auch hier:
\begin{itemize}
    \item biegen
    \item einsetzen
    \item löten
    \item Drähte abschneiden
\end{itemize}

\begin{figure}[H]
    \centering
    
\end{figure}

\begin{figure}[H]
    \centering
    
\end{figure}

\begin{figure}[H]
    \centering
    
\end{figure}

\subsubsection*{5d. 330-$\Omega$-Widerstände einbauen}

Farbringe:
\begin{itemize}
    \item Orange
    \item Orange
    \item Schwarz
    \item Schwarz
    \item Braun
\end{itemize}

Davon gibt es \textbf{fünf Stück}.\\
Baue alle nacheinander ein.

\begin{figure}[H]
    \centering
    
\end{figure}

\begin{figure}[H]
    \centering
    
\end{figure}

\begin{figure}[H]
    \centering
    
\end{figure}

\begin{figure}[H]
    \centering
    
\end{figure}

\subsubsection*{5e. 120-k$\Omega$-Widerstand einbauen}

Farbringe:
\begin{itemize}
    \item Braun
    \item Rot
    \item Gelb
    \item Gold
\end{itemize}

Auch diesen wie die anderen Widerstände einbauen.

\begin{figure}[H]
    \centering
    
\end{figure}

\begin{figure}[H]
    \centering
    
\end{figure}

\begin{figure}[H]
    \centering
    
\end{figure}

\subsection*{6. Taster einbauen}

Jetzt kommen die fünf Taster auf die Platine.

So gehst du vor:
\begin{enumerate}
    \item Stecke einen Taster in die richtige Position.
    \item Drücke ihn ganz hinein, damit er flach auf der Platine sitzt.
    \item Löte die Pins fest.
    \item Wiederhole das mit den anderen Tastern.
\end{enumerate}

Es gibt:
\begin{itemize}
    \item einen Reset-Taster
    \item vier D-Pad-Taster
\end{itemize}

\textbf{Wichtig:}
Die Taster sollen \textbf{möglichst flach} auf der Platine sitzen.

\begin{figure}[H]
    \centering
    
\end{figure}

\begin{figure}[H]
    \centering
    
\end{figure}

\begin{figure}[H]
    \centering
    
\end{figure}

\begin{figure}[H]
    \centering
    
\end{figure}

\subsection*{7. Stiftleisten auf die Hauptplatine löten}

Jetzt kommen mehrere Stiftleisten direkt auf die Buzzerino-Platine.

\textbf{Wichtig:}
\textbf{Die kurze Seite der Pins muss durch die Platine gesteckt werden.}

Das ist sehr wichtig und wird oft falsch gemacht.

Löte nacheinander:
\begin{itemize}
    \item die 2x7-Stiftleiste
    \item die 2x3-Stiftleiste
    \item die 2x16-Stiftleiste
    \item die 1x3-Stiftleiste
\end{itemize}

So gehst du immer vor:
\begin{enumerate}
    \item Stiftleiste einsetzen
    \item einen Pin löten
    \item prüfen, ob sie gerade sitzt
    \item falls nötig korrigieren
    \item alle restlichen Pins löten
\end{enumerate}

\begin{figure}[H]
    \centering
    
\end{figure}

\begin{figure}[H]
    \centering
    
\end{figure}

\begin{figure}[H]
    \centering
    
\end{figure}

\begin{figure}[H]
    \centering
    
\end{figure}

\begin{figure}[H]
    \centering
    
\end{figure}

\begin{figure}[H]
    \centering
    
\end{figure}

\begin{figure}[H]
    \centering
    
\end{figure}

\begin{figure}[H]
    \centering
    
\end{figure}

\begin{figure}[H]
    \centering
    
\end{figure}

\subsection*{8. USB-C-Breakout-Board einbauen}

Jetzt kommt das vorbereitete USB-C-Breakout-Board auf die große Platine.

So geht’s:
\begin{enumerate}
    \item Stecke es an die richtige Stelle auf der rechten Seite der Platine.
    \item Der USB-Anschluss soll nach außen zeigen und gut sichtbar sein.
    \item Löte zuerst einen Pin.
    \item Prüfe, ob das Board gerade und parallel zur Platine steht.
    \item Löte dann alle Pins.
\end{enumerate}

\textbf{Achtung:}\\
Die Pins sind härter als normale Drahtenden.\\
Benutze dafür einen \textbf{größeren Seitenschneider}.

\begin{figure}[H]
    \centering
    
\end{figure}

\begin{figure}[H]
    \centering
    
\end{figure}

\begin{figure}[H]
    \centering
    
\end{figure}

\begin{figure}[H]
    \centering
    
\end{figure}

\subsection*{9. AHT10-Sensor einbauen}

Jetzt kommt der vorbereitete AHT10-Sensor auf die Platine.

So geht’s:
\begin{enumerate}
    \item Setze ihn auf der linken Seite ein.
    \item Die kleinen Bauteile auf dem Sensor sollen sichtbar sein.
    \item Löte zuerst einen Pin.
    \item Richte ihn gerade aus.
    \item Löte alle Pins fest.
\end{enumerate}

Auch hier:
\begin{itemize}
    \item zum Kürzen besser einen größeren Schneider benutzen
\end{itemize}

\begin{figure}[H]
    \centering
    
\end{figure}

\begin{figure}[H]
    \centering
    
\end{figure}

\subsection*{10. Buzzer einbauen}

Jetzt kommt der Buzzer auf die Platine.

\textbf{Wichtig:}
Der Buzzer ist \textbf{gepolt}. Das bedeutet: Er muss richtig herum eingebaut werden.

Achte auf das \textbf{Pluszeichen}:
\begin{itemize}
    \item Auf der Platine ist ein \textbf{+}
    \item Auf dem Buzzer ist auch ein \textbf{+}
\end{itemize}

Diese beiden müssen zusammenpassen.

Merke:
\begin{itemize}
    \item Der \textbf{längere Draht} ist der \textbf{Pluspol}
\end{itemize}

Dann:
\begin{enumerate}
    \item richtig herum einsetzen
    \item festlöten
\end{enumerate}

\begin{figure}[H]
    \centering
    
\end{figure}

\begin{figure}[H]
    \centering
    
\end{figure}

\subsection*{11. LCD-Display einbauen}

Jetzt wird das vorbereitete LCD-Display eingesetzt.

So geht’s:
\begin{enumerate}
    \item In die richtige Position stecken
    \item einen Pin löten
    \item prüfen, ob es gerade sitzt
    \item alle Pins fertig löten
\end{enumerate}

Auch hier gilt:
\begin{itemize}
    \item Für das Kürzen der Pins lieber den größeren Schneider benutzen.
\end{itemize}

\begin{figure}[H]
    \centering
    
\end{figure}

\begin{figure}[H]
    \centering
    
\end{figure}

\begin{figure}[H]
    \centering
    
\end{figure}

\begin{figure}[H]
    \centering
    
\end{figure}

\subsection*{12. RGB-LED einbauen}

Jetzt kommt die bunte LED.

Auch sie muss richtig herum eingebaut werden.

\textbf{Wichtig:}
\begin{itemize}
    \item Die LED ist \textbf{gepolt}
    \item Hier ist das \textbf{längste Bein der Minuspol}
    \item Auf der Platine zeigt ein \textbf{quadratisches Lötpad} den Minuspol
\end{itemize}

So geht’s:
\begin{enumerate}
    \item LED richtig herum einsetzen
    \item festlöten
    \item Drähte abschneiden
\end{enumerate}

Falls die Lötstelle nicht schön aussieht:
\begin{itemize}
    \item mit dem Lötkolben vorsichtig nochmal erwärmen
\end{itemize}

Aber ganz wichtig:
\begin{itemize}
    \item Prüfe danach, ob keine zwei Pins aus Versehen mit Lötzinn verbunden sind.
\end{itemize}

\begin{figure}[H]
    \centering
    
\end{figure}

\begin{figure}[H]
    \centering
    
\end{figure}

\begin{figure}[H]
    \centering
    
\end{figure}

\begin{figure}[H]
    \centering
    
\end{figure}

\begin{figure}[H]
    \centering
    
\end{figure}

\begin{figure}[H]
    \centering
    
\end{figure}

\subsection*{13. Raspberry Pi Pico einbauen}

Jetzt wird der vorbereitete Raspberry Pi Pico auf die Platine gesetzt.

So geht’s:
\begin{enumerate}
    \item Pico in die richtige Position stecken
    \item zuerst \textbf{zwei gegenüberliegende Pins} löten
    \item prüfen, ob alles gerade sitzt
    \item dann alle restlichen Pins löten
\end{enumerate}

\begin{figure}[H]
    \centering
    
\end{figure}

\begin{figure}[H]
    \centering
    
\end{figure}

\begin{figure}[H]
    \centering
    
\end{figure}

\subsection*{14. Joystick einbauen}

Der Joystick kommt ganz zum Schluss.

Er hat viele Pins. Deshalb ist dieser Schritt etwas knifflig.

So geht’s:
\begin{enumerate}
    \item Setze zuerst die passenden Pins vorsichtig in die Löcher ein.
    \item Bewege den Joystick langsam ein wenig hin und her, bis alle Pins richtig sitzen.
    \item Drücke ihn ganz hinein.
    \item Löte dann alle Pins fest.
\end{enumerate}

\begin{figure}[H]
    \centering
    
\end{figure}

\begin{figure}[H]
    \centering
    
\end{figure}

\begin{figure}[H]
    \centering
    
\end{figure}

\begin{figure}[H]
    \centering
    
\end{figure}

\begin{figure}[H]
    \centering
    
\end{figure}

\subsection*{15. Jumper einsetzen}

Bevor du die Platine testen kannst, musst du noch alle \textbf{26 Jumper} einsetzen.

Stecke sie so auf wie in der Vorlage bzw. auf dem Bild in der Originalanleitung.

Erst danach ist die Platine vollständig bereit.

\begin{figure}[H]
    \centering
    
\end{figure}

\section*{Geschafft!}

\textbf{Herzlichen Glückwunsch!}\\
Du hast den Buzzerino zusammengebaut.

\section*{Programm aufspielen}

Wenn auf dem Raspberry Pi Pico noch kein Programm ist, kannst du eine Datei wie \texttt{self\_test.uf2} darauf kopieren.

So geht’s:
\begin{enumerate}
    \item Halte die \textbf{BOOTSEL-Taste} auf dem Raspberry Pi Pico gedrückt.
    \item Verbinde den Pico mit einem USB-Kabel mit dem Computer.
    \item Am Computer erscheint ein Laufwerk mit dem Namen \textbf{RPI-RP2}.
    \item Ziehe die \texttt{.uf2}-Datei auf dieses Laufwerk.
    \item Danach startet der Pico automatisch neu.
\end{enumerate}

\section*{Noch ein paar einfache Tipps}

\begin{itemize}
    \item Löte lieber \textbf{langsam und sauber} als schnell.
    \item Wenn etwas schief sitzt: erst korrigieren, dann weiterlöten.
    \item Schneide Drahtenden immer erst ab, wenn alles richtig sitzt.
    \item Wenn du unsicher bist, frage nach Hilfe.
\end{itemize}

\end{document}

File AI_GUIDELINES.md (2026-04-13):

# AI Guidelines for Constructive Support in the Buzzerino Project

## Purpose of this document

This document defines how an AI model should assist users working with the **Buzzerino** soldering and programming kit.

The AI shall act as a **careful, transparent, and technically clean assistant**.  
Its purpose is **not only to produce solutions**, but to help users **understand**, **document**, and **implement** their work in a reproducible and structured way.

The AI must support both:
- **learning-oriented guidance**
- **goal-oriented problem solving**

while always being explicit about assumptions, dependencies, and missing information.

---

## Primary behavior rules for the AI model

### 1. Always clarify the desired support mode
At the beginning of every conversation, after reading this file, the AI **must ask** the user which role it should take:

- **Explaining tutor**  
  The AI explains concepts, steps, and code in a teaching-oriented way.
- **Problem-solving mentor**  
  The AI focuses on efficiently solving the concrete task, while still documenting the solution properly.

Suggested wording:

> Möchtest du, dass ich eher als **erklärende*r Tutor*in** oder als **problemlösende*r Mentor*in** auftrete?

If the user does not decide, the AI should briefly explain the difference and ask again.

---

### 2. Prefer one clarifying question too many over one incomplete answer
If important information is missing, ambiguous, or only implied, the AI **must ask follow-up questions first**.

The AI shall **not** jump directly to a half-fitting answer when central details are unknown.

Examples of missing information that require questions:
- Which IDE should be used? (**Arduino IDE** or **VS Code with Raspberry Pi Pico extension**)
- Which operating system is used?
- Is the board already soldered and tested?
- Is a specific example program or hardware component the target?
- Should the solution be beginner-friendly or concise?
- Should code be written in **Arduino style** or **Pico SDK / C/C++ style**?

Rule of thumb:

> If the implementation depends on assumptions, ask first.

---

### 3. Explain and document all action steps and tools clearly
The AI must always:
- explain **what** is being done,
- explain **why** it is being done,
- name the **programs/tools** used,
- describe **where** files are created or changed,
- document **build/flash steps**,
- mention **possible sources of errors**.

This applies especially to:
- IDE setup
- board support installation
- compiling
- flashing `.uf2` files
- file/folder structure
- adding libraries or classes
- GPIO mappings
- hardware-related constraints

---

### 4. Be explicit about assumptions
If the AI has to proceed with assumptions, it must clearly label them.

Example:

> Ich nehme im Folgenden an, dass du einen Raspberry Pi Pico (nicht Pico W) verwendest und mit VS Code arbeiten möchtest. Falls das nicht stimmt, passe ich die Anleitung an.

---

### 5. Technical accuracy before speed
If the AI is unsure, it should say so.

Example:

> Ich bin mir an dieser Stelle nicht ganz sicher, ob dein Projekt auf dem Pico SDK oder auf Arduino basiert. Bitte zeig mir kurz die vorhandene Projektstruktur oder die `CMakeLists.txt` bzw. die `.ino`-Datei.

The AI should avoid inventing APIs, file names, or library behavior.

---

### 6. Code must be presented in a learnable form
Whenever code is generated, the AI should:
- use meaningful names,
- structure the code cleanly,
- add comments where they help understanding,
- explain the role of each file,
- state where the code belongs,
- explain how to build and run it.

If code is non-trivial, the AI should also provide:
- a brief architecture overview,
- dependency list,
- expected output/behavior.

---

### 7. Solutions should be adapted to the user's level
The AI should ask, if unclear:
- beginner
- intermediate
- advanced

If no level is given, default to:
- technically correct,
- beginner-friendly,
- but not overly simplified.

---

## Required conversation start

At the start of a new conversation, after reading this file, the AI should first say something like:

> Bevor wir loslegen: Ich kann dich entweder als **erklärende*r Tutor*in** oder als **problemlösende*r Mentor*in** begleiten. Welche Rolle ist dir lieber?  
> Außerdem sollten wir kurz klären, ob du mit **Arduino IDE** oder mit **VS Code + Raspberry Pi Pico Extension** arbeiten möchtest.

Then the AI should also proactively mention that a proper setup is required:

> Falls die Entwicklungsumgebung noch nicht eingerichtet ist, kann ich dir eine vollständige Schritt-für-Schritt-Anleitung für **Installation, Einrichtung und ein erstes Hello-World-Projekt** geben — inklusive Display-Klasse.

---

## Project context: Buzzerino

### Project summary
**Buzzerino** is a soldering and programming kit built around a **Raspberry Pi Pico**.  
It includes several peripherals:
- 1602A LCD display
- AHT10 temperature/humidity sensor
- buzzer
- RGB LED
- joystick
- buttons
- analogue NTC temperature sensor
- USB-C breakout
- jumper-based peripheral routing

The repository README contains:
- soldering instructions
- flashing instructions
- example program references
- coding setup hints
- hardware pin mappings

---

## Hardware mapping reference

### LCD 1602A
Parallel connection to Raspberry Pi Pico:

| GPIO | LCD |
|---|-----|
| 6 | D7  |
| 7 | D6  |
| 8 | D5  |
| 9 | D4  |
| 10 | D3  |
| 11 | D2  |
| 12 | D1  |
| 13 | D0  |
| 14 | E |
| 15 | RS  |

### AHT10
| GPIO | AHT10 |
|---|---|
| 0 | SDA |
| 1 | SCL |

I2C address: `0x38`

### Buzzer
| GPIO | Function |
|---|---|
| 19 | Buzzer |

### D-pad buttons
| GPIO | Button |
|---|---|
| 2 | up |
| 3 | down |
| 4 | left |
| 5 | right  |

### Joystick
| GPIO | Function |
|---|---|
| 18 | button |
| 31 (ADC0) | X-axis |
| 32 (ADC1) | Y-axis |

### RGB LED
| GPIO | Channel |
|---|---|
| 20 | R |
| 21 | G |
| 22 | B |

### NTC analogue temperature sensor
| GPIO | Function |
|---|---|
| 28 (ADC2) | NTC readout |

---

## Development environment policy

The AI must ask the user which environment should be used:

1. **Arduino IDE**
2. **VS Code + Raspberry Pi Pico extension**
3. **Existing project setup already available**

If unclear, ask:
- Which OS is being used? (Windows / Linux / macOS)
- Is this the first setup?
- Is the goal to use example code quickly, or to learn structured C/C++ development?

---

# IDE Setup Instructions

## Option A: Arduino IDE

### When to recommend Arduino IDE
Use Arduino IDE if:
- the user is a beginner,
- quick entry is the goal,
- the project should be kept simple,
- an `.ino`-style workflow is preferred.

### Typical Arduino IDE setup steps
1. Install the Arduino IDE.
2. Open the board manager.
3. Add Raspberry Pi Pico board support.
4. Select the correct board:
   - **Raspberry Pi Pico**
5. Connect the board.
6. Select port and board.
7. Create a first sketch.
8. Compile and upload.

### Notes
The AI should clearly explain:
- that Arduino uses `setup()` and `loop()`,
- that library handling differs from Pico SDK projects,
- that C++ classes are possible, but project structure is simpler than in full SDK projects.

---

## Option B: VS Code with Raspberry Pi Pico extension

### When to recommend VS Code
Use VS Code if:
- the user wants structured projects,
- the repository examples are intended for this workflow,
- C/C++ with Pico SDK is desired,
- long-term maintainability matters.

### Typical VS Code setup steps
1. Install **Visual Studio Code**.
2. Install the **Raspberry Pi Pico extension**.
3. Let the extension install required tools:
   - CMake
   - Ninja
   - ARM GNU Toolchain
   - Pico SDK components (depending on extension workflow)
4. Create a new Raspberry Pi Pico project.
5. Choose target board:
   - **Raspberry Pi Pico**
6. Open the generated project.
7. Build the project.
8. Produce a `.uf2` file.
9. Flash by copying the `.uf2` onto the mounted `RPI-RP2` device.

### Notes
The AI should explain:
- the role of `CMakeLists.txt`,
- where source files are located,
- where build output appears,
- how `.uf2` flashing works,
- how to add custom `.c` / `.h` files to the project.

---

# Recommended first question set

Before giving setup instructions, the AI should ask:

1. Möchtest du mit **Arduino IDE** oder mit **VS Code + Raspberry Pi Pico Extension** arbeiten?
2. Welches **Betriebssystem** nutzt du?
3. Ist die **Buzzerino-Hardware bereits fertig gelötet**?
4. Möchtest du eine **sehr ausführliche Einsteiger-Anleitung** oder eine **kompakte technische Anleitung**?
5. Soll ich dich als **Tutor*in** oder **Mentor*in** begleiten?

---

# First project template: fully commented Hello World with display class

## Goal
The first project should:
- initialize the board,
- initialize the LCD,
- display `Hello, World!`,
- use a **separate display class/module**,
- be fully commented,
- be easy to extend later.

Because the existing display code is already written in **Pico SDK style**, the default prepared example below assumes:

- **VS Code**
- **Raspberry Pi Pico extension**
- **C/C++ with Pico SDK**

If the user wants Arduino IDE instead, the AI should explicitly say that the code structure must be adapted.

---

## Recommended project structure

```text
buzzerino_hello/
├─ CMakeLists.txt
├─ lcd1602.h
├─ lcd1602.c
└─ main.c
```

---

## File: `lcd1602.h`

```c
#ifndef LCD1602_H
#define LCD1602_H

#include <stdint.h>

void lcd_init(void);
void lcd_putc(char c);
void lcd_puts(const char *s);
void lcd_cursor_visible(uint8_t on);
void lcd_cursor_blink(uint8_t on);
void lcd_cursor_left(void);
void lcd_cursor_right(void);
void lcd_gotoxy(uint8_t row, uint8_t col);

#endif
```

---

## File: `lcd1602.c`

```c
#include "lcd1602.h"
#include "pico/stdlib.h"

#define LCD_D7 6
#define LCD_D6 7
#define LCD_D5 8
#define LCD_D4 9
#define LCD_D3 10
#define LCD_D2 11
#define LCD_D1 12
#define LCD_D0 13

#define LCD_E 14
#define LCD_RS 15

// Display control state:
// Bit 2 = Display on/off
// Bit 1 = Cursor visible
// Bit 0 = Cursor blink
static uint8_t _disp_ctrl = 0x0C; // display on, cursor off, blink off

// Generates the enable pulse so the LCD accepts the current data lines.
static void lcd_pulse_e(void)
{
    gpio_put(LCD_E, 1);
    sleep_us(1); // minimum enable pulse width
    gpio_put(LCD_E, 0);
}

// Writes one full 8-bit value to the LCD data bus.
static void lcd_write8(uint8_t val)
{
    gpio_put(LCD_D0, val & 0x01);
    gpio_put(LCD_D1, val & 0x02);
    gpio_put(LCD_D2, val & 0x04);
    gpio_put(LCD_D3, val & 0x08);
    gpio_put(LCD_D4, val & 0x10);
    gpio_put(LCD_D5, val & 0x20);
    gpio_put(LCD_D6, val & 0x40);
    gpio_put(LCD_D7, val & 0x80);
    lcd_pulse_e();
}

// Sends a command byte to the LCD.
static void lcd_cmd(uint8_t cmd)
{
    gpio_put(LCD_RS, 0);
    lcd_write8(cmd);

    // Command timing according to the LCD datasheet:
    // Clear and home need longer than normal commands.
    if (cmd == 0x01 || cmd == 0x02)
        sleep_ms(2);
    else
        sleep_us(50);
}

// Sends one character byte to the LCD.
static void lcd_data(uint8_t data)
{
    gpio_put(LCD_RS, 1);
    lcd_write8(data);
    sleep_us(50);
}

void lcd_init(void)
{
    // List of all GPIO pins used by the LCD.
    const uint lcd_pins[] = {
        LCD_D0, LCD_D1, LCD_D2, LCD_D3,
        LCD_D4, LCD_D5, LCD_D6, LCD_D7,
        LCD_E, LCD_RS
    };

    // Configure all LCD pins as outputs and set them low initially.
    for (uint i = 0; i < sizeof(lcd_pins) / sizeof(lcd_pins[0]); ++i)
    {
        gpio_init(lcd_pins[i]);
        gpio_set_dir(lcd_pins[i], GPIO_OUT);
        gpio_put(lcd_pins[i], 0);
    }

    // Wait for LCD power-up stabilization.
    sleep_ms(20);

    // Initialize LCD in 8-bit mode, 2 lines, 5x8 font.
    lcd_cmd(0x38);
    lcd_cmd(0x08);       // display off during setup
    lcd_cmd(0x01);       // clear display
    lcd_cmd(0x06);       // entry mode: cursor moves right
    lcd_cmd(_disp_ctrl); // display on
}

void lcd_putc(char c)
{
    lcd_data((uint8_t)c);
}

void lcd_puts(const char *s)
{
    while (*s)
        lcd_putc(*s++);
}

void lcd_cursor_visible(uint8_t on)
{
    if (on)
        _disp_ctrl |= 0x02;
    else
        _disp_ctrl &= ~0x02;

    lcd_cmd(_disp_ctrl);
}

void lcd_cursor_blink(uint8_t on)
{
    if (on)
        _disp_ctrl |= 0x01;
    else
        _disp_ctrl &= ~0x01;

    lcd_cmd(_disp_ctrl);
}

void lcd_cursor_left(void)
{
    lcd_cmd(0x10);
}

void lcd_cursor_right(void)
{
    lcd_cmd(0x14);
}

void lcd_gotoxy(uint8_t row, uint8_t col)
{
    static const uint8_t row_addr[2] = {0x00, 0x40};
    lcd_cmd(0x80 | (row_addr[row & 1] + (col & 0x0F)));
}
```

---

## File: `main.c`

```c
#include <stdio.h>
#include "pico/stdlib.h"
#include "lcd1602.h"

int main()
{
    // Initialize the standard Pico runtime.
    // This prepares GPIO handling, timing functions, etc.
    stdio_init_all();

    // Initialize the LCD display.
    lcd_init();

    // Write a simple two-line hello world message.
    lcd_gotoxy(0, 0);
    lcd_puts("Hello, World!");

    lcd_gotoxy(1, 0);
    lcd_puts("Buzzerino ready");

    // Main loop:
    // In this very first example we do not update anything continuously.
    // We simply keep the microcontroller running.
    while (true)
    {
        sleep_ms(1000);
    }

    return 0;
}
```

---

## File: `CMakeLists.txt`

```cmake
cmake_minimum_required(VERSION 3.13)

include(pico_sdk_import.cmake)

project(buzzerino_hello C CXX ASM)

set(CMAKE_C_STANDARD 11)
set(CMAKE_CXX_STANDARD 17)

pico_sdk_init()

add_executable(buzzerino_hello
    main.c
    lcd1602.c
)

target_include_directories(buzzerino_hello PRIVATE
    ${CMAKE_CURRENT_LIST_DIR}
)

target_link_libraries(buzzerino_hello
    pico_stdlib
)

pico_add_extra_outputs(buzzerino_hello)
```

---

# Explanation of the first example

## What this project demonstrates
This first example demonstrates:
- how a Pico SDK project is structured,
- how code is split into multiple files,
- how the LCD is used via a dedicated module,
- how to display text on the Buzzerino LCD.

## Why a second class/module is useful
Separating the LCD code from `main.c` is good practice because:
- `main.c` stays readable,
- hardware access is encapsulated,
- reuse becomes easier,
- debugging is simpler,
- later extensions are cleaner.

---

# Setup walkthrough for the first project in VS Code

## Step 1: Install VS Code
Install **Visual Studio Code** from the official website.

## Step 2: Install the Raspberry Pi Pico extension
Open VS Code and install the **Raspberry Pi Pico** extension.

## Step 3: Install required toolchain components
Use the extension setup assistant to install the required development tools.

## Step 4: Create a new Pico project
Create a new project for:
- Board: **Raspberry Pi Pico**
- Language: **C**
- Project name: `buzzerino_hello`

## Step 5: Replace generated files
Replace the generated `main.c` with the example above and add:
- `lcd1602.h`
- `lcd1602.c`

Adjust `CMakeLists.txt` so that `lcd1602.c` is included.

## Step 6: Build
Run the build command from VS Code.  
A `.uf2` file should be generated in the build output.

## Step 7: Flash
Put the Pico into BOOTSEL mode:
- hold **BOOTSEL**
- connect USB or press reset while holding BOOTSEL
- the device appears as `RPI-RP2`

Copy the generated `.uf2` file onto the mounted drive.

## Step 8: Verify
The LCD should display:
- line 1: `Hello, World!`
- line 2: `Buzzerino ready`

---

# Important flashing note

The README states:

- Press and hold **BOOTSEL** on the Raspberry Pi Pico.
- Connect via USB to the PC.
- The Pico appears as a mass storage device named `RPI-RP2`.
- Copy the `.uf2` file.
- The device reboots automatically.

Alternative while already connected:
- hold **BOOTSEL**
- briefly press **SW_RESET**
- then release

---

# AI response style requirements

The AI should answer in a way that is:

- structured,
- technically correct,
- beginner-aware,
- transparent about uncertainty,
- explicit about files and tools,
- reproducible.

Preferred response format for technical tasks:

1. **Kurze Zielbeschreibung**
2. **Annahmen**
3. **Rückfragen**
4. **Schritt-für-Schritt-Anleitung**
5. **Code**
6. **Erklärung des Codes**
7. **Build-/Flash-Anleitung**
8. **Typische Fehlerquellen**
9. **Nächste sinnvolle Ausbaustufe**

---

# Typical follow-up questions the AI should ask

## For setup
- Welches Betriebssystem verwendest du?
- Arduino IDE oder VS Code?
- Ist das dein erstes Pico-Projekt?

## For hardware
- Ist die Platine komplett gelötet?
- Sind alle 26 Jumper gesetzt?
- Funktioniert das Display grundsätzlich schon?

## For code help
- Arbeitest du mit Arduino-Sketches oder mit Pico-SDK/CMake?
- Kannst du deine aktuelle Projektstruktur zeigen?
- Welche Fehlermeldung bekommst du genau?

## For learning support
- Möchtest du die Lösung direkt oder zuerst die Idee verstehen?
- Soll ich jeden Schritt didaktisch erklären oder eher kompakt bleiben?

---

# Constraints and cautions

- Do not assume Arduino and Pico SDK code are interchangeable.
- Do not invent missing repository files.
- Do not hide build steps.
- Do not omit flashing instructions.
- Do not skip clarification if the setup is unknown.
- Prefer asking questions over giving a partially wrong solution.

---

# Short startup prompt template for the AI

Suggested opening message:

> Ich helfe dir gern mit dem Buzzerino-Projekt.  
> Zuerst zwei kurze Klärungen, damit ich passend unterstützen kann:  
> 1. Soll ich eher als **erklärende*r Tutor*in** oder als **problemlösende*r Mentor*in** auftreten?  
> 2. Möchtest du mit **Arduino IDE** oder mit **VS Code + Raspberry Pi Pico Extension** arbeiten?  
>  
> Falls deine Entwicklungsumgebung noch nicht eingerichtet ist, kann ich dir direkt eine vollständige Schritt-für-Schritt-Anleitung zur Installation, Einrichtung und zu einem ersten **Hello-World-Projekt mit Display-Klasse** geben.

---

# End of document

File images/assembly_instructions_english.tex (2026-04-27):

\documentclass[a4paper,11pt]{article}

\usepackage[utf8]{inputenc}
\usepackage[T1]{fontenc}
\usepackage[english]{babel}
\usepackage[a4paper,margin=2.5cm]{geometry}
\usepackage{graphicx}
\usepackage{float}
\usepackage{hyperref}
\usepackage{enumitem}
\usepackage{parskip}
\usepackage{xcolor}

\hypersetup{
    colorlinks=true,
    linkcolor=blue,
    urlcolor=blue
}

\title{Buzzerino}
\author{}
\date{}

\begin{document}

\maketitle

\section*{Contents}
\begin{itemize}
    \item Soldering Instructions
    \item Flashing
    \item Example Programs
    \item How to Code / Work with AI
\end{itemize}

\section*{Soldering Instructions}

\begin{figure}[H]
    \centering
    
\end{figure}

\subsection*{Bill of Materials}

Please check if you have all the necessary components listed below:

\begin{itemize}
    \item 1x Buzzerino circuit board (Buzzerino PCB)
    \item 1x Raspberry Pi Pico
    \item 1x 1602A LCD display
    \item 1x AHT10 digital temperature and humidity sensor
    \item 1x USB-C breakout board
    \item 1x 10 mm RGB LED
    \item 1x buzzer
    \item 1x analogue joystick
    \item 5x 6 mm push buttons
    \item 1x 100 k$\Omega$ NTC temperature-dependent resistor
    \item 5x 330 $\Omega$ resistors
    \item 1x 1 k$\Omega$ resistor
    \item 1x 10 k$\Omega$ resistor
    \item 1x 120 k$\Omega$ resistor
    \item 2x 1x20 pin headers and sockets (keep them plugged together)
    \item 1x 1x16 pin header
    \item 2x 1x4 pin headers
    \item 1x 1x3 pin header
    \item 1x 2x16 pin header
    \item 1x 2x7 pin header
    \item 1x 2x3 pin header
    \item 26x jumper
\end{itemize}

\subsection*{Assembly of the Raspberry Pi Pico}

\begin{figure}[H]
    \centering
    
\end{figure}

We will start by soldering the two 1x20 pin headers and sockets to the Raspberry Pi Pico board. The pin strips are each two parts plugged together; keep them together, as this will keep the contacts aligned. The side with the slimmer plastic piece will be soldered to the Raspberry Pi Pico (in the picture above, the inner one).

Start by putting the pin headers into the Raspberry Pi Pico and the Buzzerino PCB. The Raspberry Pi Pico should sit flat and parallel on both pin strips.

\begin{figure}[H]
    \centering
    
\end{figure}

Now we can solder our first connections. Heat one of the corner pins with your soldering iron. Check with solder whether the joint is up to temperature by gently feeding it into the heated pin. If the solder melts, you can remove the soldering iron and let the connection cool down.

\begin{figure}[H]
    \centering
    
\end{figure}

Continue by soldering the three other corners.

\begin{figure}[H]
    \centering
    
\end{figure}

Now you can remove the Raspberry Pi Pico from the Buzzerino PCB (with the pin headers still together).

\begin{figure}[H]
    \centering
    
\end{figure}

With the Raspberry Pi Pico now free, but the pin strips still attached to it, you can fully solder both sides.

\begin{figure}[H]
    \centering
    
\end{figure}

\subsection*{Assembly of the USB-C breakout board}

\begin{figure}[H]
    \centering
    
\end{figure}

Now we will solder the 1x4 pin header to the USB-C breakout board. Because both pieces are very small, it is a good tactic to plug them together and place them on your table.

\begin{figure}[H]
    \centering
    
\end{figure}

Start by soldering only one pin, as the angle between the board and the pin header will likely be slightly crooked.

\begin{figure}[H]
    \centering
    
\end{figure}

\begin{figure}[H]
    \centering
    
\end{figure}

To correct the angle of the pin header, hold both pieces together and carefully reheat the solder joint. Now you can correct any misalignment. Once the pins are perpendicular to the board, solder all four pins.

\begin{figure}[H]
    \centering
    
\end{figure}

\subsection*{Assembly of the AHT10 digital temperature sensor}

\begin{figure}[H]
    \centering
    
\end{figure}

The assembly of the AHT10 digital temperature sensor is identical to that of the USB-C breakout board. Start by soldering only one pin and correct the alignment so it is nice and perpendicular.

\begin{figure}[H]
    \centering
    
\end{figure}

\subsection*{Assembly of the 1602A LCD display}

\begin{figure}[H]
    \centering
    
\end{figure}

The assembly of the 1602A LCD display is very similar to the previous two steps. First solder one pin, check for squareness and correct, then solder all pins.

\begin{figure}[H]
    \centering
    
\end{figure}

\begin{figure}[H]
    \centering
    
\end{figure}

\subsection*{Installation of resistors}

\subsubsection*{100 k$\Omega$ NTC temperature-dependent resistor}

The 100 k$\Omega$ NTC temperature-dependent resistor has a glass body with no markings.

\begin{figure}[H]
    \centering
    
\end{figure}

The resistors come with straight leads and need to be formed. For that purpose hold them with one hand between two fingers and pull them to a U-shape with your other hand as seen in the following pictures:

\begin{figure}[H]
    \centering
    
\end{figure}

\begin{figure}[H]
    \centering
    
\end{figure}

\begin{figure}[H]
    \centering
    
\end{figure}

\begin{figure}[H]
    \centering
    
\end{figure}

\begin{figure}[H]
    \centering
    
\end{figure}

The newly formed resistor can now be inserted into the Buzzerino PCB at the position marked \texttt{TH\_NTC}.\\
\textbf{Important:} The printed side of the Buzzerino PCB is the front of the PCB. The lower left corner should have our DIGETEC logo.

\begin{figure}[H]
    \centering
    
\end{figure}

As a tip for soldering beginners, you can slightly bend the leads outwards after fully seating the resistor. This will help keep it in place.

\begin{figure}[H]
    \centering
    
\end{figure}

Like the previous solder joints, it is good practice to start by soldering one lead first, then correct the positioning, and finally solder both.

\begin{figure}[H]
    \centering
    
\end{figure}

\begin{figure}[H]
    \centering
    
\end{figure}

After the resistor is fully seated, you can clip the leads flush with side cutters.

\subsubsection*{1 k$\Omega$ resistor}

The 1 k$\Omega$ resistor has stripes as markings (Brown | Black | Red | Gold).

\begin{figure}[H]
    \centering
    
\end{figure}

\begin{figure}[H]
    \centering
    
\end{figure}

The installation of the different resistors is essentially identical. For the 1 k$\Omega$ resistor, start by forming it roughly U-shaped.

\begin{figure}[H]
    \centering
    
\end{figure}

Then place it in its position, solder one leg, correct the placement, solder completely, and clip the leads flush.

\subsubsection*{10 k$\Omega$ resistor}

The 10 k$\Omega$ resistor has stripes as markings (Brown | Black | Orange | Gold).

\begin{figure}[H]
    \centering
    
\end{figure}

\begin{figure}[H]
    \centering
    
\end{figure}

\begin{figure}[H]
    \centering
    
\end{figure}

For the 10 k$\Omega$ resistor: form, place, solder one leg, correct, solder fully, and clip flush.

\subsubsection*{330 $\Omega$ resistors}

The 330 $\Omega$ resistors have stripes as markings (Orange | Orange | Black | Black | Brown).

\begin{figure}[H]
    \centering
    
\end{figure}

\begin{figure}[H]
    \centering
    
\end{figure}

\begin{figure}[H]
    \centering
    
\end{figure}

\begin{figure}[H]
    \centering
    
\end{figure}

For the 330 $\Omega$ resistors: form, place, solder one leg, correct, solder fully, and clip flush.

\subsubsection*{120 k$\Omega$ resistor}

The 120 k$\Omega$ resistor has stripes as markings (Brown | Red | Yellow | Gold).

\begin{figure}[H]
    \centering
    
\end{figure}

\begin{figure}[H]
    \centering
    
\end{figure}

\begin{figure}[H]
    \centering
    
\end{figure}

For the 120 k$\Omega$ resistor: form, place, solder one leg, correct, solder fully, and clip flush.

\subsection*{Installation of the buttons}

\begin{figure}[H]
    \centering
    
\end{figure}

For the assembly of the Buzzerino PCB, we will go from the shortest to the highest component. This helps you successfully solder your board.

\begin{figure}[H]
    \centering
    
\end{figure}

\begin{figure}[H]
    \centering
    
\end{figure}

The shape of the button legs is designed to snap into the Buzzerino PCB. After placing the buttons, check if they sit flush to the Buzzerino PCB. Then solder and clip the leads.

\begin{figure}[H]
    \centering
    
\end{figure}

With the D-pad buttons it is the same procedure as with the reset button.

\subsection*{Soldering the pin header}

\textbf{Repeated Error: The short side shall go through the board!}

\begin{figure}[H]
    \centering
    
\end{figure}

\begin{figure}[H]
    \centering
    
\end{figure}

We start by soldering the 2x7 pin header to the Buzzerino PCB. \textbf{The short side shall go through the board.}

\begin{figure}[H]
    \centering
    
\end{figure}

As with all the previous solder joints, it is best practice to first solder one pin and then check for alignment. The wider pin header will often move a bit out of the Buzzerino PCB and may need to be reseated. Only after the pin headers are placed completely in position should you solder the remaining pins.

\begin{figure}[H]
    \centering
    
\end{figure}

\begin{figure}[H]
    \centering
    
\end{figure}

\begin{figure}[H]
    \centering
    
\end{figure}

\begin{figure}[H]
    \centering
    
\end{figure}

Repeat the previous step for the 2x3 and 2x16 pin headers. Start by soldering one pin, then check and correct the seating, and then solder completely.

\begin{figure}[H]
    \centering
    
\end{figure}

\begin{figure}[H]
    \centering
    
\end{figure}

The 1x3 pin header is one of the fiddliest to install. With all the previous practice, you will be able to solder it flush and perpendicular.

\subsection*{Installation of the USB-C breakout board}

\begin{figure}[H]
    \centering
    
\end{figure}

\begin{figure}[H]
    \centering
    
\end{figure}

\begin{figure}[H]
    \centering
    
\end{figure}

\begin{figure}[H]
    \centering
    
\end{figure}

Now we can solder the USB-C breakout board. After placing it into position (right side of the Buzzerino PCB, facing outwards, the USB port should be fully visible), solder one pin. Then check for alignment; it should be parallel to the Buzzerino PCB. Then solder it completely.

\textbf{WARNING:} The pins of the USB-C breakout board, the AHT10 temperature sensor, and the 1602A LCD display are too hard for electronics side cutters. Use larger wire cutters as provided.

\subsection*{Installation of the AHT10 digital temperature sensor}

\begin{figure}[H]
    \centering
    
\end{figure}

\begin{figure}[H]
    \centering
    
\end{figure}

The installation of the AHT10 digital temperature sensor is analogous to the USB-C breakout board (position left side of the Buzzerino PCB, facing upwards, the components of the sub-PCB should be visible). But remember: use the larger wire cutters for cutting the pins to length.

\subsection*{Installation of the Buzzer}

\begin{figure}[H]
    \centering
    
\end{figure}

\begin{figure}[H]
    \centering
    
\end{figure}

Finally, we can install the namesake of the board. This is our first polarized component. The footprint on the Buzzerino PCB shows a small \texttt{+}. Furthermore, the sticker on the buzzer has a plus on its top. These should be aligned. (If you look from the front of the Buzzerino PCB, the plus will be facing inwards.) Moreover, if you are unsure, you can check the buzzer's leads: one of them is longer than the other. This is the positive lead and shall align with the plus symbol on the Buzzerino PCB.

\subsection*{Installation of the 1602A LCD display}

\begin{figure}[H]
    \centering
    
\end{figure}

\begin{figure}[H]
    \centering
    
\end{figure}

\begin{figure}[H]
    \centering
    
\end{figure}

\begin{figure}[H]
    \centering
    
\end{figure}

The installation of the 1602A LCD display is analogous to the USB-C breakout board. First place, then solder one pin, then check for alignment and then solder fully. But remember: use the larger wire cutters for cutting the pins to length.

\subsection*{Installation of the RGB LED}

\begin{figure}[H]
    \centering
    
\end{figure}

Now we can install the RGB LED.

\begin{figure}[H]
    \centering
    
\end{figure}

\begin{figure}[H]
    \centering
    
\end{figure}

The LED is, like the buzzer, polarized. But here the longest leg is the negative connection. The footprint on the Buzzerino PCB indicates the negative connection with a square pad. Place the LED into its position. The spacing of the pads is a bit wider than the lead spacing, so the leads will spread out automatically.

\begin{figure}[H]
    \centering
    
\end{figure}

\begin{figure}[H]
    \centering
    
\end{figure}

\begin{figure}[H]
    \centering
    
\end{figure}

After soldering and cutting the RGB LED's leads flush, you will probably have a very ugly joint. Luckily, you can easily correct this by slowly running your soldering iron between two pins and letting them reflow. The surface tension of the solder should pull the joint nicely together, resulting in a clean joint. But check for any bridges after that. If there are any, clean your soldering tip and repeat the reflow.

\subsection*{Installation of the Raspberry Pi Pico}

\begin{figure}[H]
    \centering
    
\end{figure}

\begin{figure}[H]
    \centering
    
\end{figure}

\begin{figure}[H]
    \centering
    
\end{figure}

Now we can install the Raspberry Pi Pico. As with all previous complex connections, start by soldering only two opposite pins. Then check for alignment; after that, solder completely.

\subsection*{Installation of the analogue joystick}

\begin{figure}[H]
    \centering
    
\end{figure}

\begin{figure}[H]
    \centering
    
\end{figure}

As the last component, we will install the analogue joystick.

\begin{figure}[H]
    \centering
    
\end{figure}

\begin{figure}[H]
    \centering
    
\end{figure}

The installation of the joystick can be harder than necessary because of the many different pins. Start by putting the push-button pins into the Buzzerino PCB and then wiggle each pin from left to right slowly into position. After the joystick is fully seated, you can solder it in place.

\begin{figure}[H]
    \centering
    
\end{figure}

\subsection*{Installation of the jumpers}

\begin{figure}[H]
    \centering
    
\end{figure}

Before testing the board, we need to install all 26 jumpers as seen in the picture above.

\textbf{Congratulations, you have finished your soldering project.}

If you already flashed your Raspberry Pi Pico, it is time to power it up; if not, flash the \texttt{self\_test.uf2} onto the board.

\section*{Flashing}

If the board is not connected to a power source: press and hold the \textbf{BOOTSEL} button on the Raspberry Pi Pico and connect it via micro-USB to a PC. The Pico should mount as a mass-storage device called \textbf{RPI-RP2}. Now you can drag and drop a previously compiled or downloaded \texttt{.uf2} file onto it. It will automatically unmount and reboot. Ignore the message from your PC that the device was disconnected without ejecting.

You do not need to unplug and replug the Raspberry Pi Pico every time you want to flash it. You can also, with an established connection to your PC, press and hold the \textbf{BOOTSEL} button on the Raspberry Pi Pico and then briefly press (while still holding the \textbf{BOOTSEL} button) the \textbf{SW\_RESET} button on the Buzzerino PCB.

\section*{Example Programs}

The code of the example programs and their \texttt{.uf2} files are available in the folder \texttt{example\_programs}. Unless otherwise noted, all programs are designed and compiled for the Raspberry Pi Pico (neither the W version nor version 2) but can be recompiled for these targets. The preferred way to compile is VS Code with the Raspberry Pi Pico extension.

\end{document}

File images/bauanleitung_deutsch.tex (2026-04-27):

\documentclass[a4paper,11pt]{article}

\usepackage[utf8]{inputenc}
\usepackage[T1]{fontenc}
\usepackage[ngerman]{babel}
\usepackage[a4paper,margin=2.5cm]{geometry}
\usepackage{graphicx}
\usepackage{float}
\usepackage{hyperref}
\usepackage{enumitem}
\usepackage{parskip}
\usepackage{xcolor}

\hypersetup{
    colorlinks=true,
    linkcolor=blue,
    urlcolor=blue
}

\title{Buzzerino -- Aufbauanleitung}
\author{}
\date{}

\begin{document}

\maketitle

Diese Anleitung beschreibt den Aufbau des \textbf{Buzzerino}-Bausatzes Schritt für Schritt. Sie richtet sich an Studierende ohne oder mit nur wenig Löterfahrung. Ziel ist ein sauber aufgebautes und funktionsfähiges System.

\section*{Vorbereitung}

Bevor du beginnst, solltest du deinen Arbeitsplatz sinnvoll vorbereiten. Lege alle Bauteile übersichtlich bereit und prüfe, ob das notwendige Werkzeug vorhanden ist.

Benötigt werden:
\begin{itemize}
    \item Lötkolben
    \item Lötzinn
    \item Seitenschneider
    \item ggf. kleine Flachzange
    \item alle Bauteile des Bausatzes
\end{itemize}

\textbf{Hinweise zum Arbeiten:}
\begin{itemize}
    \item Arbeite konzentriert und ohne Zeitdruck.
    \item Der Lötkolben wird sehr heiß. Vermeide jeden Kontakt mit Spitze und frisch gelöteten Stellen.
    \item Löte möglichst sauber und mit wenig, aber ausreichend Lötzinn.
    \item Bei Bauteilen mit vielen Pins empfiehlt es sich fast immer, zunächst nur einen oder zwei Pins zu löten, die Ausrichtung zu prüfen und erst danach vollständig zu verlöten.
\end{itemize}

\section*{Stückliste}

\begin{figure}[H]
    \centering
    
\end{figure}

Vor dem Aufbau sollte kontrolliert werden, ob alle Komponenten vorhanden sind:

\begin{itemize}
    \item 1x Buzzerino-Platine
    \item 1x Raspberry Pi Pico
    \item 1x 1602A-LCD-Display
    \item 1x AHT10 Temperatur- und Luftfeuchtigkeitssensor
    \item 1x USB-C-Breakout-Board
    \item 1x 10\,mm RGB-LED
    \item 1x Buzzer
    \item 1x analoger Joystick
    \item 5x Taster
    \item 1x 100-k$\Omega$-NTC
    \item 5x 330-$\Omega$-Widerstände
    \item 1x 1-k$\Omega$-Widerstand
    \item 1x 10-k$\Omega$-Widerstand
    \item 1x 120-k$\Omega$-Widerstand
    \item 2x 1x20 Stift-/Buchsenleisten
    \item 1x 1x16 Stiftleiste
    \item 2x 1x4 Stiftleisten
    \item 1x 1x3 Stiftleiste
    \item 1x 2x16 Stiftleiste
    \item 1x 2x7 Stiftleiste
    \item 1x 2x3 Stiftleiste
    \item 26 Jumper
\end{itemize}

\section*{Grundprinzip beim Löten}

Für viele Schritte gilt dieselbe Vorgehensweise:
\begin{enumerate}
    \item Bauteil einsetzen
    \item zunächst nur einen Pin bzw. zwei gegenüberliegende Pins löten
    \item Ausrichtung kontrollieren
    \item gegebenenfalls korrigieren
    \item anschließend vollständig verlöten
\end{enumerate}

Dieses Vorgehen reduziert Fehler deutlich und erleichtert die Montage vor allem bei Steckleisten, Modulen und Bauteilen mit vielen Anschlüssen.

\section*{1. Raspberry Pi Pico vorbereiten}

Zunächst werden die beiden langen Stift-/Buchsenleisten mit dem Raspberry Pi Pico verlötet.

Wichtig ist dabei:
\begin{itemize}
    \item Die Leisten bestehen jeweils aus zwei zusammengesteckten Teilen.
    \item Diese sollten während des Lötens zusammengesteckt bleiben, damit die Pins sauber ausgerichtet sind.
    \item Die Seite mit dem schmaleren Kunststoffteil wird an den Raspberry Pi Pico gelötet.
\end{itemize}

\begin{figure}[H]
    \centering
    
\end{figure}

Vorgehen:
\begin{enumerate}
    \item Stiftleisten in Raspberry Pi Pico und Buzzerino-Platine einsetzen.
    \item Darauf achten, dass der Pico plan und parallel sitzt.
    \item Zunächst die vier Eckpins löten.
    \item Sitz und Ausrichtung kontrollieren.
    \item Den Pico wieder aus der Buzzerino-Platine entnehmen.
    \item Anschließend alle verbleibenden Pins vollständig verlöten.
\end{enumerate}

\begin{figure}[H]
    \centering
    
\end{figure}

\begin{figure}[H]
    \centering
    
\end{figure}

\begin{figure}[H]
    \centering
    
\end{figure}

\begin{figure}[H]
    \centering
    
\end{figure}

\begin{figure}[H]
    \centering
    
\end{figure}

\section*{2. USB-C-Breakout-Board vorbereiten}

Als Nächstes wird die 1x4-Stiftleiste an das USB-C-Breakout-Board gelötet.

\begin{figure}[H]
    \centering
    
\end{figure}

Vorgehen:
\begin{enumerate}
    \item Stiftleiste in das Breakout-Board einsetzen.
    \item Zunächst nur einen Pin löten.
    \item Ausrichtung prüfen; die Leiste sollte senkrecht zur Platine stehen.
    \item Falls nötig die erste Lötstelle erneut erwärmen und die Position korrigieren.
    \item Danach alle Pins vollständig löten.
\end{enumerate}

\begin{figure}[H]
    \centering
    
\end{figure}

\begin{figure}[H]
    \centering
    
\end{figure}

\begin{figure}[H]
    \centering
    
\end{figure}

\begin{figure}[H]
    \centering
    
\end{figure}

\section*{3. AHT10-Sensor vorbereiten}

Der AHT10-Sensor wird analog zum USB-C-Breakout-Board vorbereitet.

\begin{figure}[H]
    \centering
    
\end{figure}

Vorgehen:
\begin{enumerate}
    \item Stiftleiste einsetzen
    \item einen Pin löten
    \item Ausrichtung prüfen
    \item alle übrigen Pins löten
\end{enumerate}

\begin{figure}[H]
    \centering
    
\end{figure}

\section*{4. LCD-Display vorbereiten}

Das LCD-Display wird in derselben Weise vorbereitet.

\begin{figure}[H]
    \centering
    
\end{figure}

Vorgehen:
\begin{enumerate}
    \item Stiftleiste einsetzen
    \item einen Pin anlöten
    \item Ausrichtung kontrollieren
    \item anschließend vollständig verlöten
\end{enumerate}

\begin{figure}[H]
    \centering
    
\end{figure}

\begin{figure}[H]
    \centering
    
\end{figure}

\section*{5. Widerstände einbauen}

Die Widerstände werden direkt auf der Buzzerino-Platine montiert. Vor dem Einsetzen müssen die Anschlussdrähte passend gebogen werden.

Allgemeines Vorgehen:
\begin{enumerate}
    \item Anschlussdrähte U-förmig biegen
    \item Bauteil einsetzen
    \item Drähte auf der Rückseite leicht spreizen, damit das Bauteil nicht herausfällt
    \item zunächst einen Anschluss löten
    \item Sitz kontrollieren
    \item zweiten Anschluss löten
    \item Drahtenden bündig kürzen
\end{enumerate}

\subsection*{5.1 NTC-Widerstand}

Der 100-k$\Omega$-NTC ist an seinem kleinen Glasgehäuse ohne Farbringe zu erkennen. Er wird an der Position \textbf{TH\_NTC} eingesetzt.

Wichtig:
\begin{itemize}
    \item Die bedruckte Seite der Platine ist die Vorderseite.
    \item In der linken unteren Ecke sollte das DIGITEC-Logo sichtbar sein.
\end{itemize}

\begin{figure}[H]
    \centering
    
\end{figure}

\begin{figure}[H]
    \centering
    
\end{figure}

\begin{figure}[H]
    \centering
    
\end{figure}

\begin{figure}[H]
    \centering
    
\end{figure}

\begin{figure}[H]
    \centering
    
\end{figure}

\begin{figure}[H]
    \centering
    
\end{figure}

\begin{figure}[H]
    \centering
    
\end{figure}

\begin{figure}[H]
    \centering
    
\end{figure}

\begin{figure}[H]
    \centering
    
\end{figure}

\begin{figure}[H]
    \centering
    
\end{figure}

\subsection*{5.2 1-k$\Omega$-Widerstand}

Farbcodierung:
\begin{itemize}
    \item Braun
    \item Schwarz
    \item Rot
    \item Gold
\end{itemize}

\begin{figure}[H]
    \centering
    
\end{figure}

\begin{figure}[H]
    \centering
    
\end{figure}

\begin{figure}[H]
    \centering
    
\end{figure}

\subsection*{5.3 10-k$\Omega$-Widerstand}

Farbcodierung:
\begin{itemize}
    \item Braun
    \item Schwarz
    \item Orange
    \item Gold
\end{itemize}

\begin{figure}[H]
    \centering
    
\end{figure}

\begin{figure}[H]
    \centering
    
\end{figure}

\begin{figure}[H]
    \centering
    
\end{figure}

\subsection*{5.4 330-$\Omega$-Widerstände}

Farbcodierung:
\begin{itemize}
    \item Orange
    \item Orange
    \item Schwarz
    \item Schwarz
    \item Braun
\end{itemize}

Von diesen Widerständen werden fünf Stück eingebaut.

\begin{figure}[H]
    \centering
    
\end{figure}

\begin{figure}[H]
    \centering
    
\end{figure}

\begin{figure}[H]
    \centering
    
\end{figure}

\begin{figure}[H]
    \centering
    
\end{figure}

\subsection*{5.5 120-k$\Omega$-Widerstand}

Farbcodierung:
\begin{itemize}
    \item Braun
    \item Rot
    \item Gelb
    \item Gold
\end{itemize}

\begin{figure}[H]
    \centering
    
\end{figure}

\begin{figure}[H]
    \centering
    
\end{figure}

\begin{figure}[H]
    \centering
    
\end{figure}

\section*{6. Taster einbauen}

Als Nächstes werden die fünf Taster montiert.

\begin{itemize}
    \item ein Reset-Taster
    \item vier Taster für das D-Pad
\end{itemize}

Wichtig ist, dass die Taster vollständig eingesetzt sind und plan auf der Platine aufliegen, bevor sie verlötet werden.

\begin{figure}[H]
    \centering
    
\end{figure}

\begin{figure}[H]
    \centering
    
\end{figure}

\begin{figure}[H]
    \centering
    
\end{figure}

\begin{figure}[H]
    \centering
    
\end{figure}

\section*{7. Stiftleisten auf die Hauptplatine löten}

Nun werden mehrere Stiftleisten direkt auf die Buzzerino-Platine gelötet.

\textbf{Wichtiger Hinweis:}  
Die \textbf{kurze Seite} der Pins muss durch die Platine gesteckt werden. Das ist eine häufige Fehlerquelle.

Einzubauen sind:
\begin{itemize}
    \item 2x7-Stiftleiste
    \item 2x3-Stiftleiste
    \item 2x16-Stiftleiste
    \item 1x3-Stiftleiste
\end{itemize}

Empfohlenes Vorgehen:
\begin{enumerate}
    \item Leiste einsetzen
    \item zunächst einen Pin löten
    \item Sitz und Rechtwinkligkeit kontrollieren
    \item gegebenenfalls korrigieren
    \item restliche Pins verlöten
\end{enumerate}

\begin{figure}[H]
    \centering
    
\end{figure}

\begin{figure}[H]
    \centering
    
\end{figure}

\begin{figure}[H]
    \centering
    
\end{figure}

\begin{figure}[H]
    \centering
    
\end{figure}

\begin{figure}[H]
    \centering
    
\end{figure}

\begin{figure}[H]
    \centering
    
\end{figure}

\begin{figure}[H]
    \centering
    
\end{figure}

\begin{figure}[H]
    \centering
    
\end{figure}

\begin{figure}[H]
    \centering
    
\end{figure}

\section*{8. USB-C-Breakout-Board einbauen}

Das vorbereitete USB-C-Breakout-Board wird an der rechten Seite der Hauptplatine montiert. Der USB-Anschluss muss nach außen zeigen und vollständig sichtbar sein.

Vorgehen:
\begin{enumerate}
    \item Modul einsetzen
    \item einen Pin löten
    \item Ausrichtung kontrollieren; das Modul sollte parallel zur Hauptplatine stehen
    \item anschließend vollständig verlöten
\end{enumerate}

\textbf{Hinweis:} Die Pins dieses Moduls sind relativ hart. Zum Kürzen sollte ein größerer Drahtschneider verwendet werden.

\begin{figure}[H]
    \centering
    
\end{figure}

\begin{figure}[H]
    \centering
    
\end{figure}

\begin{figure}[H]
    \centering
    
\end{figure}

\begin{figure}[H]
    \centering
    
\end{figure}

\section*{9. AHT10-Sensor einbauen}

Der AHT10-Sensor wird auf der linken Seite der Hauptplatine montiert. Die Bauteile auf dem Sensormodul sollten sichtbar nach außen zeigen.

Vorgehen:
\begin{enumerate}
    \item Sensor einsetzen
    \item einen Pin löten
    \item Ausrichtung kontrollieren
    \item vollständig verlöten
\end{enumerate}

Auch hier gilt: zum Kürzen der Pins besser einen größeren Drahtschneider verwenden.

\begin{figure}[H]
    \centering
    
\end{figure}

\begin{figure}[H]
    \centering
    
\end{figure}

\section*{10. Buzzer einbauen}

Der Buzzer ist ein \textbf{polarisiertes} Bauteil und muss korrekt ausgerichtet werden.

Beachte:
\begin{itemize}
    \item Auf der Platine ist die positive Seite mit \textbf{+} markiert.
    \item Auf dem Buzzer ist die positive Seite ebenfalls markiert.
    \item Der längere Anschlussdraht ist der Pluspol.
\end{itemize}

Beim Einsetzen müssen diese Merkmale übereinstimmen.

\begin{figure}[H]
    \centering
    
\end{figure}

\begin{figure}[H]
    \centering
    
\end{figure}

\section*{11. LCD-Display einbauen}

Das vorbereitete LCD-Display wird analog zu den anderen Modulen montiert.

Vorgehen:
\begin{enumerate}
    \item Display einsetzen
    \item einen Pin löten
    \item Sitz und Ausrichtung kontrollieren
    \item vollständig verlöten
\end{enumerate}

Zum Kürzen der Pins sollte ebenfalls ein größerer Drahtschneider verwendet werden.

\begin{figure}[H]
    \centering
    
\end{figure}

\begin{figure}[H]
    \centering
    
\end{figure}

\begin{figure}[H]
    \centering
    
\end{figure}

\begin{figure}[H]
    \centering
    
\end{figure}

\section*{12. RGB-LED einbauen}

Auch die RGB-LED ist polarisiert und muss korrekt eingesetzt werden.

Wichtig:
\begin{itemize}
    \item Das längste Bein ist hier der Minuspol.
    \item Auf der Platine ist der Minuspol durch ein quadratisches Pad gekennzeichnet.
\end{itemize}

Nach dem Löten und Kürzen der Anschlüsse kann die Lötstelle optisch unregelmäßig aussehen. In diesem Fall kann sie vorsichtig nacherwärmt werden. Dabei ist unbedingt darauf zu achten, dass keine Lötbrücken zwischen benachbarten Pins entstehen.

\begin{figure}[H]
    \centering
    
\end{figure}

\begin{figure}[H]
    \centering
    
\end{figure}

\begin{figure}[H]
    \centering
    
\end{figure}

\begin{figure}[H]
    \centering
    
\end{figure}

\begin{figure}[H]
    \centering
    
\end{figure}

\begin{figure}[H]
    \centering
    
\end{figure}

\section*{13. Raspberry Pi Pico einbauen}

Jetzt wird der vorbereitete Raspberry Pi Pico auf die Hauptplatine gesetzt.

Empfohlenes Vorgehen:
\begin{enumerate}
    \item Pico einsetzen
    \item zunächst zwei gegenüberliegende Pins löten
    \item Ausrichtung kontrollieren
    \item danach alle übrigen Pins löten
\end{enumerate}

\begin{figure}[H]
    \centering
    
\end{figure}

\begin{figure}[H]
    \centering
    
\end{figure}

\begin{figure}[H]
    \centering
    
\end{figure}

\section*{14. Joystick einbauen}

Der Joystick ist das letzte Bauteil und wegen seiner vielen Anschlüsse mechanisch etwas anspruchsvoller.

Vorgehen:
\begin{enumerate}
    \item Bauteil vorsichtig ansetzen
    \item zunächst die Tasterpins und danach die übrigen Pins in Position bringen
    \item das Bauteil vollständig einsetzen
    \item anschließend alle Pins verlöten
\end{enumerate}

Hier ist etwas Geduld hilfreich. Nicht mit Gewalt arbeiten; stattdessen das Bauteil langsam ausrichten.

\begin{figure}[H]
    \centering
    
\end{figure}

\begin{figure}[H]
    \centering
    
\end{figure}

\begin{figure}[H]
    \centering
    
\end{figure}

\begin{figure}[H]
    \centering
    
\end{figure}

\begin{figure}[H]
    \centering
    
\end{figure}

\section*{15. Jumper einsetzen}

Vor dem Testen der Platine müssen alle \textbf{26 Jumper} eingesetzt werden.

\begin{figure}[H]
    \centering
    
\end{figure}

Erst danach ist das System vollständig aufgebaut.

\section*{Abschluss}

Wenn alle Bauteile korrekt montiert und alle Jumper gesetzt sind, ist der Hardware-Aufbau abgeschlossen.

\textbf{Empfehlung vor dem ersten Einschalten:}
\begin{itemize}
    \item Sichtprüfung aller Lötstellen
    \item Kontrolle auf vergessene oder vertauschte Bauteile
    \item Kontrolle auf Lötbrücken, insbesondere bei eng beieinanderliegenden Pins
    \item Kontrolle der Polung bei Buzzer und RGB-LED
\end{itemize}

\section*{Programm aufspielen}

Falls auf dem Raspberry Pi Pico noch keine passende Firmware vorhanden ist, kann z.\,B. die Datei \texttt{self\_test.uf2} aufgespielt werden.

Vorgehen:
\begin{enumerate}
    \item BOOTSEL-Taste auf dem Raspberry Pi Pico gedrückt halten
    \item Pico per USB mit dem Rechner verbinden
    \item warten, bis das Laufwerk \textbf{RPI-RP2} erscheint
    \item \texttt{.uf2}-Datei auf dieses Laufwerk kopieren
    \item der Pico startet danach automatisch neu
\end{enumerate}

\section*{Praktische Hinweise}

\begin{itemize}
    \item Kurze, saubere Lötzeiten sind besser als langes Erhitzen.
    \item Bei Unsicherheit zunächst nur einen Pin löten und die Lage prüfen.
    \item Drahtenden immer erst nach erfolgreicher Positionierung kürzen.
    \item Wenn etwas nicht passt, nicht mit Kraft arbeiten, sondern die Ausrichtung erneut prüfen.
\end{itemize}

\end{document}

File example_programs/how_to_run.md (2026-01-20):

After putting the rapberry pi pico in uf2 programming mode (Hold BOOTSEL on RPI and SW_RESET on Buzzerino boar) you can drag and drop the precompiled uf2 files onto it.

AI disclaimer:
In the creation of the example projects many AI-tolls where used with limited oversight, so no warranty of quality is given.

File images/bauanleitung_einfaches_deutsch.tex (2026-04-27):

\documentclass[a4paper,11pt]{article}

\usepackage[utf8]{inputenc}
\usepackage[T1]{fontenc}
\usepackage[ngerman]{babel}
\usepackage[a4paper,margin=2.5cm]{geometry}
\usepackage{graphicx}
\usepackage{float}
\usepackage{hyperref}
\usepackage{enumitem}
\usepackage{longtable}
\usepackage{array}
\usepackage{xcolor}
\usepackage{parskip}

\hypersetup{
    colorlinks=true,
    linkcolor=blue,
    urlcolor=blue
}

\title{Buzzerino -- einfache Bauanleitung}
\author{}
\date{}

\begin{document}

\maketitle

Hier lernst du Schritt für Schritt, wie du den \textbf{Buzzerino} zusammenbaust.

\section*{Bevor du anfängst}

Lege dir alles ordentlich auf den Tisch.\\
Du brauchst:

\begin{itemize}
    \item einen Lötkolben
    \item Lötzinn
    \item einen Seitenschneider
    \item am besten eine kleine Zange
    \item alle Teile aus dem Bausatz
\end{itemize}

\textbf{Wichtig:}
\begin{itemize}
    \item Arbeite langsam und in Ruhe.
    \item Der Lötkolben ist \textbf{sehr heiß}. Pass gut auf deine Finger auf.
    \item Frage eine Lehrkraft oder eine erwachsene Person, wenn du unsicher bist.
\end{itemize}

\section*{Das ist im Bausatz drin}

\begin{figure}[H]
    \centering
    
\end{figure}

Prüfe zuerst, ob alle Teile da sind:

\begin{itemize}
    \item 1x Buzzerino-Platine
    \item 1x Raspberry Pi Pico
    \item 1x 1602A-LCD-Display
    \item 1x AHT10 Temperatur- und Luftfeuchtigkeitssensor
    \item 1x USB-C-Breakout-Board
    \item 1x 10 mm RGB-LED
    \item 1x Buzzer
    \item 1x analoger Joystick
    \item 5x Taster
    \item 1x 100-k$\Omega$-NTC
    \item 5x 330-$\Omega$-Widerstände
    \item 1x 1-k$\Omega$-Widerstand
    \item 1x 10-k$\Omega$-Widerstand
    \item 1x 120-k$\Omega$-Widerstand
    \item verschiedene Stiftleisten
    \item 26 Jumper
\end{itemize}

\section*{So lötest du richtig}

Wenn du zwei Teile verlöten willst:

\begin{enumerate}
    \item Stecke das Teil in die richtige Position.
    \item Drehe die Platine vorsichtig um.
    \item Halte den Lötkolben an den Pin und an die Lötstelle.
    \item Gib dann ein wenig Lötzinn dazu.
    \item Nimm zuerst das Lötzinn weg, dann den Lötkolben.
    \item Lass alles kurz abkühlen.
\end{enumerate}

\textbf{Tipp:}
\begin{itemize}
    \item Erst \textbf{einen Pin} löten.
    \item Dann schauen, ob das Teil gerade sitzt.
    \item Danach die restlichen Pins löten.
\end{itemize}

\section*{Schritt-für-Schritt-Aufbau}

\subsection*{1. Raspberry Pi Pico vorbereiten}

Zuerst werden die beiden langen Stiftleisten an den Raspberry Pi Pico gelötet.

\textbf{Wichtig:}
\begin{itemize}
    \item Die Stiftleisten bestehen aus zwei zusammengesteckten Teilen.
    \item \textbf{Lass sie zusammengesteckt.}
    \item So bleiben die Pins gerade.
\end{itemize}

\begin{figure}[H]
    \centering
    
\end{figure}

So geht’s:
\begin{enumerate}
    \item Stecke die beiden Stiftleisten in den Raspberry Pi Pico.
    \item Stecke das Ganze zusätzlich in die Buzzerino-Platine, damit alles gerade ausgerichtet ist.
    \item Löte zuerst die \textbf{vier Eckpins}.
    \item Prüfe, ob alles gerade sitzt.
    \item Ziehe den Raspberry Pi Pico wieder heraus.
    \item Löte jetzt alle übrigen Pins fest.
\end{enumerate}

\begin{figure}[H]
    \centering
    
\end{figure}

\begin{figure}[H]
    \centering
    
\end{figure}

\begin{figure}[H]
    \centering
    
\end{figure}

\begin{figure}[H]
    \centering
    
\end{figure}

\begin{figure}[H]
    \centering
    
\end{figure}

\subsection*{2. USB-C-Breakout-Board vorbereiten}

Jetzt bekommt das USB-C-Breakout-Board eine kleine Stiftleiste.

\begin{figure}[H]
    \centering
    
\end{figure}

So geht’s:
\begin{enumerate}
    \item Stecke die 1x4-Stiftleiste in das Board.
    \item Löte zuerst nur \textbf{einen Pin}.
    \item Prüfe, ob die Stiftleiste gerade steht.
    \item Falls sie schief ist: Lötstelle nochmal kurz erhitzen und gerade richten.
    \item Löte dann alle Pins fest.
\end{enumerate}

\begin{figure}[H]
    \centering
    
\end{figure}

\begin{figure}[H]
    \centering
    
\end{figure}

\begin{figure}[H]
    \centering
    
\end{figure}

\begin{figure}[H]
    \centering
    
\end{figure}

\subsection*{3. AHT10-Sensor vorbereiten}

Der AHT10-Sensor wird fast genauso vorbereitet wie das USB-C-Breakout-Board.

\begin{figure}[H]
    \centering
    
\end{figure}

So geht’s:
\begin{enumerate}
    \item Stiftleiste einstecken.
    \item Einen Pin löten.
    \item Gerade ausrichten.
    \item Alle Pins fertig löten.
\end{enumerate}

\begin{figure}[H]
    \centering
    
\end{figure}

\subsection*{4. LCD-Display vorbereiten}

Auch das Display bekommt zuerst seine Stiftleiste.

\begin{figure}[H]
    \centering
    
\end{figure}

So geht’s:
\begin{enumerate}
    \item Stiftleiste einstecken.
    \item Einen Pin löten.
    \item Prüfen, ob alles gerade ist.
    \item Alle Pins festlöten.
\end{enumerate}

\begin{figure}[H]
    \centering
    
\end{figure}

\begin{figure}[H]
    \centering
    
\end{figure}

\subsection*{5. Widerstände einbauen}

Jetzt kommen die kleinen Widerstände auf die Platine.

\subsubsection*{Wichtig}
Die Drähte der Widerstände müssen vorher gebogen werden.

So geht’s:
\begin{enumerate}
    \item Biege die beiden Drahtenden vorsichtig nach unten, sodass eine U-Form entsteht.
    \item Stecke den Widerstand an die passende Stelle auf der Platine.
    \item Biege die Drähte auf der Rückseite leicht auseinander, damit er nicht herausfällt.
    \item Löte erst ein Bein fest.
    \item Prüfe, ob der Widerstand schön anliegt.
    \item Löte das zweite Bein.
    \item Schneide die überstehenden Drähte ab.
\end{enumerate}

\subsubsection*{5a. NTC-Widerstand einbauen}

Der NTC ist ein besonderer Temperaturwiderstand.

Merkmal:
\begin{itemize}
    \item Er hat ein \textbf{Glasgehäuse}
    \item Er hat \textbf{keine Farbringe}
\end{itemize}

Stecke ihn an die Stelle \textbf{TH\_NTC}.

\textbf{Wichtig:}
\begin{itemize}
    \item Die \textbf{bedruckte Seite} der Platine ist die Vorderseite.
    \item Unten links sollte das \textbf{DIGITEC-Logo} zu sehen sein.
\end{itemize}

\begin{figure}[H]
    \centering
    
\end{figure}

\begin{figure}[H]
    \centering
    
\end{figure}

\begin{figure}[H]
    \centering
    
\end{figure}

\begin{figure}[H]
    \centering
    
\end{figure}

\begin{figure}[H]
    \centering
    
\end{figure}

\begin{figure}[H]
    \centering
    
\end{figure}

\begin{figure}[H]
    \centering
    
\end{figure}

\begin{figure}[H]
    \centering
    
\end{figure}

\begin{figure}[H]
    \centering
    
\end{figure}

\begin{figure}[H]
    \centering
    
\end{figure}

\subsubsection*{5b. 1-k$\Omega$-Widerstand einbauen}

Farbringe:
\begin{itemize}
    \item Braun
    \item Schwarz
    \item Rot
    \item Gold
\end{itemize}

Diesen Widerstand an die passende markierte Stelle setzen und einlöten.

\begin{figure}[H]
    \centering
    
\end{figure}

\begin{figure}[H]
    \centering
    
\end{figure}

\begin{figure}[H]
    \centering
    
\end{figure}

\subsubsection*{5c. 10-k$\Omega$-Widerstand einbauen}

Farbringe:
\begin{itemize}
    \item Braun
    \item Schwarz
    \item Orange
    \item Gold
\end{itemize}

Auch hier:
\begin{itemize}
    \item biegen
    \item einsetzen
    \item löten
    \item Drähte abschneiden
\end{itemize}

\begin{figure}[H]
    \centering
    
\end{figure}

\begin{figure}[H]
    \centering
    
\end{figure}

\begin{figure}[H]
    \centering
    
\end{figure}

\subsubsection*{5d. 330-$\Omega$-Widerstände einbauen}

Farbringe:
\begin{itemize}
    \item Orange
    \item Orange
    \item Schwarz
    \item Schwarz
    \item Braun
\end{itemize}

Davon gibt es \textbf{fünf Stück}.\\
Baue alle nacheinander ein.

\begin{figure}[H]
    \centering
    
\end{figure}

\begin{figure}[H]
    \centering
    
\end{figure}

\begin{figure}[H]
    \centering
    
\end{figure}

\begin{figure}[H]
    \centering
    
\end{figure}

\subsubsection*{5e. 120-k$\Omega$-Widerstand einbauen}

Farbringe:
\begin{itemize}
    \item Braun
    \item Rot
    \item Gelb
    \item Gold
\end{itemize}

Auch diesen wie die anderen Widerstände einbauen.

\begin{figure}[H]
    \centering
    
\end{figure}

\begin{figure}[H]
    \centering
    
\end{figure}

\begin{figure}[H]
    \centering
    
\end{figure}

\subsection*{6. Taster einbauen}

Jetzt kommen die fünf Taster auf die Platine.

So gehst du vor:
\begin{enumerate}
    \item Stecke einen Taster in die richtige Position.
    \item Drücke ihn ganz hinein, damit er flach auf der Platine sitzt.
    \item Löte die Pins fest.
    \item Wiederhole das mit den anderen Tastern.
\end{enumerate}

Es gibt:
\begin{itemize}
    \item einen Reset-Taster
    \item vier D-Pad-Taster
\end{itemize}

\textbf{Wichtig:}
Die Taster sollen \textbf{möglichst flach} auf der Platine sitzen.

\begin{figure}[H]
    \centering
    
\end{figure}

\begin{figure}[H]
    \centering
    
\end{figure}

\begin{figure}[H]
    \centering
    
\end{figure}

\begin{figure}[H]
    \centering
    
\end{figure}

\subsection*{7. Stiftleisten auf die Hauptplatine löten}

Jetzt kommen mehrere Stiftleisten direkt auf die Buzzerino-Platine.

\textbf{Wichtig:}
\textbf{Die kurze Seite der Pins muss durch die Platine gesteckt werden.}

Das ist sehr wichtig und wird oft falsch gemacht.

Löte nacheinander:
\begin{itemize}
    \item die 2x7-Stiftleiste
    \item die 2x3-Stiftleiste
    \item die 2x16-Stiftleiste
    \item die 1x3-Stiftleiste
\end{itemize}

So gehst du immer vor:
\begin{enumerate}
    \item Stiftleiste einsetzen
    \item einen Pin löten
    \item prüfen, ob sie gerade sitzt
    \item falls nötig korrigieren
    \item alle restlichen Pins löten
\end{enumerate}

\begin{figure}[H]
    \centering
    
\end{figure}

\begin{figure}[H]
    \centering
    
\end{figure}

\begin{figure}[H]
    \centering
    
\end{figure}

\begin{figure}[H]
    \centering
    
\end{figure}

\begin{figure}[H]
    \centering
    
\end{figure}

\begin{figure}[H]
    \centering
    
\end{figure}

\begin{figure}[H]
    \centering
    
\end{figure}

\begin{figure}[H]
    \centering
    
\end{figure}

\begin{figure}[H]
    \centering
    
\end{figure}

\subsection*{8. USB-C-Breakout-Board einbauen}

Jetzt kommt das vorbereitete USB-C-Breakout-Board auf die große Platine.

So geht’s:
\begin{enumerate}
    \item Stecke es an die richtige Stelle auf der rechten Seite der Platine.
    \item Der USB-Anschluss soll nach außen zeigen und gut sichtbar sein.
    \item Löte zuerst einen Pin.
    \item Prüfe, ob das Board gerade und parallel zur Platine steht.
    \item Löte dann alle Pins.
\end{enumerate}

\textbf{Achtung:}\\
Die Pins sind härter als normale Drahtenden.\\
Benutze dafür einen \textbf{größeren Seitenschneider}.

\begin{figure}[H]
    \centering
    
\end{figure}

\begin{figure}[H]
    \centering
    
\end{figure}

\begin{figure}[H]
    \centering
    
\end{figure}

\begin{figure}[H]
    \centering
    
\end{figure}

\subsection*{9. AHT10-Sensor einbauen}

Jetzt kommt der vorbereitete AHT10-Sensor auf die Platine.

So geht’s:
\begin{enumerate}
    \item Setze ihn auf der linken Seite ein.
    \item Die kleinen Bauteile auf dem Sensor sollen sichtbar sein.
    \item Löte zuerst einen Pin.
    \item Richte ihn gerade aus.
    \item Löte alle Pins fest.
\end{enumerate}

Auch hier:
\begin{itemize}
    \item zum Kürzen besser einen größeren Schneider benutzen
\end{itemize}

\begin{figure}[H]
    \centering
    
\end{figure}

\begin{figure}[H]
    \centering
    
\end{figure}

\subsection*{10. Buzzer einbauen}

Jetzt kommt der Buzzer auf die Platine.

\textbf{Wichtig:}
Der Buzzer ist \textbf{gepolt}. Das bedeutet: Er muss richtig herum eingebaut werden.

Achte auf das \textbf{Pluszeichen}:
\begin{itemize}
    \item Auf der Platine ist ein \textbf{+}
    \item Auf dem Buzzer ist auch ein \textbf{+}
\end{itemize}

Diese beiden müssen zusammenpassen.

Merke:
\begin{itemize}
    \item Der \textbf{längere Draht} ist der \textbf{Pluspol}
\end{itemize}

Dann:
\begin{enumerate}
    \item richtig herum einsetzen
    \item festlöten
\end{enumerate}

\begin{figure}[H]
    \centering
    
\end{figure}

\begin{figure}[H]
    \centering
    
\end{figure}

\subsection*{11. LCD-Display einbauen}

Jetzt wird das vorbereitete LCD-Display eingesetzt.

So geht’s:
\begin{enumerate}
    \item In die richtige Position stecken
    \item einen Pin löten
    \item prüfen, ob es gerade sitzt
    \item alle Pins fertig löten
\end{enumerate}

Auch hier gilt:
\begin{itemize}
    \item Für das Kürzen der Pins lieber den größeren Schneider benutzen.
\end{itemize}

\begin{figure}[H]
    \centering
    
\end{figure}

\begin{figure}[H]
    \centering
    
\end{figure}

\begin{figure}[H]
    \centering
    
\end{figure}

\begin{figure}[H]
    \centering
    
\end{figure}

\subsection*{12. RGB-LED einbauen}

Jetzt kommt die bunte LED.

Auch sie muss richtig herum eingebaut werden.

\textbf{Wichtig:}
\begin{itemize}
    \item Die LED ist \textbf{gepolt}
    \item Hier ist das \textbf{längste Bein der Minuspol}
    \item Auf der Platine zeigt ein \textbf{quadratisches Lötpad} den Minuspol
\end{itemize}

So geht’s:
\begin{enumerate}
    \item LED richtig herum einsetzen
    \item festlöten
    \item Drähte abschneiden
\end{enumerate}

Falls die Lötstelle nicht schön aussieht:
\begin{itemize}
    \item mit dem Lötkolben vorsichtig nochmal erwärmen
\end{itemize}

Aber ganz wichtig:
\begin{itemize}
    \item Prüfe danach, ob keine zwei Pins aus Versehen mit Lötzinn verbunden sind.
\end{itemize}

\begin{figure}[H]
    \centering
    
\end{figure}

\begin{figure}[H]
    \centering
    
\end{figure}

\begin{figure}[H]
    \centering
    
\end{figure}

\begin{figure}[H]
    \centering
    
\end{figure}

\begin{figure}[H]
    \centering
    
\end{figure}

\begin{figure}[H]
    \centering
    
\end{figure}

\subsection*{13. Raspberry Pi Pico einbauen}

Jetzt wird der vorbereitete Raspberry Pi Pico auf die Platine gesetzt.

So geht’s:
\begin{enumerate}
    \item Pico in die richtige Position stecken
    \item zuerst \textbf{zwei gegenüberliegende Pins} löten
    \item prüfen, ob alles gerade sitzt
    \item dann alle restlichen Pins löten
\end{enumerate}

\begin{figure}[H]
    \centering
    
\end{figure}

\begin{figure}[H]
    \centering
    
\end{figure}

\begin{figure}[H]
    \centering
    
\end{figure}

\subsection*{14. Joystick einbauen}

Der Joystick kommt ganz zum Schluss.

Er hat viele Pins. Deshalb ist dieser Schritt etwas knifflig.

So geht’s:
\begin{enumerate}
    \item Setze zuerst die passenden Pins vorsichtig in die Löcher ein.
    \item Bewege den Joystick langsam ein wenig hin und her, bis alle Pins richtig sitzen.
    \item Drücke ihn ganz hinein.
    \item Löte dann alle Pins fest.
\end{enumerate}

\begin{figure}[H]
    \centering
    
\end{figure}

\begin{figure}[H]
    \centering
    
\end{figure}

\begin{figure}[H]
    \centering
    
\end{figure}

\begin{figure}[H]
    \centering
    
\end{figure}

\begin{figure}[H]
    \centering
    
\end{figure}

\subsection*{15. Jumper einsetzen}

Bevor du die Platine testen kannst, musst du noch alle \textbf{26 Jumper} einsetzen.

Stecke sie so auf wie in der Vorlage bzw. auf dem Bild in der Originalanleitung.

Erst danach ist die Platine vollständig bereit.

\begin{figure}[H]
    \centering
    
\end{figure}

\section*{Geschafft!}

\textbf{Herzlichen Glückwunsch!}\\
Du hast den Buzzerino zusammengebaut.

\section*{Programm aufspielen}

Wenn auf dem Raspberry Pi Pico noch kein Programm ist, kannst du eine Datei wie \texttt{self\_test.uf2} darauf kopieren.

So geht’s:
\begin{enumerate}
    \item Halte die \textbf{BOOTSEL-Taste} auf dem Raspberry Pi Pico gedrückt.
    \item Verbinde den Pico mit einem USB-Kabel mit dem Computer.
    \item Am Computer erscheint ein Laufwerk mit dem Namen \textbf{RPI-RP2}.
    \item Ziehe die \texttt{.uf2}-Datei auf dieses Laufwerk.
    \item Danach startet der Pico automatisch neu.
\end{enumerate}

\section*{Noch ein paar einfache Tipps}

\begin{itemize}
    \item Löte lieber \textbf{langsam und sauber} als schnell.
    \item Wenn etwas schief sitzt: erst korrigieren, dann weiterlöten.
    \item Schneide Drahtenden immer erst ab, wenn alles richtig sitzt.
    \item Wenn du unsicher bist, frage nach Hilfe.
\end{itemize}

\end{document}

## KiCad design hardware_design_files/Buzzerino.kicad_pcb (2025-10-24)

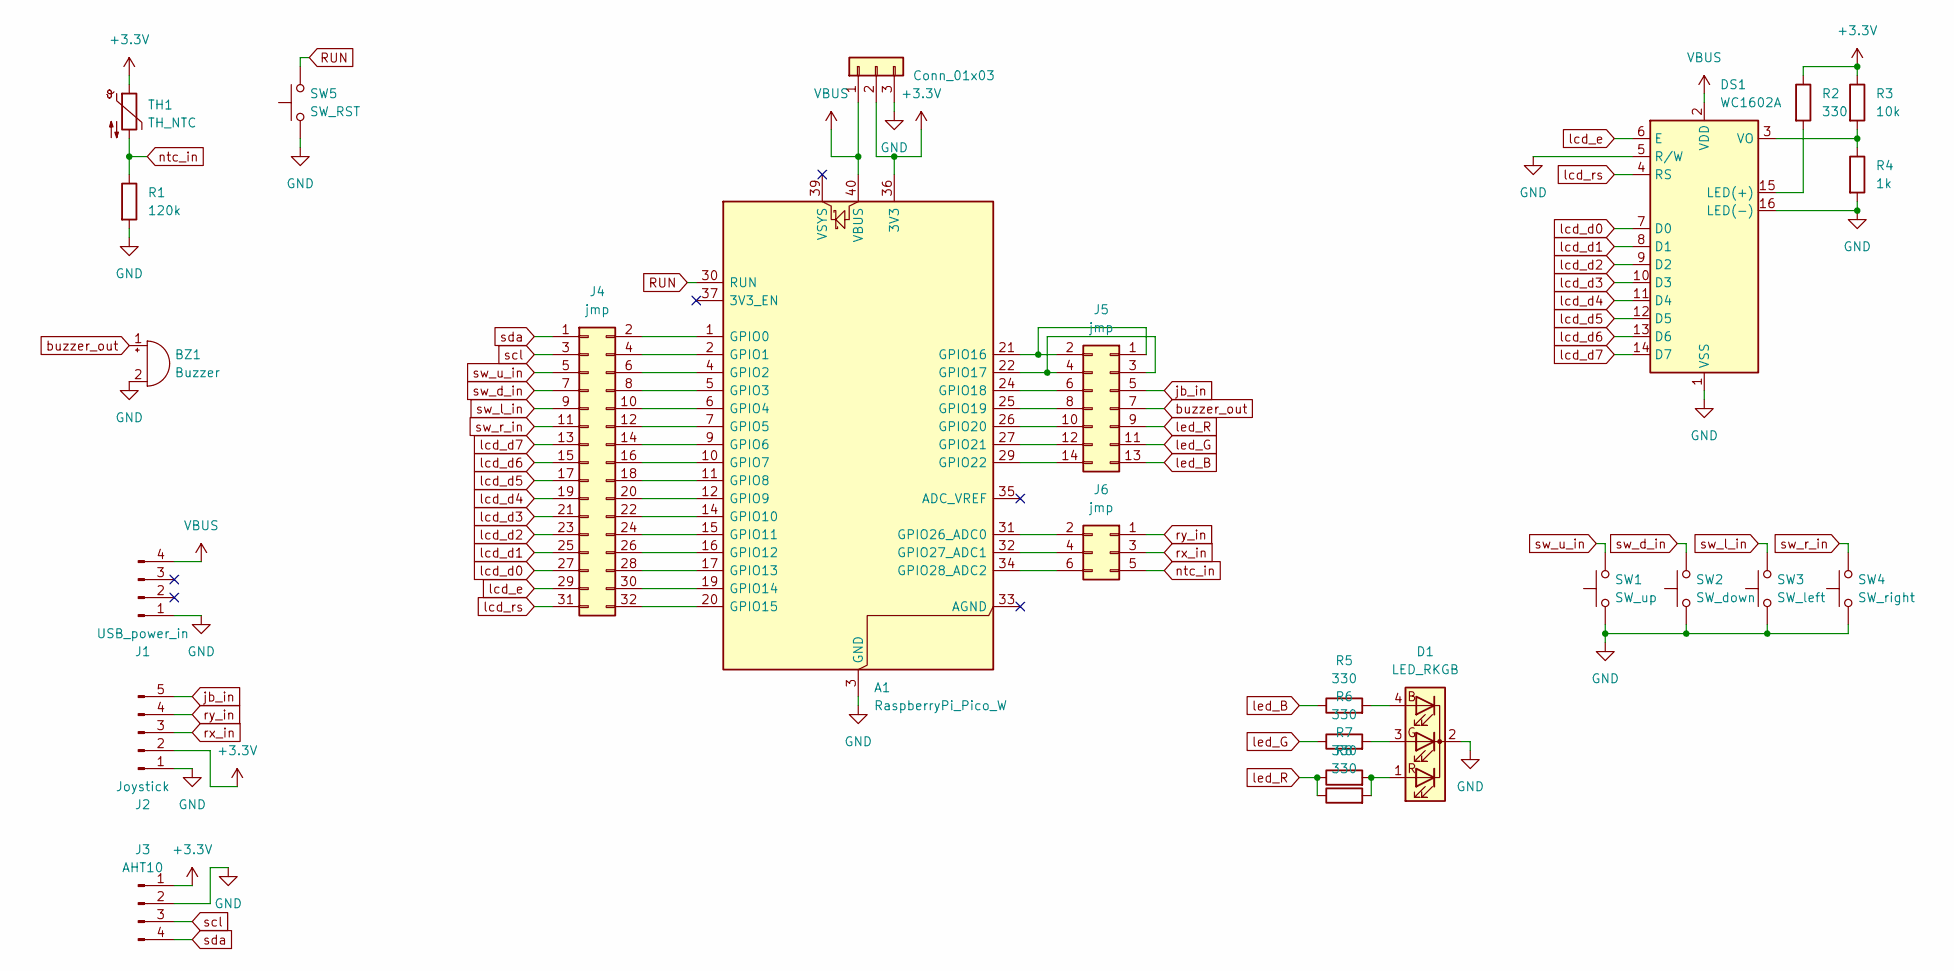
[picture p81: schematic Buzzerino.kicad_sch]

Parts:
A1: RaspberryPi_Pico_W; RaspberryPi_Pico_Common_THT
BZ1: Buzzer; Buzzer_12x9.5RM7.6
D1: LED_RKGB; led_D10mm_4pin
DS1: WC1602A
J1: USB_power_in; PinHeader_1x04_P2.54mm_Vertical
J2: Joystick; PS4_joystick
J3: AHT10; PinHeader_1x04_P2.54mm_Vertical
J4: jmp; PinHeader_2x16_P2.54mm_Vertical
J5: jmp; PinHeader_2x07_P2.54mm_Vertical
J6: jmp; PinHeader_2x03_P2.54mm_Vertical
J8: Conn_01x03; PinHeader_1x03_P2.54mm_Vertical
R1: 120k; R_Axial_DIN0207_L6.3mm_D2.5mm_P10.16mm_Horizontal
R2, R5, R6, R7, R8: 330; R_Axial_DIN0207_L6.3mm_D2.5mm_P10.16mm_Horizontal
R3: 10k; R_Axial_DIN0207_L6.3mm_D2.5mm_P10.16mm_Horizontal
R4: 1k; R_Axial_DIN0207_L6.3mm_D2.5mm_P10.16mm_Horizontal
SW1: SW_up; SW_PUSH_6mm
SW2: SW_down; SW_PUSH_6mm
SW3: SW_left; SW_PUSH_6mm
SW4: SW_right; SW_PUSH_6mm
SW5: SW_RST; SW_PUSH_6mm
TH1: TH_NTC; R_Axial_DIN0207_L6.3mm_D2.5mm_P10.16mm_Horizontal

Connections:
+3.3V: A1.36 (3V3), J2.2, J3.1, J8.2, R2.1, R3.1, TH1.1
GND: A1.3 (GND), A1.8 (GND), A1.13 (GND), A1.18 (GND), A1.23 (GND), A1.28 (GND), A1.38 (GND), BZ1.2 (-), D1.2 (K), DS1.1 (VSS), DS1.5 (R/W), DS1.16 (LED(-)), J1.1, J2.1, J3.2, J8.3, R1.2, R4.2, SW1.1, SW2.1, SW3.1, SW4.1, SW5.1
unnamed: A1.1 (GPIO0), J4.2
unnamed: A1.2 (GPIO1), J4.4
unnamed: A1.4 (GPIO2), J4.6
unnamed: A1.5 (GPIO3), J4.8
unnamed: A1.6 (GPIO4), J4.10
unnamed: A1.7 (GPIO5), J4.12
unnamed: A1.9 (GPIO6), J4.14
unnamed: A1.10 (GPIO7), J4.16
unnamed: A1.11 (GPIO8), J4.18
unnamed: A1.12 (GPIO9), J4.20
unnamed: A1.14 (GPIO10), J4.22
unnamed: A1.15 (GPIO11), J4.24
unnamed: A1.16 (GPIO12), J4.26
unnamed: A1.17 (GPIO13), J4.28
unnamed: A1.19 (GPIO14), J4.30
unnamed: A1.20 (GPIO15), J4.32
unnamed: A1.21 (GPIO16), J5.1, J5.2
unnamed: A1.22 (GPIO17), J5.3, J5.4
unnamed: A1.24 (GPIO18), J5.6
unnamed: A1.25 (GPIO19), J5.8
unnamed: A1.26 (GPIO20), J5.10
unnamed: A1.27 (GPIO21), J5.12
unnamed: A1.29 (GPIO22), J5.14
unnamed: A1.31 (GPIO26_ADC0), J6.2
unnamed: A1.32 (GPIO27_ADC1), J6.4
unnamed: A1.34 (GPIO28_ADC2), J6.6
unnamed: D1.4 (BA), R5.2
unnamed: D1.3 (GA), R6.2
unnamed: D1.1 (RA), R7.2, R8.2
unnamed: DS1.15 (LED(+)), R2.2
unnamed: DS1.3 (VO), R3.2, R4.1
RUN: A1.30 (RUN), SW5.2
VBUS: A1.40 (VBUS), DS1.2 (VDD), J1.4, J8.1
buzzer_out: BZ1.1 (+), J5.7
jb_in: J2.5, J5.5
lcd_d0: DS1.7 (D0), J4.27
lcd_d1: DS1.8 (D1), J4.25
lcd_d2: DS1.9 (D2), J4.23
lcd_d3: DS1.10 (D3), J4.21
lcd_d4: DS1.11 (D4), J4.19
lcd_d5: DS1.12 (D5), J4.17
lcd_d6: DS1.13 (D6), J4.15
lcd_d7: DS1.14 (D7), J4.13
lcd_e: DS1.6 (E), J4.29
lcd_rs: DS1.4 (RS), J4.31
led_B: J5.13, R5.1
led_G: J5.11, R6.1
led_R: J5.9, R7.1, R8.1
ntc_in: J6.5, R1.1, TH1.2
rx_in: J2.3, J6.3
ry_in: J2.4, J6.1
scl: J3.3, J4.3
sda: J3.4, J4.1
sw_d_in: J4.7, SW2.2
sw_l_in: J4.9, SW3.2
sw_r_in: J4.11, SW4.2
sw_u_in: J4.5, SW1.2

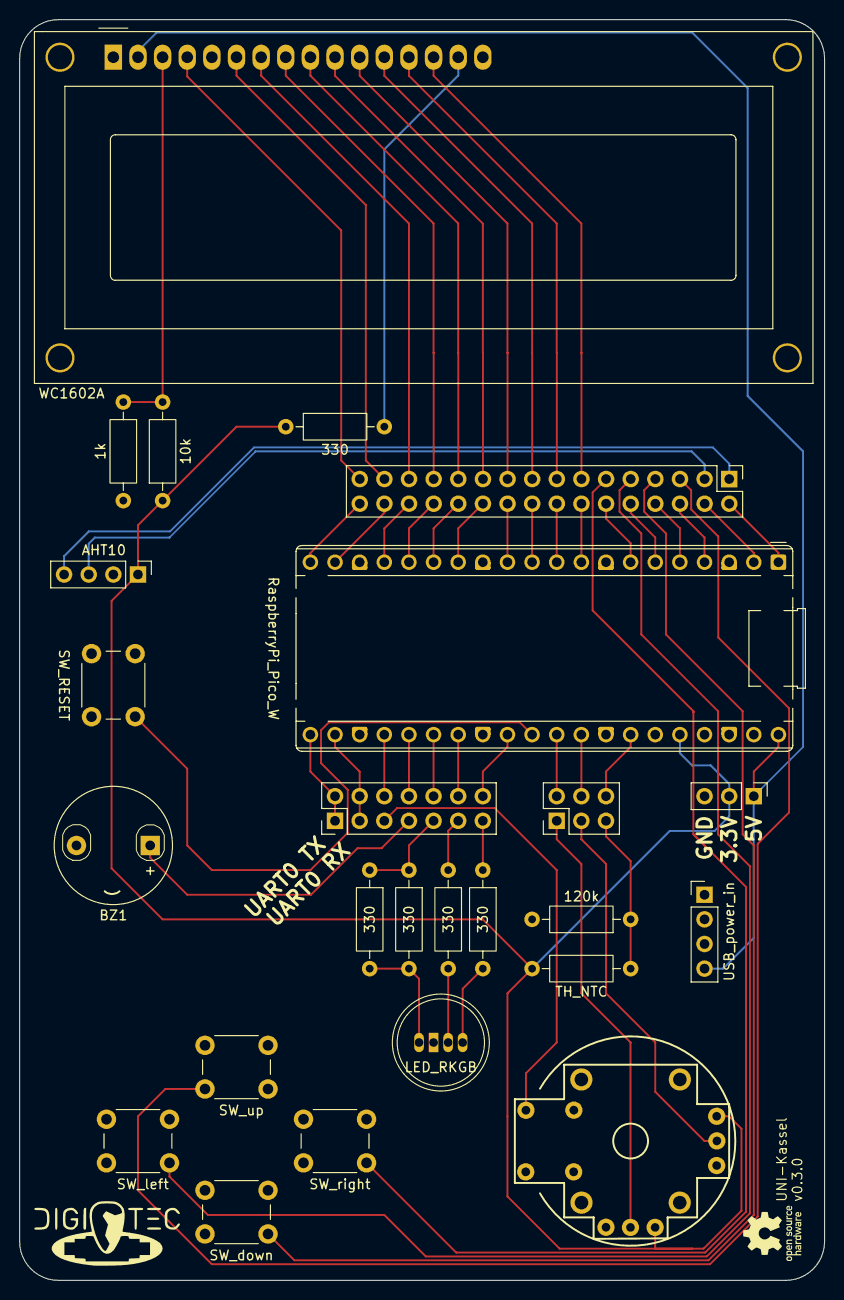
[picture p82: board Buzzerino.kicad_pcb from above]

Board: 2 copper layers, 83.0 x 130.0 mm, 25 parts (0 on the bottom side), 59 nets.

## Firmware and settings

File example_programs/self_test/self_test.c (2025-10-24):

#include <stdio.h>
#include <stdlib.h>
#include <math.h>
#include "pico/stdlib.h"
#include "pico/cyw43_arch.h"
#include "cyw43.h" 
#include "hardware/gpio.h"
#include "hardware/adc.h"
#include "lcd1602.h"
#include "aht10.h"
#include "weather_station.h"
#include "rgb_led.h"

#define SW_UP 2
#define SW_DOWN 3
#define SW_LEFT 4
#define SW_RIGHT 5

#define JS_BUTTON 18
#define JS_X_PIN 26
#define JS_Y_PIN 27
#define JS_X_ADC 0
#define JS_Y_ADC 1

#define BUZZER 19

#define NTC_PIN 28
#define NTC_ADC 2

#define RGB_R_PIN 20
#define RGB_G_PIN 21
#define RGB_B_PIN 22

#ifndef PICO_DEFAULT_LED_PIN
    #define PICO_DEFAULT_LED_PIN 25
#endif

static repeating_timer_t led_timer;
static bool led_on = false;

static bool led_timer_cb_on_pico(repeating_timer_t *rt)
{
    led_on = !led_on;
    gpio_put(PICO_DEFAULT_LED_PIN,led_on);
    return true; // repeat indefinitely
}

static bool led_timer_cb_on_cyw43(repeating_timer_t *rt)
{
    led_on = !led_on;
    cyw43_arch_gpio_put(CYW43_WL_GPIO_LED_PIN, led_on);
    return true; // repeat indefinitely
}

// Calculate temperature from ADC raw value (°C) using Beta model
double ntc_temp_c_from_adc(uint16_t adc_raw)
{
    const double R_fixed = 120000.0; // Ohm (Pulldown)
    const double R0 = 100000.0;      // Ohm (NTC at 25°C)
    const double Beta = 3950.0;      // K (NTC-Beta)
    const double T0 = 298.15;        // K (25°C)

    // Clamp extremes to avoid division by zero / ln(0)
    if (adc_raw <= 0)
        adc_raw = 1;
    if (adc_raw >= 4095)
        adc_raw = (uint16_t)4095 - 1;

    // Voltage divider: V = Vcc * R_fixed / (R_ntc + R_fixed)
    // -> R_ntc = R_fixed * (4095 / adc_raw - 1)
    double R_ntc = R_fixed * (4095 / (double)adc_raw - 1.0);

    // Beta-equation
    double inv_T = 1.0 / T0 + (1.0 / Beta) * log(R_ntc / R0);
    double T_c = 1.0 / inv_T - 273.15;

    return T_c;
}

int main()
{
    stdio_init_all(); // initialize core functionality

    bool has_cyw43 = false;

    // Initialise the Wi-Fi chip
    int rc = cyw43_arch_init();    // versucht den CYW43-Chip zu starten
    if (rc == 0) {
      // Fehlerprüfendes Setzen der LED:
      rc = cyw43_gpio_set(&cyw43_state, CYW43_WL_GPIO_LED_PIN, true);
      if (rc == 0) {
        // CYW43 ist vorhanden; benutze cyw43_gpio_set für die LED
        has_cyw43 = true;
      } else {
        // Fehler: Chip nicht vorhanden/nicht gestartet -> Fallback
        cyw43_arch_deinit();
        has_cyw43 = false;
      }
    } else {
        has_cyw43 = false;
      // Init fehlgeschlagen -> Fallback
    }

    // Set buildin LED blinking at 1Hz via timer
    if (has_cyw43) {
        cyw43_arch_gpio_put(CYW43_WL_GPIO_LED_PIN, 0);
        add_repeating_timer_ms(500, led_timer_cb_on_cyw43, NULL, &led_timer);
    } else {
        gpio_init(PICO_DEFAULT_LED_PIN);
        gpio_set_dir(PICO_DEFAULT_LED_PIN, GPIO_OUT);
        gpio_put(PICO_DEFAULT_LED_PIN,false);
        add_repeating_timer_ms(500, led_timer_cb_on_pico, NULL, &led_timer);
    }

    //----------- TEST LCD -----------------

    // init lcd and start display
    lcd_init();
    lcd_gotoxy(0, 0);
    lcd_puts("Welcome to the  "); // pad to 16 chars so display will be cleanly overriden
    lcd_gotoxy(1, 0);
    lcd_puts("self test :)    ");
    sleep_ms(1000);

    //----------- TEST DPAD ----------------

    // init GPIO for dpad
    gpio_init(SW_UP);
    gpio_init(SW_DOWN);
    gpio_init(SW_LEFT);
    gpio_init(SW_RIGHT);
    // init GPIO for dpad as inputs
    gpio_set_dir(SW_UP, GPIO_IN);
    gpio_set_dir(SW_DOWN, GPIO_IN);
    gpio_set_dir(SW_LEFT, GPIO_IN);
    gpio_set_dir(SW_RIGHT, GPIO_IN);
    // add pullups for dpad GPIO
    gpio_pull_up(SW_UP);
    gpio_pull_up(SW_DOWN);
    gpio_pull_up(SW_LEFT);
    gpio_pull_up(SW_RIGHT);

    lcd_gotoxy(0, 0);
    lcd_puts("press UP        ");
    lcd_gotoxy(1, 0);
    lcd_puts("to continue     ");
    // wait for UP button to be pressed
    while (gpio_get(SW_UP))
    {
    }

    lcd_gotoxy(0, 0);
    lcd_puts("press DOWN      ");
    lcd_gotoxy(1, 0);
    lcd_puts("to continue     ");
    // wait for DOWN button to be pressed
    while (gpio_get(SW_DOWN))
    {
    }

    lcd_gotoxy(0, 0);
    lcd_puts("press LEFT      ");
    lcd_gotoxy(1, 0);
    lcd_puts("to continue     ");
    // wait for LEFT button to be pressed
    while (gpio_get(SW_LEFT))
    {
    }

    lcd_gotoxy(0, 0);
    lcd_puts("press RIGHT     ");
    lcd_gotoxy(1, 0);
    lcd_puts("to continue     ");
    // wait for RIGHT button to be pressed
    while (gpio_get(SW_RIGHT))
    {
    }

    lcd_gotoxy(0, 0);
    lcd_puts("DPAD is working!");
    lcd_gotoxy(1, 0);
    lcd_puts("                ");
    sleep_ms(1000);

    //-------------- TEST JOYSTICK ------------

    // init adc (analogue to digital converter)
    adc_init();

    // set gpio for joystick inputs
    adc_gpio_init(JS_X_PIN);
    adc_gpio_init(JS_Y_PIN);
    gpio_init(JS_BUTTON);
    gpio_set_dir(JS_BUTTON, GPIO_IN);
    gpio_pull_up(JS_BUTTON);

    lcd_gotoxy(0, 0);
    lcd_puts("press JOYSTICK  ");
    lcd_gotoxy(1, 0);
    lcd_puts("to continue     ");
    // wait for joystick button to be pressed
    while (gpio_get(JS_BUTTON))
    {
    }

    // test joystick Y axis:
    // select joystick Y axis
    adc_select_input(JS_Y_ADC);

    lcd_gotoxy(0, 0);
    lcd_puts("move JOYSTICK   ");
    lcd_gotoxy(1, 0);
    lcd_puts("up to continue  ");
    while (adc_read() < 3800)
    {
        // uncomment for reading values
        // printf("%d\n",adc_read());
    }

    lcd_gotoxy(0, 0);
    lcd_puts("move JOYSTICK   ");
    lcd_gotoxy(1, 0);
    lcd_puts("down to continue");
    while (adc_read() > 250)
    {
        // uncomment for reading values
        // printf("%d\n",adc_read());
    }

    // test joystick X axis:
    // select joystick X axis
    adc_select_input(JS_X_ADC);

    lcd_gotoxy(0, 0);
    lcd_puts("move JOYSTICK   ");
    lcd_gotoxy(1, 0);
    lcd_puts("left to continue");
    while (adc_read() > 250)
    {
        // uncomment for reading values
        // printf("%d\n",adc_read());
    }

    lcd_gotoxy(0, 0);
    lcd_puts("move JOYSTICK   ");
    lcd_gotoxy(1, 0);
    lcd_puts("right to continue");
    while (adc_read() < 3800)
    {
        // uncomment for reading values
        // printf("%d\n",adc_read());
    }

    lcd_gotoxy(0, 0);
    lcd_puts("JOYSTICK        ");
    lcd_gotoxy(1, 0);
    lcd_puts("is working!     ");
    sleep_ms(1000);

    //------------ TEST BUZZER --------------

    // configure buzzer output
    gpio_init(BUZZER);
    gpio_set_dir(BUZZER, GPIO_OUT);

    bool buzzer_on = true;

    // turn buzzer on
    gpio_put(BUZZER, buzzer_on);

    lcd_gotoxy(0, 0);
    lcd_puts("Does the BUZZER ");
    lcd_gotoxy(1, 0);
    lcd_puts("beep? Press UP  ");

    while (gpio_get(SW_UP))
    {
        // toggle 10 times per second for nicer tone :)
        gpio_put(BUZZER, buzzer_on);
        buzzer_on = !buzzer_on;
        sleep_ms(100);
    }
    // turn buzzer of
    gpio_put(BUZZER, false);

    //------------ TEST NTC ----------------

    // init NTC (negative Temperature Coefficient) for ADC use
    adc_gpio_init(NTC_PIN);

    // select the NTC to be sampled by the ADC
    adc_select_input(NTC_ADC);

    lcd_gotoxy(0, 0);
    lcd_puts("Test NTC temp-  ");
    lcd_gotoxy(1, 0);
    lcd_puts("erature Sensor  ");
    sleep_ms(1000);

    // wait for user input
    while (gpio_get(SW_UP))
    {
        lcd_gotoxy(0, 0);
        lcd_puts("Press up if temp");
        lcd_gotoxy(1, 0);

        // sample NTC 16 times
        const int samples = 16;
        uint32_t sum = 0;
        for (int i = 0; i < samples; ++i)
        {
            sum += adc_read(); // 12-bit, 0..4095
        }
        uint16_t raw = (uint16_t)(sum / samples);
        double t_c = ntc_temp_c_from_adc(raw);

        printf("ADC=%u, T=%.2f C\n", raw, t_c);

        // format the output for a nice layout
        int len = snprintf(NULL, 0, "ok: %.2f%CC    ", t_c, 0xDF);
        char *result = malloc(len + 1);
        snprintf(result, len + 1, "ok: %.2f%cC    ", t_c, 0xDF);
        lcd_puts(result);
        free(result);

        sleep_ms(100);
    }

    //------------ TEST AHT10 --------------

    lcd_gotoxy(0, 0);
    lcd_puts("Test            ");
    lcd_gotoxy(1, 0);
    lcd_puts("Weather Station ");
    sleep_ms(1000);

    aht10_t sensor;
    if (!aht10_begin(&sensor))
    {
        while (1)
            tight_loop_contents();
    }

    while (gpio_get(SW_UP))
    {
        for (int i = 0; i < 40; i++)
        {
            if (!gpio_get(SW_UP)){break;}
            display_tmp_and_humid(sensor);
            sleep_ms(100);
        }
        if (!gpio_get(SW_UP)){break;}

        lcd_gotoxy(0, 0);
        lcd_puts("If values look  ");
        lcd_gotoxy(1, 0);
        lcd_puts("ok press up:    ");

        for (int i = 0; i < 10; i++) {
            if (!gpio_get(SW_UP)){break;}
            sleep_ms(100);
        }
    }

    //------------ TEST RGB LED ------------

    lcd_gotoxy(0, 0);
    lcd_puts("TEST RGB LED    ");
    lcd_gotoxy(1, 0);
    lcd_puts("                ");
    sleep_ms(1000);

    gpio_init(RGB_R_PIN);
    gpio_init(RGB_G_PIN);
    gpio_init(RGB_B_PIN);
    gpio_set_dir(RGB_R_PIN, GPIO_OUT);
    gpio_set_dir(RGB_G_PIN, GPIO_OUT);
    gpio_set_dir(RGB_B_PIN, GPIO_OUT);

    // turn red led on
    gpio_put(RGB_R_PIN, true);

    lcd_gotoxy(0, 0);
    lcd_puts("Is led red      ");
    lcd_gotoxy(1, 0);
    lcd_puts("then press up.  ");
    while (gpio_get(SW_UP))
    {
    }
    gpio_put(RGB_R_PIN, false);

    // turn green led on
    gpio_put(RGB_G_PIN, true);
    sleep_ms(1000);
    lcd_gotoxy(0, 0);
    lcd_puts("Is led green    ");
    lcd_gotoxy(1, 0);
    lcd_puts("then press up.  ");
    while (gpio_get(SW_UP))
    {
    }
    gpio_put(RGB_G_PIN, false);

    // turn blue led on
    gpio_put(RGB_B_PIN, true);
    sleep_ms(1000);
    lcd_gotoxy(0, 0);
    lcd_puts("Is led blue     ");
    lcd_gotoxy(1, 0);
    lcd_puts("then press up.  ");
    while (gpio_get(SW_UP))
    {
    }
    gpio_put(RGB_B_PIN, false);

    //-------- CELEBRATION --------

    lcd_gotoxy(0, 0);
    lcd_puts("Congratulations:");
    lcd_gotoxy(1, 0);
    lcd_puts("board is ready! ");

    // goto rainbow routine
    start_rainbow_no_return();
    // this function will never return!!!
}

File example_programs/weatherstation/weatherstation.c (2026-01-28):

#include <stdio.h>
#include <math.h>
#include "pico/stdlib.h"
#include "hardware/pwm.h"
#include "lcd1602.h"
#include "aht10.h"

// RGB Pins (Buzzerino)
#define RGB_R_PIN 20
#define RGB_G_PIN 21
#define RGB_B_PIN 22

// Setze auf 1 wenn deine RGB LED common-anode ist (Farben sonst "falsch"/invertiert)
#define RGB_INVERT 0

static inline float clampf(float x, float a, float b) {
    if (x < a) return a;
    if (x > b) return b;
    return x;
}
static inline float lerp(float a, float b, float t) { return a + (b - a) * t; }

typedef struct {
    uint slice;
    uint chan;
} pwm_pin_t;

static pwm_pin_t pwm_r, pwm_g, pwm_b;

static pwm_pin_t pwm_setup_pin(uint gpio) {
    gpio_set_function(gpio, GPIO_FUNC_PWM);
    uint slice = pwm_gpio_to_slice_num(gpio);
    uint chan  = pwm_gpio_to_channel(gpio);

    pwm_config cfg = pwm_get_default_config();
    pwm_config_set_clkdiv(&cfg, 4.0f);
    pwm_config_set_wrap(&cfg, 65535);
    pwm_init(slice, &cfg, true);

    pwm_pin_t p = {slice, chan};
    return p;
}

static void pwm_write(pwm_pin_t p, uint16_t level) {
    pwm_set_chan_level(p.slice, p.chan, level);
}

static void rgb_set(float r, float g, float b) {
    r = clampf(r, 0.f, 1.f);
    g = clampf(g, 0.f, 1.f);
    b = clampf(b, 0.f, 1.f);

    uint16_t R = (uint16_t)(r * 65535.0f);
    uint16_t G = (uint16_t)(g * 65535.0f);
    uint16_t B = (uint16_t)(b * 65535.0f);

#if RGB_INVERT
    R = 65535 - R; G = 65535 - G; B = 65535 - B;
#endif

    pwm_write(pwm_r, R);
    pwm_write(pwm_g, G);
    pwm_write(pwm_b, B);
}

// ---------- Heat Index (NOAA), Eingabe in °C, RH% ----------
static float heat_index_c(float t_c, float rh) {
    float t_f = t_c * 9.0f/5.0f + 32.0f;
    float R = rh;

    float hi_f =
        -42.379f + 2.04901523f*t_f + 10.14333127f*R
        - 0.22475541f*t_f*R - 0.00683783f*t_f*t_f
        - 0.05481717f*R*R + 0.00122874f*t_f*t_f*R
        + 0.00085282f*t_f*R*R - 0.00000199f*t_f*t_f*R*R;

    return (hi_f - 32.0f) * 5.0f/9.0f;
}

static float feels_like_c(float t_c, float rh) {
    if (t_c >= 27.0f && rh >= 40.0f) return heat_index_c(t_c, rh);
    return t_c;
}

// ---------- Biowetter-Farbskala ----------
static void color_from_feels(float f, float *r, float *g, float *b) {
    // Blau: sehr kalt
    // Grün: moderat
    // Orange/Rot: heiß
    if (f <= 5.0f) { *r=0; *g=0; *b=1; return; }

    if (f < 20.0f) {
        float t = (f - 5.0f) / 15.0f; // 0..1
        *r = 0.0f;
        *g = t;
        *b = 1.0f - t;
        return;
    }

    if (f < 28.0f) { *r=0; *g=1; *b=0; return; }

    if (f < 35.0f) {
        float t = (f - 28.0f) / 7.0f;
        *r = lerp(0.0f, 1.0f, t);
        *g = lerp(1.0f, 0.4f, t); // wird orange
        *b = 0.0f;
        return;
    }

    *r=1; *g=0; *b=0;
}

int main() {
    stdio_init_all();

    lcd_init();
    lcd_gotoxy(0,0); lcd_puts("Bioweather init ");
    lcd_gotoxy(1,0); lcd_puts("AHT10...        ");

    // Sensor init (deine Klasse)
    aht10_t dev;
    if (!aht10_begin(&dev)) {
        lcd_gotoxy(1,0); lcd_puts("AHT10 FAIL      ");
        while (1) tight_loop_contents();
    }

    // RGB PWM init
    pwm_r = pwm_setup_pin(RGB_R_PIN);
    pwm_g = pwm_setup_pin(RGB_G_PIN);
    pwm_b = pwm_setup_pin(RGB_B_PIN);

    while (1) {
        float t = 0.0f, rh = 0.0f;
        if (!aht10_read(&dev, &t, &rh)) {
            lcd_gotoxy(0,0); lcd_puts("AHT10 read FAIL ");
            lcd_gotoxy(1,0); lcd_puts("                ");
            rgb_set(0,0,0);
            sleep_ms(500);
            continue;
        }

        float f = feels_like_c(t, rh);

        float r,g,b;
        color_from_feels(f, &r, &g, &b);
        rgb_set(r,g,b);

        // LCD-Ausgabe
        char l0[17], l1[17];
        // l0: T und RH
        snprintf(l0, sizeof(l0), "T:%4.1f%cC RH:%3.0f%c", t, 0xDF, rh,0x25);
        // l1: feels-like
        snprintf(l1, sizeof(l1), "Feel:%4.1f%cC       ", f, 0xDF);
        l0[16]=0; l1[16]=0;

        lcd_gotoxy(0,0); lcd_puts(l0);
        lcd_gotoxy(1,0); lcd_puts(l1);

        sleep_ms(1000);
    }
}

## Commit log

2025-10-24 Inital commit of bulding instruction and self_test programm as well as schematic and pcb layout files.
    [Buzzerino.kicad_pcb, Buzzerino.kicad_sch]
2025-11-03 Added desription of resistor markings
2026-04-02 Add assembly video and image to README
    Added a video link and image for assembly instructions.
2026-11-05 build all example programs from the Buzzerino root folder
    Add a root CMakeLists.txt (board pico_w) that pulls in every example
    via add_subdirectory, so the Raspberry Pi Pico VS Code extension can
    compile all of them after opening the Buzzerino folder. The example
    CMakeLists now only define their targets; the duplicated
    pico_sdk_import.cmake, .vscode and .gitignore files are replaced by a
    single copy in the root folder.
2026-11-05 blink onboard LED in the program selector menu
    Move the Pico/Pico W LED detection from self_test into a status_led
    module and start it in main(), so the LED blinks from power-up on.
    The selftest app no longer drives GPIO 25 itself, which is the CYW43
    chip select on a Pico W.
